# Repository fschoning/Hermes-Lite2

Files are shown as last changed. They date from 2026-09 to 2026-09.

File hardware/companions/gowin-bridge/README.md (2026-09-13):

# gowin-bridge — Hermes Lite 2 SlimSAS bridge, rev D

**One design with two ends, on one board.** One schematic, one PCB, one BOM,
one project directory. The **radio end** plugs onto the Hermes-Lite 2; the
**Gowin end** plugs onto a Tang Mega 138K dock's J14. They are made together
and snapped apart. Two radio ends and one cable make a radio-to-radio link; a
radio end, a Gowin end and one cable make a radio-to-FPGA link.

The radio end:
A flat companion board that plugs onto the HL2's **DB1** (2×10), **DB12** (2×3)
and **CN1** (2×5 JTAG) headers and carries **one SlimSAS SFF-8654 8i
receptacle** on its front edge. A single $15 cable carries 16 differential
pairs and 16 sideband conductors.

| | |
|---|---|
| Board | radio end **64.50 × 64.88 mm**, 4 layer, 1.6 mm, HASL. HL2 x 70.00→134.50, y 73.37→138.25. The whole board, both ends, is **64.50 × 92.00 mm**, no rails, the ends joined by three mouse-bite tabs |
| Underside | 11.04 mm above the HL2's top surface (10.92 mm measured on the owner's radio), on 2.54 mm sockets and one M3 screw; holes over the radio's FPGA, AD9866 and T2 |
| Connector | Amphenol ICC **U10A474240T**, LCSC **C5432262** |
| Cable | 10Gtek **CAB-8654/8654-8i-P**, 8i to 8i, 0.5 m, **$15** |
| Lane rate | DDR at 153.6 MHz = **307.2 Mbit/s**, three lanes each way |
| Payload | **921.6 Mbit/s** each way = the complete raw 12-bit 76.8 MSPS ADC stream, plus a full-duplex auxiliary channel at the same rate |
| Parts | both ends: 184, of which **152 fitted**; 176 nets; **24 placed part numbers**, 16 Basic, 7 Extended and 1 Preferred Extended; eleven test points |
| Cost | **$162.43** for five assembled boards, both ends, delivered: **$32.49 per complete link** |
| State | schematic generated and validated; **prepared for Quilter**: fixed parts locked, everything else waiting off the board (`QUILTER.md`); **not placed, not routed** |

---

## The documents, and which to read first

| | |
|---|---|
| **`STATUS.md`** | **Start here.** What is built, what changed from rev C and why, the four numbers that were blocking the order, three corrections to the brief, six deliberate departures from it, everything unverified, and the next steps in order |
| `PINMAP.md` | **The pin contract.** Every HL2 header pin, all 74 connector contacts, the crossover, the lane and sideband maps, the AUXIO group, the enables, and the paste-ready Quartus block. Authoritative; `tools/check_netlist.py` asserts it |
| `DESIGN_NOTES.md` | Why, with the numbers. Data rates, the 2.5 V threshold problem and the part that does not exist, termination and edge rates, **the power budget**, **the ESD decision**, the mechanical argument, parts sourcing, the JTAG contention answer, and everything unverified |
| `COST.md` | The order total in the categories the fab actually bills, what could be cut and what it saves, and what is not verified in the numbers |
| `ROUTING.md` | The routing rules for whoever lays this out, in the order they matter |

---

## Files

```
bridge/                 the ONE KiCad project
  bridge.kicad_sch      schematic, ERC 0 violations
  bridge.kicad_pcb      fixed parts locked, the rest staged off the board;
                        placement regions and keepouts; DRC 0, parity 0
  bridge.kicad_pro      project file, with the differentialpair and Power
                        net classes
quilter-upload/         the three KiCad 10 files to upload to Quilter
  bridge-bom.csv        BOM with LCSC numbers and a Populate column
  gowin-bridge.kicad_sym, gowin-bridge.pretty/   project-local libraries
templates/              1:1 print templates for offering up to the radio
panel-endcap/           the re-cut front end panel - SEE THE WARNING BELOW
tools/
  gen_gowin_bridge.py   generates everything above from one netlist description
  check_netlist.py      asserts the pin maps, the crossover and the safety props
  check_geometry.py     asserts the locked parts, the land patterns and,
                        on a returned board, the placement and routing rules
  cost_model.py         computes the order total from the generated BOM and PCB
  kisexp.py             the KiCad s-expression reader/writer
```

**Anything that changes a net must be changed in `tools/gen_gowin_bridge.py`
and regenerated, never hand-edited in the KiCad files, and `PINMAP.md` must be
updated in the same commit.**

## To rebuild and validate

```
cd hardware/companions/gowin-bridge
python tools/gen_gowin_bridge.py
python tools/check_geometry.py     # must print OK
python tools/check_netlist.py      # must print OK
python tools/cost_model.py         # the order total
# bridge/bridge.kicad_dru is picked up by DRC: fast nets 3 mm from every edge

set KC=C:\Users\franz\AppData\Local\Programs\KiCad\10.0\bin\kicad-cli.exe
%KC% sch erc --severity-error -o bridge/bridge-erc.rpt bridge/bridge.kicad_sch
%KC% pcb drc --severity-error --schematic-parity --refill-zones ^
     -o bridge/bridge-drc.rpt bridge/bridge.kicad_pcb
```

---

## The front end panel

`panel-endcap/panel-endcap.kicad_pcb` (55 mm case, rev C) has the SlimSAS
opening at **panel x 120.30–144.30 = HL2 y 107.30–131.30**, centred on the
connector, 24.00 × 10.40 mm at 12.39–22.79 mm above the HL2's top surface.
Nine stock vent holes had to go where the opening landed; nine were put back
above it on 13 Sep 2026, so the vent area is the stock 73.7 mm². Order it
separately as a bare PCB. `G:/proj/Hermes-Lite2/franz-claude-analysis/HL2_END_PANEL.md`
has the derivation, clearances and strength check.

**Not compatible:** the repo's DB9 adapter board (`hardware/companions/db9/`)
cannot be fitted with this board; its wires land on DB1 pins our socket
covers. Run a Hardrock-50 from the N2ADR HL2 IO board instead
(`DESIGN_NOTES.md` §14.7).

## The Gowin end

A passive board: the same SlimSAS connector, 12 ESD arrays, 9 resistors and a
hand-fitted 2×18 onto J14 positions 5–40. Bank 4 of the Gowin FPGA drives and
receives true LVDS at its 3.3 V supply. Placed at the 40 mm case position.
`PINMAP.md` §11, `DESIGN_NOTES.md` §11, `gowin_end_j14.cst`.

## To order

JLCPCB, **Economic** assembly, **5 boards**, 4 layer, 1.6 mm, lead-free HASL,
green, 1 oz, delivered as a single PCB with the tabs unbroken. It is one
64.50 × 92.00 mm board with one outline and no rails; the two ends are joined
by three mouse-bite tabs. Ask JLCPCB first whether that counts as one design
(`DESIGN_NOTES.md` §13.2). Do not buy impedance control — `COST.md` §4 explains why.
`COST.md` §1 is the line-by-line.

Then hand-solder, per board: the DB1 2×10 socket and the DB12 2×3 socket and
the CN1 2×5 socket on the **underside**, the JTAG pass-through 2×5 header on
the **top**, and **the connector's four 2.2 mm shell tails**.

**Before any of that, buy one cable and ohmmeter it.** The whole one-design
argument rests on the cable crossing row A onto row B, and 10Gtek publish no
wiring diagram for this part. `STATUS.md` has the test.

**And do not fit or remove the board with the radio powered** — the hot-plug
inrush is about 22 A for 3.3 µs. It is on the silkscreen.

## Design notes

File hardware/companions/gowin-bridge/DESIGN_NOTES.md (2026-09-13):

# gowin-bridge design notes, rev D

Why the design is the way it is, with the numbers. `PINMAP.md` is the pin
contract; this is the reasoning. **One design with two ends on one board**:
the radio end (sections 1-10) and the Gowin end (section 11). One schematic,
one PCB, one BOM. rev C's three HDMI cables and riser are in git history.

---

## 1. Data rates and unit intervals

| | Value |
|---|---|
| AD9866 sample rate | 76.8 MSPS, 12 bits |
| Raw stream | **921.6 Mbit/s** |
| Lanes per direction | 3 data + 1 clock |
| Lane rate | DDR at 153.6 MHz = **307.2 Mbit/s** |
| Unit interval | **3.2552 ns** |
| Both directions | simultaneously, on their own forwarded clocks |
| Auxiliary channel | one more clock and one more data lane each way, also 307.2 Mbit/s, also simultaneously |
| Driver rating | DS90LV047A fMAX 200 MHz min / 250 MHz typ, i.e. 400 Mbit/s — **77 % of rating** |
| Translator rating | SN74AVC4T245 380 Mbit/s at these rails — **81 % of rating** |
| LVDS transition time | about 1 ns, so **31 % of a unit interval** |

Both the 77 % and the 81 % are worth a scope check at bring-up. They are
unchanged from rev C, because rev C already ran every lane at this rate.

### 1.1 What is still unverified about the rate

Whether the Cyclone IV C8 fabric can capture 307.2 Mbit/s DDR on ordinary
bank-6 inputs. The device has one input register per IOE, so DDR input needs
soft logic clocked at 153.6 MHz. This gates every received lane. It is a
gateware and timing-closure question, not a board question, and no board change
can fix it if the answer is no.

---

## 2. The 2.5 V threshold, and the part that does not exist

### 2.1 The problem, with the numbers

| | Value | Source |
|---|---|---|
| Cyclone IV 2.5 V output, VOH min | **2.0 V** at IOH = −1 mA | Cyclone IV Device Datasheet CYIV-53001-1.8, Table 1-15 |
| DS90LV047A input VIH min | **2.0 V** | TI SNLS044D, Electrical Characteristics |
| **Guaranteed margin** | **0 mV** | |

Every 2.5 V-bank signal that originates at the HL2 and has to reach an LVDS
driver hits this: the three ADC data lanes and the auxiliary transmit pair.
It is the main signal path, not an edge case.

### 2.2 The 2.5 V LVDS driver was looked for properly. It does not exist.

The obvious fix is to power the LVDS driver from 2.5 V, whereupon its input
threshold would become about 0.7 × VCC = 1.75 V and the HL2's guaranteed 2.0 V
would have 250 mV of margin with no translator at all. That would delete three
chips and a divider. It was chased before anything else was decided.

**There is no quad CMOS-in / LVDS-out driver and no quad LVDS-in / CMOS-out
receiver specified from a 2.5 V supply, from any manufacturer, in any package,
at any price, that can be bought.** Two reasons:

1. Every quad LVDS line driver and receiver ever made runs 3.0–3.6 V. All 253
   parts in LCSC's LVDS category were swept; **not one has a supply range
   starting below 3.0 V.**
2. **Lowering the supply would not lower the threshold anyway.** These parts
   specify VIH = 2.0 V and VIL = 0.8 V as absolute TTL levels, not as a
   fraction of VCC. TI's own application note **SNLA307** exists to say so:
   "most LVDS drivers and receivers available on the market have 3.3-V supplies
   and only support 3.3-V LVTTL/LVCMOS signals", and its recommended fix is
   exactly a `SN74AVCxx45` translator in front of a 3.3 V driver.

Parts that genuinely are specified at 2.5 V, and why none of them helps:

| Part | What it is | Why not |
|---|---|---|
| TI SN65LVDS1 | single driver, 2.4–3.6 V, real 2.5 V spec | **VIH still 2.0 V.** Buys nothing. Four of them cost more than one quad plus a translator, in four times the area |
| TI SN65LVDS2 | single receiver, 2.4–3.6 V | single channel |
| TI SN65LVDS4 | single receiver with a separate 1.8/2.5/3.3 V output supply, fully specified at VCC = 2.5 V | single channel, and LCSC holds 34 pieces |
| TI CDCLVD1204 | fully 2.375–2.625 V | needs an external threshold reference on a complementary pin, i.e. the resistor divider this was meant to remove |
| ST RHFLVDS41 | **a real 2.3–3.6 V quad LVDS driver, announced February 2026** | space-qualified, ceramic Flat-16, QML-V, four-figure unit price, months of lead time, no distributor. It exists; you cannot have it |
| TI SN75LVDS83B | the only catalogue LVDS transmitter with a **guaranteed 1.65 V** input threshold, from a separate IOVCC pin (SLLS846C table 7.3) | it is a 28-bit 7:1 serializer, not a 4-channel driver, and −10 to +70 °C |

Also checked and all 3.0–3.6 V with 2.0 V thresholds: SN65LVDS047/048,
SN65LVDS31/32, SN65LVDS3486/3487, SN65LVDS9637/9638, SN65LVDS389/388A,
SN65MLVD, DS90LV031A/032A, DS90LV011A/012A, DS90LV004, the whole onsemi FIN
family (FIN1027/1028/1031/1032/1047/1048/1101/1102/1108, titled "3.3 V LVDS"),
ADI ADN4661–4668 and ADN4696/4697, Maxim MAX9111/9112/9121–9124/9173–9176,
Pericom PI90LV047/048, ROHM BU90LV047A/048, ST STLVDS47B, Runic RS90LV047,
Relmon MS90C032/385B/386B, 3PEAK TPT9H221, LKI8010/8011/8012. Renesas/IDT's
2.375–2.625 V parts are clock fanout buffers with differential inputs, not
CMOS-to-LVDS drivers. LTC1685/1686 are 5 V RS-485 parts, not LVDS.

### 2.3 So the translator stays, and what it costs

**U1 and U2 are SN74AVC4T245PW (LCSC C81461), VCCA = 2.5 V, VCCB = 3.3 V, both
DIR tied to VCCA, both OE* to ground.**

| | Value |
|---|---|
| A-side VIH min | **0.65 × VCCA** |
| At VCCA = 2.5 V nominal | 1.63 V → **370 mV of margin** over the HL2's 2.0 V |
| At VCCA = 2.55 V, the LDO's +2 % corner | 1.66 V → **340 mV**, the number to design to |
| At VCCA = 2.375 V | 1.54 V → 460 mV |
| B-side output | 3.3 V CMOS into the driver's 2.0 V threshold, 1.3 V of margin |
| Rated data rate | 380 Mbit/s; fastest signal through it 307.2 Mbit/s = **81 %** |
| Propagation delay | about 0.1 to 2.9 ns over the process and temperature table |
| Quiescent | ICCA and ICCB **8 µA max each** |

**The forward clock goes through the same package as its three data lanes.**
That is U1: four channels, exactly the forward group, nothing else. Propagation
delay is a part-to-part property, so putting them in one package turns a 2.6 ns
part-to-part uncertainty into a channel-to-channel one. The auxiliary clock and
data share U2's port 1 for the same reason.

**The forward clock is the awkward one, because FPGA pin 98 is a 3.3 V bank pin
and the translator's A-side absolute maximum is VCCA + 0.5 V = 3.0 V.** It
arrives through a divider:

| | Value |
|---|---|
| Divider | **100 Ω series + 470 Ω shunt**, both JLCPCB Basic parts |
| High level | 3.3 × 470/(470+100+50) = **2.50 V** |
| Worst corner (3.465 V rail, 2.45 V VCCA → 2.95 V absolute max) | 2.63 V — **320 mV of headroom** |
| Margin over VIH 1.63 V | **870 mV** |
| Current from pin 98 | 3.3 / 570 = **5.8 mA**, so set that pin to its 8 mA drive strength |
| Thevenin impedance | 100 ∥ 470 + 50 = **132 Ω** |
| Edge into the translator's ~4 pF | **0.53 ns** |
| Low level with the HL2 FPGA unconfigured | pin 98 carries LED D2 and R71, 1 kΩ to +3V3, so it sits at 1.4 V behind 1 kΩ: 1.4 × 470/1570 = **0.42 V** against the 0.875 V VIL limit |

rev C used 100 Ω + 660 Ω as two 330 Ω resistors because 470 Ω was not then a
Basic part in JLCPCB's library. It is now (**C25117**), so this is one resistor
instead of two, with better margin at every corner and 130 mV more headroom
under the absolute maximum.

**Pull-downs.** Every 2.5 V-bank net into U1 and U2 gets a 10 kΩ pull-down so
it is defined while nothing drives it. **The forward clock deliberately does
not**: its own LED pull-up plus the divider already define it at 0.42 V, and
adding 10 kΩ would park the node in the translator's forbidden band between
VIL 0.875 V and VIH 1.63 V.

### 2.4 And the other direction: 3.3 V into the HL2's 2.5 V input-only pins

HL2 PIN_88 (DB12-6), PIN_89 (DB12-5) and PIN_87 (DB12-2) are in a 2.5 V bank
with the PCI clamp diode on by default, and 88 and 89 are input-only. A 3.3 V
driver held high would inject DC into the radio's 2.5 V rail. **U3 is a third
SN74AVC4T245 with VCCA = 3.3 V and VCCB = 2.5 V**, carrying the two candidate
reverse clocks in port 1 and the auxiliary receive pair in port 2.

A resistor divider was rejected on the same numbers as in rev C: DS90LV048A
specifies VOH only to 2.7 V at −0.4 mA and VOL 0.25 V at 2 mA, so it cannot
drive a divider light enough to resolve a 3.2552 ns unit interval.

**The three transmit data lanes need no translation** — DB1 pins 11, 15 and 17
are 3.3 V-bank pins — so the receiver output drives them through a 0 Ω link on
0402 pads, with 22 Ω available if damping ever helps.

### 2.5 The option that would delete all three translators, for the record

The Cyclone IV can drive true LVDS on the output pins of its row I/O banks and
emulated LVDS (three external resistors) anywhere, with VCCIO = 2.5 V, which
these banks already run at. That deletes both the translators and the driver
chips. It needs the pins brought out to DB1 and DB12 to be assignable as
adjacent differential pairs, and they are not: 76, 77, 83, 85, 86 and 98 are
scattered across two banks and two headers. Recorded so nobody has to
rediscover it. rev C's `PINMAP.md` §5.3 examined the same idea.

---

## 3. Termination, edge rates and the tight paths

* **Every received pair gets a 100 Ω differential resistor**, eight in all,
  **within 5 mm of the receiver pins**. There is no termination at a driver
  output, which is correct for LVDS.
* **LVDS swing** 250–450 mV (VOD1 into 100 Ω), common mode 1.125–1.375 V.
* **The cable is not the limit.** SFF-8654 8i cable is **twinax** construction,
  32 AWG, 100 Ω, qualified to 24 Gb/s per channel for SAS-4. 307.2 Mbit/s is
  two orders of magnitude below that. The 400 Mbit/s driver rating is the
  limit, not the cable, and a metre is fine.
  **On the word "unshielded":** the phrase that appears on cable listings comes
  from the connector standard's own title, *0.6mm 4/8X **Unshielded** I/O
  Connector*, and from Amphenol's own connector page — "Designed for
  unshielded, internal or external I/O connectors". It describes a connector
  with no metal shroud, not a cable with no shield. 3M's equivalent product is
  literally named "SlimLine **Twin Axial** Cable Assembly (SFF-8654)", and
  10Gtek's own family datasheet is titled "SAS Slimeline **Twinax** Cable".
  What is **not** confirmable from any openable document is the layer-by-layer
  shield stack-up — foil per pair versus overall foil plus braid, and the
  drain-wire count. If a formal EMC case ever needs that, ask 10Gtek or cut one
  open.
* **Every single-ended HL2 net is under 25 mm** by layout rule. The floor plan
  in section 6 is built around that.
* **Impedance:** the connector is specified 85 Ω ±10 differential and the
  chosen cable SKU is 100 Ω. An 85/100 mismatch is a 8 % reflection
  coefficient, which at 307.2 Mbit/s is irrelevant. JLCPCB Economic gives no
  impedance guarantee, so aim the board for 100 Ω differential and accept it.

### 3.1 Tight path one: the three transmit lanes into the HL2's LED pins

DB1 pins 11, 15 and 17 are FPGA pins 99, 100 and 101, and each carries an LED
whose anode goes through 1 kΩ to +3V3 (D3/R72, D4/R73, D5/R74, verified in
`hermeslite.net`).

* **The receiver must sink 1.4 mA** when low: (3.3 − 1.9)/1000. DS90LV048A
  specifies VOL ≤ 0.25 V at IOL = 2 mA, so it is inside spec with the LED lit.
* **The LED does not load the edge.** Its junction capacitance (20–50 pF) is in
  *series* with the 1 kΩ, so at 150 MHz that branch is resistive. What loads
  the edge is the FPGA pin (about 7 pF for a right-side Cyclone IV pin) plus
  the header and trace, roughly 12–15 pF.
* A 3.3 V CMOS output with about 50 Ω of effective source impedance into 15 pF
  gives a 10–90 % rise of about **1.65 ns, which is 51 % of the unit
  interval.** That works, and it is the tightest margin on the board.
* The series parts are **0 Ω by default on 0402 pads**, so a damping value can
  be substituted without a respin — but do not raise them much: at 22 Ω the
  rise grows to about 1.9 ns.

### 3.2 Tight path two: nothing, and that is the change from rev C

rev C's second tight path was FPGA pin 80, the VREF pin with ~21 pF of stray
capacitance, carrying a bidirectional auxiliary lane at 1.49 ns of edge. In
rev D pin 80 carries a **DC enable level** and nothing else, so the 21 pF is
irrelevant and the path is gone. Pin 72, whose uFL stub at CL8 and unadjustable
sampling phase were the other worry, likewise carries only a DC level.

---

## 4. Power. This is the number that was blocking the order.

### 4.1 What the board draws

Every figure below is either a datasheet maximum or a computed
`I = (Cpd + CL) × V × f`. Where a datasheet publishes no guaranteed number, it
says so.

**On the 3.3 V rail:**

| Load | Current | Where it comes from |
|---|---|---|
| U4, U5 — two DS90LV047A quad drivers | **80 mA** (40 each) | SNLS044D: ICC no load 8 mA max, ICC loaded static (RL = 100 Ω on all four) **30 mA max**. TI publishes **no guaranteed switching ICC** — only Figure 24, whose "All Switching" curve rises to about 35–38 mA. 40 mA is the design figure and it is above the only guaranteed number there is |
| U6, U7 — two DS90LV048A quad receivers | **80 mA** (40 each) | SNLS045C: ICC no load 15 mA max; four outputs into ~10 pF at 153.6 MHz add 4 × 10p × 3.3 × 153.6M = 20 mA. Again no guaranteed switching ICC, only Figure 21 at about 40 mA |
| U1 — forward group translator, B side | **47 mA** | 4 channels × (CpdB 15 pF + 8 pF of load) × 3.3 V × 153.6 MHz. Cpd from SCES576I Table 5.6 |
| U2 — auxiliary translator, B side | **23 mA** | 2 switching channels, same arithmetic. The two enable channels are static |
| U3 — reverse translator, A side | **4 mA** | 4 channels × CpdA 2 pF × 3.3 V × 153.6 MHz |
| U8–U11 — the AUXIO and JTAG buffers | **12 mA** | dominated by TCK at 24 MHz, and only while programming; the AUXIO lines are DC to 400 kHz |
| The whole 2.5 V rail, through U12 | **50 mA** | see below. An LDO passes its output current straight through |
| Presence assert, 1 kΩ | **0.3 mA** | |
| Pull-ups, pull-downs, the divider | **3 mA** | |
| Quiescent: 7 × SN74AVC4T245 at 8 µA, U12 at 40 µA, 12 ESD arrays | **<0.1 mA** | |
| **Total** | **299 mA** | |
| **Design figure** | **350 mA** | |

**On the 2.5 V rail, which the board makes itself:**

| Load | Current |
|---|---|
| U3 B side: three switching channels × (CpdB 14 pF + 12 pF of HL2 pin and trace) × 2.5 V × 153.6 MHz | **30 mA** |
| U3 B side: the duplicate-clock channel driving an open pad (~3 pF) | **6.5 mA** |
| U1 A side: 4 × CpdA 2 pF × 2.5 V × 153.6 MHz | **3.1 mA** |
| U2 A side: 2 switching channels | **1.5 mA** |
| **Total** | **41 mA** |
| **Design figure** | **50 mA** |

### 4.2 What the radio can actually spare

Traced through `hardware/hl/Power.sch`, `hermeslite.net` and
`hermeslite.kicad_pcb` on schematic revision **2.0-build9**.

**+3V3 — one regulator for the whole radio.**

| | |
|---|---|
| Regulator | **U3, ST1S10PHR** synchronous buck, HSOP-8, **no heatsink** (the only two heatsinks on the radio are HS2 on the FPGA and HS7 on the AD9866) |
| Input | VSUP, 11–16 V, after the 3 A PTC fuse F1 and reverse-polarity FET Q1 |
| Chip rating | **3.0 A** |
| Output inductor | **L1, SRR4528A-3R3Y, rated 2.4 A** — the real hardware ceiling |
| Set point | R11 35.7 k / R12 11.5 k → 0.8 × (1 + 35.7/11.5) = **3.28 V** |
| **The designer's own annotation beside it on Power.sch** | **"<=1.5A"** |
| There is **no second 3.3 V regulator** | the Ethernet PHY and the FPGA share this one |

Existing load on it, bottom-up. The four largest are estimates and are labelled
as such:

| Consumer | Current | Basis |
|---|---|---|
| U7 AD9866 codec, all four 3.3 V domains (via FB17–FB20) | 150 mA | **estimate** from its ~0.4–0.6 W class at 76.8 MHz |
| U4 KSZ9031RNX PHY, AVDDH (via FB10) | 60 mA at 1 Gb | **estimate** |
| FPGA VCCIO banks 1, 2, 6, 7, 8 | 45 mA | **estimate**, dominated by the AD9866 DDR bus |
| U6 5P49V5923 VersaClock (via FB23–FB26) | 50 mA | **estimate** |
| X2 38.4 MHz oscillator (via FB12) | 15 mA | estimate |
| U17 TPS73025, i.e. the whole 2.5 V rail | 100 mA | see below |
| Magjack LEDs, R133/R134 = 270 Ω | 9.6 mA | **calculated** |
| Front-panel LEDs D2–D5, R71–R74 = 1 kΩ | 5 mA all on | **calculated** |
| Flash, MAX11613, MCP4662, MCP9700, PE4259, pull-ups | 8 mA | estimate |
| K2 TR relay coil | **0 mA** — PA.sch says the assembly house does not fit it | |
| **Total** | **≈ 450 mA** (range 350–600) | |

| Against | Spare |
|---|---|
| the ST1S10's 3.0 A | 2.55 A |
| L1's 2.4 A | 1.95 A |
| **the designer's own 1.5 A note** | **≈ 1.05 A** ← use this one |

**This board's 350 mA is 33 % of that spare.** Even at the pessimistic 600 mA
of existing load the spare is 900 mA and the board is 39 % of it. The rail
total becomes about 800 mA against a 2.4 A inductor.

**The copper is not the limit either.** DB1 pins 19/20 have **no series element
whatever** — no bead, no resistor, no fuse, no TVS — between L1 and the header.
The narrowest segment of that path is **1.25 mm on an external layer with no
plane** (+3V3 has no zone anywhere on the 4-layer radio), which IPC-2221 puts
at **2.8 A at a 10 °C rise**. One 0.5 mm via in the path is worth 2–2.5 A.

**2.5 V — and this is why the board makes its own.**

| | |
|---|---|
| Regulator | **U17, TPS73025DBVR**, a fixed 2.5 V LDO in **SOT-23-5**, fed from +3V3 |
| Rating | **200 mA total** |
| **The designer's own note** | **"150 mA sufficient for all 2.5V use"** |
| What it already feeds | FPGA VCCA1–VCCA4 (the four PLL supplies, via FB5–FB8) ≈ 12 mA; **net Veth** via FB30 = the KSZ9031's DVDDH RGMII I/O supply plus FPGA VCCIO banks 3 and 4 ≈ 55 mA at 125 MHz DDR; **net Vlvds** via FB28 = FPGA VCCIO **bank 5** plus DB1 pins 7/8 ≈ 8 mA; and FPGA pin 96, the MSEL1 configuration strap |
| Existing total | **≈ 75 mA** (range 45–135), every component of which is an estimate |
| Spare | **50 mA safely, 100 mA plausibly, 125 mA as an absolute ceiling** |
| FB28, the bead in the DB1 path | **TDK MPZ1608S601ATA00**, 600 Ω at 100 MHz, **1 A**, ≤200 mΩ. Not the limit — the 200 mA LDO binds first. What it does cost: every milliamp the board takes drops across 200 mΩ on the **shared** side, pulling down the FPGA's own VCCIO5 |
| Copper from FB28 to DB1 7/8 | 0.7 mm on B.Cu, ~19 mm, no vias → 1.85 A at a 10 °C rise. Not the limit |

**Verdict: fit the on-board LDO.** This board's 50 mA is the *whole* of the
radio's conservative 2.5 V headroom, that headroom figure is a bottom-up
estimate with wide error bars, and the rail it would brown out is **VCCIO5, the
bank that carries the ADC data this board exists to read**. So:

* **U12, ME6211C25M5G-N (LCSC C194395), 2.5 V 400 mA LDO, FITTED.** Fed from
  the board's own +3V3. 0.8 V of drop × 50 mA = **40 mW**, and 8× of current
  headroom. Output tolerance ±2 %, which is where the 340 mV threshold margin
  in section 2.3 comes from.
* **`SL_VLVDS` and `FB2`, NOT FITTED**, are the alternative: tie the 2.5 V side
  to the radio's own Vlvds instead. Electrically ideal, because the thresholds
  then track the FPGA bank supply exactly. Do not fit them together with U12.
  Measure Vlvds under load before trusting it.

It costs $3.07 in a feeder fee and six cents in silicon. That is cheap
insurance against browning out the rail you are reading.

**There is no 5 V, 12 V or unregulated supply on DB1 or DB12.** DB1 offers only
+3V3 (pins 19/20), 2.5 V (7/8) and ground (13/14); DB12 offers ground (3/4) and
four signals and no power at all. Raw power exists only on DB7, the filter-board
edge header, which this board does not reach.

**There is no published limit on what an expansion board may draw from DB1.**
Searched every schematic text note, the Sphinx documentation dump and every
`.md` in the repository. The only numbers the design offers are the two Power.sch
annotations quoted above. For what it is worth, KF7O's own unreleased DB1
companion (`hardware/companions/io/io.sch`) carries the note "Optional
Regulator for 5-11V", i.e. it provisioned its own supply rather than living off
the header.

### 4.3 Inrush, and the one thing not to do

Bulk capacitance is deliberately modest — **10 µF per rail and no more**.

| | |
|---|---|
| Total on the 3.3 V side | 10 µF after FB1 + 10 µF before it + ~1.7 µF of 100 nF = **21.7 µF** |
| Total on the 2.5 V side, behind the LDO | 10 µF + 1 µF + ~0.5 µF = **11.5 µF** |
| **At power-up**, with the radio's ST1S10 soft-starting over about 1 ms | I = C dV/dt = 21.7 µF × 3.3 V / 1 ms = **72 mA** of charging current on top of the load. Nothing |
| **On hot plug**, inserting the board with the radio running | 3.3 V / (FB1's 50 mΩ + about 100 mΩ of trace and contact) = **about 22 A**, decaying with τ = 0.15 Ω × 21.7 µF = **3.3 µs**, total charge 72 µC |

**Do not fit or remove the board with the radio powered.** It is on the
silkscreen. That 22 A microsecond spike would dip the radio's 3.3 V rail, and
it is also why the bulk ahead of the filter is 10 µF and not 100 µF.

**Since 13 Sep 2026** a 100 µF tantalum (C29) sits on +3V3 **behind** the new
4.7 µH inductor L1 (§14.4). The inductor limits its charging to 0.7 A per
microsecond and its own 1.7 Ω ESR damps the rest, so the hot-plug spike above,
into the 10.1 µF ahead of FB1, is unchanged.

**FB1, BLM18PG121SN1D (LCSC C14709), 0603, 120 Ω at 100 MHz, 2 A, 50 mΩ**,
sits in the 3.3 V feed and drops **15 mV at 300 mA**. It keeps this board's
switching currents out of a rail that has no filtering of its own between the
regulator and the header. It is JLCPCB **Basic**, which matters: it is the only
Basic bead that combines ≥1 A with ≤150 mΩ. No Basic bead reaches 600 Ω at that
current, and 120 Ω is ample for a rail filter — the whole Basic range is four
parts and the other three fail on current or DC resistance.

---

## 5. ESD. Every conductor that leaves the enclosure.

**Decision: protect all of them.** 32 pair conductors plus all 16 sideband
conductors = **48**, in twelve 4-channel arrays.

| | |
|---|---|
| Part | **TPD4E05U06DQAR**, LCSC **C138714** |
| Capacitance | **0.5 pF per channel** |
| Standoff / clamp | 5.5 V / 6.5 V, unidirectional — right for 3.3 V logic and for LVDS at a 1.2 V common mode |
| Package | USON-10, 2.5 × 1.0 mm |
| Stock / price | 45,345 at LCSC, **$0.0698 at qty 10**, JLCPCB Extended |
| Count | **12 arrays**, 48 channels, 2 spare |
| Cost | **$0.84 per board** plus one $3.07 feeder fee |
| **Electrical cost** | 0.5 pF × 50 Ω = **25 ps** of added rise time on a 3.2552 ns unit interval, i.e. **0.8 %**. Free |

Placement rule: **within 5 mm of the SlimSAS contacts, on the connector side of
the terminations, the series resistors and the buffers, with the shortest
possible ground return.**

Why not something cheaper or bigger:

* **No ESD array of any channel count is Basic tier** in JLCPCB's library. The
  entire Basic TVS range is four SMA/SMB power diodes with 5–12 V standoff and
  unpublished (i.e. 100 pF class) capacitance. They would not clamp a 3.3 V
  line and would destroy a 307 Mbit/s lane.
* **The 6- and 8-channel parts are worse on every axis.** TPD6E004 is 1.6 pF
  per channel and TPD8E003 is **9 pF** — three to eighteen times over budget —
  and the 8-channel part costs 25 times more per conductor and has 61 pieces in
  stock.
* **SRV05-4 (C558418)** at $0.0248 would be the cheapest 4-channel option, but
  its I/O-to-ground capacitance is **0.8 pF**, over the 0.5 pF limit, and the
  in-stock part is a clone with 20 V clamping rather than the brand-name part's.
* **SP3012-04UTG (C2987148)**, 0.3 pF, DFN2510-10, $0.0388, is the better part
  on both capacitance and price and is recorded as the alternative. It was not
  taken because LCSC holds 4,021 against C138714's 45,345 and C138714 is
  already proven in this BOM.

---

## 6. Mechanical: the outline, and why the connector is not in front of DB1

### 6.1 The new outline

| | |
|---|---|
| Outline | **local x 0…64.50, y 0.07…64.95 = HL2 x 70.00…134.50, y 73.37…138.25** |
| Size | **64.50 × 64.88 mm**, 4 layers, 1.6 mm, HASL. The 0.07 mm off the HL2 y 73.30 edge was taken when the board had rails and had to fit 100.00 mm (§11.6); local coordinates are unchanged |
| Local origin | HL2 main-board (70.00, 73.30), so local x = HL2 x − 70.00 |
| Underside | **11.04 mm** above the HL2's top surface with the specified socket, top surface at 12.64 mm. **Measured 10.92 mm** with the socket on the owner's radio (§13.4) |
| Window in the board | **local x 43.30…57.00, y 39.50…53.00**, widened 13 Sep 2026 so HL2 jumper header DB6 is uncovered with 2.5 mm clear on every side (§13.3). It is part of one cut-out with the holes over the AD9866 and T2 (§13.1) |
| M3 anchor | a **3.4 mm U-notch open to the top edge**, centred on local x 3.00 |
| Locating peg | **1.1 mm unplated hole at local (4.04, 2.12)** = HL2 MH6 (74.04, 75.42) |

**Confirmed from `hermeslite.kicad_pcb`:** the board must reach **x = 134.50**
because CN1's two pad columns are at HL2 x **128.23 and 130.77** with a 1.85 mm
pad, i.e. copper to 131.70, plus the socket body. It may reach **y = 138.25**
and no further, because `HL2_MECHANICAL_ENVELOPE.md` §2.5 puts the extrusion's
internal clear width at HL2 y 41.75…138.25. And `HL2_MECHANICAL_ENVELOPE.md`
§12.4 confirms the corridor is clean: apart from CN1 itself at 8.54 mm, the
tallest thing in 54 mm of board between x 73 and 136 at y 75…100 is the FPGA at
1.60 mm.

**The M3 anchor had to become a notch.** HL2 MH2 sits at (73.00, 137.00) =
local (3.00, 63.70), only **1.25 mm** from the top edge, and the top edge
cannot move. A 3.2 mm hole centred 1.25 mm from an edge breaks out of it by
0.35 mm. So the screw passes through a U-notch instead: the screw head and
washer still clamp the board onto the 11.04 mm standoff, and with the connector
lying flat there is almost no tipping moment for it to resist anyway.
`check_geometry.py` recomputes the 1.25 mm and fails if it ever becomes big
enough for a plain hole.

**MH6, the 1 mm locating peg, is available in rev D and was not in rev C.**
With the connector moved away from that corner there is nothing in the way.

### 6.2 Why the connector moved along the front edge, and this is a hard finding

The obvious place for the receptacle is the middle of the front edge, inside
the 29.60 mm of panel that is free at board level (HL2 y 72.86…102.44, bounded
by the magjack and the clock SMAs). **It cannot go there.**

A right-angle SFF-8654 receptacle lands its contact pads **12.35 to 15.35 mm**
inboard of the board edge and its four shell tails **1.65 to 8.15 mm** inboard.
And in that y span:

* **DB12's six through-holes are at local x 13.50 and 16.04** — straight through
  the middle of a 0.60 mm pitch pad field.
* **DB1's twenty holes are at local x 4.04 and 6.58**, which collide with the
  shell tails: the tail column at x 5.15 is only 1.11 mm from DB1's x = 4.04
  column, and the tails' 23.26 mm span is not commensurate with DB1's 2.54 mm
  pitch, so no y offset clears both tails at once.

**No setback fixes it.** Pushing the connector inboard far enough to clear both
hole columns needs ≥ 16.4 mm, which puts the mating face about 6 mm behind the
panel where no plug can reach it.

**So the connector moves along the edge to local y 46.00 = HL2 y 119.30**, past
the far end of DB1. That works because **the panel opens out with height**:
§2.4 and §11.3 give 29.60 mm of clear width at board level but the full
96.50 mm of the extrusion's internal width above about 14 mm, and a connector
standing on this board's 12.64 mm top surface occupies **12.64 to 22.54 mm**
above the main board — entirely inside that band, and **above** the existing
clock-SMA and KEY-jack holes rather than beside them.

| | |
|---|---|
| Receptacle | local y 34.25…57.75 = **HL2 y 107.55…131.05** |
| Mated plug overmould, 25.95 mm (SFF-8654 Table 5-1, A03) | **HL2 y 106.33…132.28** |
| Against the extrusion's clear width 41.75…138.25 | **64.58 mm spare below, 5.97 mm above** |
| Plug thickness, 9.90 mm (Table 5-1, A13) | 12.64…22.54 mm above the main board |
| **Panel window** | **26.5 × 10.5 mm**, centred on HL2 y 119.30, from **19.6 to 30.2 mm above the enclosure's outer bottom face** (the PCB top surface is 7.30 mm up) |

What is underneath at that y: the two clock SMAs (CL1/CL2, HL2 x
74.04…78.24, y 103.36…123.60) and the 3.5 mm KEY jack (CN4, x 70.20…82.10, y
124.00…136.00). **Measured on the owner's radio at 4.24 mm and 5.12 mm**
(§13.4), so the 10.92 mm underside clears them by 6.68 and 5.80 mm.

**The floor plan this produces is better than rev C's, not worse.** The
translators and LVDS chips sit in local x 9…53, y 12…34, right beside DB1 and
DB12, so every single-ended HL2 net stays well inside §11.6's 25 mm rule; the
only long runs are the terminated 100 Ω differential pairs from the chips up to
the connector at y 34…58, about 25–35 mm over an unbroken ground plane, which
do not care.

### 6.3 What the flat board buys over rev C

| | rev C | rev D |
|---|---|---|
| Connectors for 12+ pairs | 3 × mini HDMI | **1** |
| Boot envelope required | 3 × 17.4 = 52.1 mm | **25.95 mm** |
| Upright riser section | required, 8–28 mm tall, right-angle soldered joint | **none** |
| Socket shell centre height | 22.0 mm | ~17.6 mm, and the board is flat |
| Insertion force | 44.1 N at a 22 mm shell height = 970 N·mm of tipping moment | **55.5 N** at a ~2.6 mm shell height, near zero moment |
| Designs to fabricate | 2, plus a panel | **1** |
| Mating cycles | 10,000 (HDMI) | **250 minimum** (Amphenol U10 series) |

That last row is the one real regression and the owner should know it in
advance: SlimSAS is a server-internal connector. 250 cycles is about one
insertion a week for five years, which is almost certainly fine for a radio,
but it is not a consumer port.

### 6.4 The land pattern, and the one dimension nobody publishes

Amphenol publish no recommended land pattern for U10A474240T and their
datasheet server refuses automated fetching, so the footprint is built from the
governing specification's own informative footprint: **SFF-8654 Rev 1.2 Figure
A-1 and Table A-1, "8X RIGHT ANGLE RECEPTACLE FOOTPRINT DIMENSIONS"**. Every
designator J01 to J12 is transcribed in the `SLIMSAS` block in
`tools/gen_gowin_bridge.py`, and `tools/check_geometry.py` recomputes all 78
pads from those twelve numbers independently and compares. Cross-checked
against **Foxconn customer drawing 303-0000-3299 sheet 4/5**, the "RECOMMEND
PCB LAYOUT" view for the 38-position sibling of the same LDL family, which
prints the identical construction and confirms that the shell tails sit
*outside* the locating holes and on the opposite side of the datum line from
the contacts.

**The one dimension that is in no document I could read** is the distance from
the locating-hole datum line to the front face of the latch shroud — i.e. how
far back the footprint must sit for the mating face to be flush with the panel.
Derived instead: the footprint spans 9.10 mm on the shell-tail side and 5.70 mm
on the pad side, 14.80 mm total, against a 15.80 mm body depth, so the body
overhangs the footprint by about 1.00 mm and the front face is about 10.10 mm
ahead of the datum. **The setback is set to 10.40 mm**, which puts the nominal
front face 0.30 mm behind the board edge and leaves 1.75 mm of copper-to-edge
clearance on the shell-tail pads. A 0.5 mm error here is absorbed by the panel
window, which is clearance-only and which the owner cuts himself — but
**check it against Amphenol's drawing before cutting the panel.**

---

## 7. Parts sourcing

**Every number was checked against a live LCSC page and against JLCPCB's
assembly library.** Eighteen part numbers are placed; twelve are Basic and six
are Extended.

| Function | Part | LCSC | Tier | Qty | $ @10 |
|---|---|---|---|---|---|
| SlimSAS 8i receptacle | Amphenol ICC U10A474240T | **C5432262** | Extended | 1 | 3.17 |
| Quad LVDS driver | DS90LV047ATMX/NOPB, SOIC-16 | **C206491** | Extended | 2 | 1.84 |
| Quad LVDS receiver | DS90LV048ATMTCX/NOPB, TSSOP-16 | **C87137** | Extended | 2 | 1.43 |
| Translator / buffer, **the only logic part number** | SN74AVC4T245PWR, TSSOP-16 | **C81461** | Extended | 7 | 0.3096 |
| ESD array, 0.5 pF | TPD4E05U06DQAR, USON-10 | **C138714** | Extended | 12 | 0.0698 |
| 2.5 V LDO | ME6211C25M5G-N, SOT-23-5 | **C194395** | Extended | 1 | 0.0561 |
| Ferrite bead | BLM18PG121SN1D, 0603 | **C14709** | **Basic** | 1 + 1 DNP | 0.0159 |
| 100 nF 0402 | | **C1525** | Basic | 22 | 0.0046 |
| 10 kΩ 0402 | | **C25744** | Basic | 19 | 0.0031 |
| 100 Ω 0402 | | **C25076** | Basic | 9 | 0.0037 |
| 330 Ω 0402 | | **C25104** | Basic | 8 | 0.0044 |
| 0 Ω 0402 | | **C17168** | Basic | 7 + 3 DNP | 0.0028 |
| 10 µF 25 V 0805 | CL21A106KAYNNNE | **C15850** | Basic | 3 | 0.085 |
| 470 Ω 0402 | | **C25117** | Basic | 1 | 0.0027 |
| 1 kΩ 0402 | | **C11702** | Basic | 1 + 1 DNP | 0.0022 |
| 1 µF 0402 | | **C52923** | Basic | 1 | 0.0097 |
| N-MOSFET, the AUXIO drive presence interlock Q1 | AO3400A, SOT-23 | **C20917** | Basic | 1 | 0.0853 at 5+ |
| 0 Ω 0805 | 0805W8F0000T5E | **C17477** | Basic | 1 + 1 DNP | 0.0045 |
| **Added 13 Sep 2026 (§14)** | | | | | |
| AO3400A, now Q1–Q6 | | **C20917** | Basic | 6 | 0.0853 |
| Schottky, link-alive detector | RB751V-40, SOD-323 | **C7502691** | **Preferred Extended, no fee** | 2 | 0.0148 |
| 10 pF C0G 0402 | CL05C100JB5NNNC | **C32949** | Basic | 1 | 0.0069 |
| 10 nF X7R 0402 | CL05B103KB5NNNC | **C15195** | Basic | 1 | 0.0035 |
| 100 kΩ 0402 | | **C25741** | Basic | 1 | 0.0028 |
| 4.7 µH shielded inductor | Sunlord SWPA4030S4R7NT | **C193025** | **Extended** | 1 | 0.0856 |
| 100 µF 6.3 V tantalum, case B | AVX TAJB107K006RNJ | **C16133** | Basic | 1 | 0.2574 |
| 10 nF X7R 0805, shell bonds | CL21B103KBANNNC | **C1710** | Basic | 2 DNP | — |

Since 13 Sep 2026: **24 placed part numbers, 16 Basic, 7 Extended with a fee,
1 Preferred Extended.**

**One part number for all seven translators and buffers, and that is a money
decision, not an aesthetic one.** JLCPCB's assembly library contains **no
Basic-tier buffer, driver, receiver or transceiver of any family from any
manufacturer** — the whole 244 octal family, the 125 and 126 quad families and
the entire Buffers/Drivers/Receivers category were swept, and the complete
Basic logic range turns out to be two chips: a hex Schmitt inverter and a shift
register. So every extra logic part number costs its own $3.07. Seven
SN74AVC4T245 cost **one** fee and $2.17 of silicon; a 74LVC244 plus a 74LVC125
would have cost **two** fees and $0.30 of silicon — $6.14 against $2.17.

**And no Basic quad LVDS part exists either.** 72 distinct LVDS driver and
receiver parts in JLCPCB's library, every one Extended, none even Preferred
Extended, and the Chinese brands hoped for (3PEAK, SGMICRO, Runic, Chipanalog,
Novosense, HGSEMI, Techcode, Belling, Shouding) carry no quad LVDS parts at
all. So C206491 and C87137 stay. One saving available and not taken:
**C87097**, the same DS90LV047A silicon in TSSOP-16 instead of SOIC-16, is
$0.43 cheaper each — $0.86 a board. SOIC-16 was kept for its thermal margin
(the drivers dissipate the most on the board) and its higher stock.

**The four parts the owner solders himself**, hand-fitted and not on the
assembly BOM, because every through-hole part is a distinct Extended part number
to JLCPCB:

| | Part | LCSC |
|---|---|---|
| DB1 2×10 female socket, bottom side | JXTCONN PM2.54-2X10P-H85 | C42431860 |
| DB12 2×3 female socket, bottom side | **LCSC has no vertical 2×3 socket at all** — their vertical female headers start at 2×4, and the 2×3 they list (C99515) is side entry, which cannot work on a socket that plugs straight down. Buy a 2×4 and cut it down | — |
| CN1 2×5 female socket, bottom side | PM254V-12-10P-H85 | C492399 |
| JTAG pass-through 2×5 male header, top side | PZ254V-12-10P, or DC3-2.54-10PAS (C2977596) for a keyed boxed header | C492422 |
| Ground clip 1×2 header | hanxia PH254 | C52016390 |
| **and the connector's four 2.2 mm shell tails**, which are through-hole on an otherwise SMD part | | |

---

## 8. The JTAG tap: series resistors or a buffer?

**Both, and the buffer is the part that matters.** The question was whether a
locally plugged USB Blaster and the remote path can fight.

**Series resistors alone are not enough.** They bound the current, but they
leave the logic level undefined, and an undefined TCK is exactly the thing that
can walk a TAP controller into an arbitrary state or corrupt a configuration in
progress. A gated buffer makes "the cable cannot touch CN1" a property of the
hardware rather than of the owner's memory:

| Line | Path | Gating |
|---|---|---|
| TCK, TMS, TDI | cable → **gated buffer** → 330 Ω → CN1 | OE* = `JTAG_EN_N`, pulled up at both ends, so **disabled with no gateware and with nothing plugged in** |
| TDO | CN1 → 330 Ω → **buffer input** (high impedance) → cable | on while a far end is present; reading TDO cannot fight the FPGA that drives it, and the cable never loads the FPGA pin. **As first built this buffer was backwards and drove the TDO pin; fixed, §14.1** |

So a USB Blaster in the local pass-through meets **a tri-stated output**, not a
driver, unless the gateware has deliberately enabled the remote path — and you
would only do that with no Blaster plugged in.

**The series resistors are still there and still earn their place:** 330 Ω
bounds a fight to about 8 mA if the enable is left on while a Blaster is
plugged in, and 330 Ω into the ~15 pF of CN1 plus trace is **5 ns** against the
**41.7 ns** period of a 24 MHz TCK, or 167 ns at the Blaster's 6 MHz default.
`HL2_MECHANICAL_ENVELOPE.md` §12.3's arithmetic still applies: the whole added
electrical length is worth 0.085 ns, which is 0.2 % of a TCK period, and the
Blaster's own 150–300 mm ribbon is a far larger discontinuity than anything
this board adds.

**Radio-to-radio is covered structurally, not by the enable.** Two sideband
positions are deliberately undriven so that no radio can reach another radio's
TCK or TMS at all. `PINMAP.md` §6.2 has the table and the proof, and
`check_netlist.py` asserts it.

**The tolerance warning, which is the real risk here.** J4 is the third rigid
2.54 mm socket on one board, 54.19 mm from DB1, and
`HL2_MECHANICAL_ENVELOPE.md` §12.2 puts the worst-case misalignment at CN1
relative to DB1 at about **±0.8 mm** against the **±0.35 mm** a 2.54 mm socket
takes comfortably and ±0.6 mm before pins bend. That analysis is unchanged and
it is a coin toss on a hand-soldered radio. **The fallback needs no board
change: leave J4 off and run a flying 10-way IDC ribbon from CN1 to J5**, which
carries the same ten nets. A flying ribbon absorbs any misalignment, and it is
what §12.2 recommends.

---

## 9. Deliberate departures from the brief

| Brief said | What was done | Why |
|---|---|---|
| the duplicate forward clock on a spare channel of the **same** driver chip | on the second driver, U5 channel 1 | a quad driver has four channels and the forward group is five signals. `PINMAP.md` §5.2 |
| JTAG on pairs 14–16 plus one more | JTAG on four **sideband** conductors | under the function-mirroring rule the 16 pairs are exactly eight mirrored full-duplex lanes, and seven are spoken for. JTAG's four lines do not fit, and at 24 MHz maximum a single-ended sideband is trivially adequate |
| FPGA pin 72 unused, so J25 need not be soldered | pin 72 carries a DC enable level | soldering J25 stays **optional**: leave it open and the AUXIO drive feature simply does not exist. `PINMAP.md` §8 |
| pins 90, 91, 103, 104 are "the four indicator LED pins" | the mechanism is built on those four pins, but they are CW/PTT and the clock-generator I2C bus | the LEDs are on pins 98–101, which the link already owns. `PINMAP.md` §7 |
| bidirectional translator channels with direction control | two one-way paths with an enable on the DRIVE path only | the READ path then physically cannot drive an HL2 pin, and there is no direction net whose halves could disagree |
| the Gowin end on J14 with 16 pairs | 14 pairs; the spare lane and the AUXIO lines are not wired at the Gowin end | the 40 mm case position puts J14 positions 1-4 under the connector, leaving 34 pins. §11.5 |
| a 7 mm or lower J14 stack | 7.5 mm as built, 7.0 mm with the header insulator removed | no stocked square-pin pair is lower. §11.4 |

---

## 10. Everything unverified, in one list

The ones that could stop the build are first.

| Item | Why it matters | How to settle it |
|---|---|---|
| **The cable's pin wiring** | The whole one-design argument rests on the A(n)↔B(n) crossover, and 10Gtek publish no wiring diagram for this part — not the product page, not the catalogue, not the datasheet. It is inferred from SFF-9402 plus two third-party drawings | **Ohmmeter the first cable.** Five minutes. Confirm a row A contact reaches the other row, same number, at the far end |
| **The connector's front-face setback** | The one land-pattern dimension in no readable document. 10.40 mm is derived, ±0.5 mm | Open Amphenol's drawing for U10A474240T, or measure a part. Then cut the panel window |
| **HL2 R17** | 100 Ω between the DB12 pin 5 and pin 6 nets; if fitted it shorts the auxiliary clock input to the reverse clock input. Not populated on the owner's radio | Look at the radio before plugging this in |
| **The +3V3 spare current** | The 450 mA existing load is a bottom-up estimate whose four largest terms are guesses. The conclusion (350 mA is a third of the spare) is robust even at the pessimistic end, but the number is not measured | Measure the radio's 3.3 V rail current with and without the board |
| **The 2.5 V spare current** | Every component of the 75 mA existing estimate is a guess, which is precisely why the board makes its own 2.5 V rather than relying on it | Measure Vlvds under load before ever fitting SL_VLVDS |
| **Whether the Cyclone IV C8 fabric can capture 307.2 Mbit/s DDR** | Gates every received lane. One input register per IOE, so DDR input needs soft logic at 153.6 MHz | Timing closure in Quartus, then a bench measurement |
| **The three-socket tolerance stack** | ±0.8 mm worst case at CN1 against ±0.35 mm comfortable | Print `templates/bridge-1to1-TOP-fit-check.pdf` at 100 %, measure its rule, offer it up. The fallback is the flying ribbon |
| **The cable's shield stack-up** | Confirmed twinax; the layer-by-layer construction is not confirmable from any openable document | Ask 10Gtek, or cut one open. Only matters for a formal EMC case |
| **The A1 end of the connector** | Which physical end carries contact A1 is not stated in anything readable | It cannot scrap the board — `PINMAP.md` §1.1 — but knowing it saves a gateware polarity inversion |
| **The exact assembly fee** | JLCPCB will not compute the solder-joint fee without a login and an uploaded position file, and two of their own pages disagree on the setup fee ($8.18 vs $8.00) and the per-joint rate ($0.0016 vs $0.0017) | Upload and look. It is a few dollars |
| **The Gowin-end M3 spacer** | Its hole is under the connector housing and 0.66 mm from the connector's locating-peg hole, so the spacer must be fixed from below and must fit a 3.2 mm hole | Choose the part before ordering. §11.3 |
| **Dock coordinates on rev 31005** | Every Gowin-end position comes from Sipeed's interactive BOM for dock rev 31004 | Measure J14 pin 1 and hole H7_LU1 on the dock in hand, or offer up the 1:1 template |
| **C55160396 stock** | The only 5.0 mm 2×18 socket found for the scheme 1 stack; 10 in stock | Buy early. §11.4 |
| **Whether CAB-8654/8654-8i-P carries all 16 sidebands** | Since §14.3 the radio end's LVDS drivers run only while presence reads HIGH over a sideband; a no-sideband cable leaves the link dead | the ohmmeter test above |
| **Whether an unpowered Gowin Bank 4 clamps** | decides how much the remaining 0.25 mA presence current matters | nothing to do; §14.3 already removed the rest |
| **L1 stock** | C193025 had about 2,000 in stock on 13 Sep 2026 | buy early, or use SWPA4020S100MT (C82398) |
| **Every noise ranking** | judgement until measured | §14.6 |
| **Gowin on-die termination at VCCIO 3.3 V** | Documented for the bottom banks with no voltage restriction, accepted by Gowin EDA, not yet measured | Seven not-fitted 100 Ω footprints are on the Gowin end as the fallback |

---

## 11. The Gowin end

The far end of the same design, on the Sipeed Tang Mega 138K dock. It is on the
same schematic, the same PCB and the same panel as the radio end, and is
snapped off it at three mouse-bite tabs. `PINMAP.md` §11 is its pin contract; this is the reasoning.

### 11.1 The question that set the cost: can Bank 4 do LVDS at 3.3 V?

**Yes, in both directions, with no parts.**

| Step | Finding | Source |
|---|---|---|
| What bank is J14 | Bank 4, a bottom bank | dock schematic net labels `BANK4_<ball>_<IO>`; `TANG_MEGA_138K_FACTS.md` §2.5 |
| Its VCCIO | **3.3 V**, generated on the SOM, fed through a filter and the board-to-board connector to VCCIO2/3/4/5 together. No jumper, no regulator option on the dock except an unfitted resistor from a dock 1.8 V rail | dock schematic **sheet 2/21, PWR_TREE** |
| LVDS output at 3.3 V | **Allowed.** LVDS25, "Differential (TLVDS)", Bank VCCIO **2.5/3.3**, drive 3.5/2.5/4.5/6 mA | Gowin **DS1239** 1.0.3E §2.3.1 **Table 2-1** |
| …and not only a table header | LVDS25 appears twice in the output VCCIO table: 2.375–2.625 V and **3.135–3.465 V** | DS1239 §3.2.3 **Table 3-10** |
| On which pins | All 143 differential pairs of the PG484A package are True LVDS Output | Gowin **UG1102** 1.0.8E §2.4.1 **Table 2-3** |
| LVDS input at 3.3 V | Allowed, VCCIO 1.0–3.3 V | DS1239 **Table 2-2**; UG304 1.3.8E §3.1 |
| Input termination | 100 Ω on-die, bottom banks of the 138K | UG304 §3.3.2; DS1239 §3.2.1 Table 3-8 note 1 |
| **The tool agrees** | Gowin EDA 1.9.11.03 Education, device GW5AST-LV138PG484AC1/I0, placed, routed and wrote a bitstream for the final pin map: LVDS25 inputs with Diff Resistor ON, LVDS25 outputs at 3.5 mA, BANK_VCCIO 3.3, no errors | run on this machine, 13 Sep 2026 |
| Corroboration | Sipeed's own HDMI transmitter on the same dock drives true LVDS pairs from 3.3 V Bank 3 at `DRIVE=3.5` | `tang_mega_138K_pins.cst` |

**So J13 and the "change Bank 4's VCCIO" options were not needed** and were
not pursued. Bank 2 (J13) would in any case have been worse: no on-die
termination, and it shares its bank with the Ethernet RGMII bus.

**Electrical compatibility with the radio end.** The Gowin LVDS25 output is
VOD 250–600 mV at VOS 1.000–1.425 V into 100 Ω (DS1239 Table 3-12); the radio
end's DS90LV048A accepts any differential input over 100 mV. The radio end's
DS90LV047A drives 250–450 mV at 1.125–1.375 V; the Gowin input threshold is
±100 mV. Both ends are DC-coupled and share ground through the cable's 26
ground conductors.

**What one tool run found that no document said.** Bank 4 is also the CPU and
SSPI configuration bank. Gowin EDA refuses five of the chosen balls unless the
project sets `-use_sspi_as_gpio 1` and `-use_cpu_as_gpio 1`. TCK is on N15,
the one chosen ball with no configuration function at all.

### 11.2 What is on the Gowin end

| Part | Qty | LCSC | Tier | Why |
|---|---|---|---|---|
| SlimSAS 8i receptacle | 1 | C5432262 | Extended, **already paid for by the radio end** | same part both ends |
| TPD4E05U06 ESD array | 12 | C138714 | Extended, **already paid for** | every one of the 48 conductors |
| 330 Ω 0402 | 4 | C25104 | Basic | TCK, TMS, TDI, TDO series |
| 1 kΩ 0402 | 3 | C11702 | Basic | presence out and in series, TCK pull-down |
| 10 kΩ 0402 | 2 | C25744 | Basic | presence and TDO pull-downs |
| 0 Ω 0805 | 1 | C17477 | Basic | shell to ground |
| 100 Ω 0402, **not fitted** | 7 | C25076 | — | optional external termination per received pair |
| 2×18 socket or header | 1 | see §11.4 | hand-fitted | onto J14 positions 5–40 |

**No new part number.** Every factory-placed part number on the Gowin end is
already on the radio end, so the Gowin end adds **no** $3.07 Extended-part
fee. Components come to **$4.04 per Gowin end**, $3.17 of it the connector.

### 11.3 Position: the 40 mm case position, which also serves the bench

From `franz-claude-analysis/TANG_IN_40MM_CASE.md`, in Sipeed's dock
board-file coordinates:

| | Dock coordinates | Why |
|---|---|---|
| SlimSAS mating face | **x 89.73**, facing the dock's short (Ethernet) edge | flush with the dock RJ45 face; both leave through the front panel |
| SlimSAS centreline | **y 53.73** | 10.11 mm from J14 pin 1 toward the PMOD edge |
| Board | x 89.43–153.93, y 41.17–66.29 = **64.50 × 25.12 mm** | 64.50 long, the radio end's width (it shared a straight V-score with the radio end until 13 Sep 2026, §13.2); 25.12 wide is the minimum that keeps both rows of shell-tail pads 0.30 mm inside the edges; y ≤ 66.5 keeps clear of the USB3 bridge and the core module |
| HDMI notch | x ≥ 148.50, y ≤ 57.50 removed | a cable can stay in the dock's HDMI socket J29 |
| M3 spacer hole | (97.67, 62.66), over dock corner hole H7_LU1 | the connector takes 55.5 N on insertion |
| J14 | positions 5–40 only | positions 1 and 2 are under the contact field, 3 and 4 under the housing |

**Two things the case position forces that the owner should know.**

1. **The spacer hole is under the connector housing.** Nothing can be
   screwed into it from above. The spacer has to be fixed to the adapter from
   below (a surface-mount threaded spacer, or a standoff bonded in place) and
   the screw comes up from under the carrier plate or case floor. The hole is
   0.66 mm from the connector's own locating-peg hole, so a spacer that needs a
   mounting hole larger than 3.2 mm will not fit; the common PEM-style SMT
   spacers want 4.2 mm. **Choose the spacer before ordering.** The hole is part
   of the Gowin end's copy of the connector land pattern, which is why DRC
   accepts a hole inside the connector's outline.
2. **The J14 PMOD pins, the camera and the two PMOD sockets are unusable**
   while the adapter is fitted: J14 positions 5–8 are PMOD0, 21–28 are PMOD1
   and the camera. In scheme 1 the adapter underside clears PMOD socket J9 by
   about 0.6 mm (its 6.4 mm height is an estimate).

**Height.** The tallest thing on the adapter is the SlimSAS at 9.90 mm. In
scheme 1 the seat is 8.6 mm (7.0 mm stack) or 9.1 mm (7.5 mm stack) above the
dock, so the connector top is at case height 33.3 or 33.8 mm against the
study's worst-case 36.9 mm ceiling: 3.6 or 3.1 mm spare. **The 7.5 mm stack
lowers nothing but moves the plug 0.5 mm up against a front-panel window with
0.3 mm of clearance: if the insulator is left on, the window must move up
0.5 mm.** In scheme 1 the upside-down header's 6.0 mm ends stand 4.4 mm above
the adapter before clipping, beside the connector, not over it.

### 11.4 The stack, and the search for a 7 mm one

A standard 2.54 mm male header plus female socket is 11.0 mm. LCSC was
searched for anything lower in 2×18 or 2×20:

| Candidate | Height | Stock | Verdict |
|---|---|---|---|
| **kinghelm KH-2.54FH-2X18P-H5.0, C55160396** | 5.0 mm female, square hole | **10** | **chosen for scheme 1**, with C41376109 upside down |
| chxunda XDM254C-2-18-Z-3.0-G0, C19184331 | 3.0 mm machined round-hole female | 66 | accepts only 0.40–0.60 mm round pins; no stocked 2×18 round-pin male found to mate it |
| XKB X5521FV-2x18-C70D30, C2682207 | 7.0 mm round-hole female | 170 | same round-pin problem, and 7.0 mm on its own |
| every 8.5 mm 2×18 female | 8.5 mm | thousands | scheme 2 |

**Scheme 1 is 7.5 mm as built, or 7.0 mm with the header insulator slid off**
and the spacer setting the height. **C55160396 has only 10 in stock: buy them
now if scheme 1 is chosen.**

### 11.5 The sidebands, and JTAG driven from this end

J14 has 38 usable pins; positions 1–4 remove four. Fourteen pairs take 28. The
remaining six carry presence in, presence out/link reset, TCK, TMS, TDI and
TDO. **The spare lane and the four AUXIO lines are not wired at this end** —
PINMAP.md §11.4 explains why nothing that works today is lost.

| Property the radio end has | Kept at the Gowin end by |
|---|---|
| Radio-to-radio cannot touch programming pins | untouched: the radio end still leaves A9 and A29 undriven |
| JTAG disabled at power-up by a pull resistor | the radio end's gated buffer and its pull-ups still decide; the Gowin can drive TCK/TMS/TDI but they reach the radio's CN1 only once the radio enables the path |
| No TCK edge from an unconfigured controller | **R105, 1 kΩ to ground on the FPGA side of TCK**: against the Gowin's strongest 400 µA configuration pull-up it holds 0.4 V |
| A fight is bounded | 330 Ω in every JTAG line at this end too |
| Unpowered end does not back-feed | 10 k in the presence input (1 k until 13 Sep 2026) and 330 Ω in TDO limit injection into an unpowered FPGA; the radio end's drivers, TDO and AUXIO buffers now run only while this end drives presence (§14.3) |

**Presence here is driven by the gateware** because J14 has no 3.3 V pin:
HIGH through 1 k is present, LOW is link reset. Since 13 Sep 2026 the radio
end's LVDS drivers, its TDO and AUXIO buffers and its link-alive gate all
follow this line (§14.3), so an unconfigured Gowin reading as absent keeps
the radio end quiet, which is the point. The Gowin gateware must likewise keep
its own outputs off until it reads presence HIGH.

### 11.6 One design on one board

| | |
|---|---|
| Board | **64.50 × 92.00 mm**, 4 layer, 1.6 mm, **one continuous Edge.Cuts outline** round both ends, **no rails** (§12.3); `check_geometry.py` asserts there is exactly one outer loop |
| Top to bottom | radio end 64.88 mm, a 2.00 mm slot bridged by three mouse-bite tabs, Gowin end 25.12 mm (§13.2). Until 13 Sep 2026 the Gowin end was on top, joined edge to edge at one V-score |
| The 0.07 mm | the radio end's edge facing the Gowin end is 0.07 mm in from its local y 0 (HL2 y 73.37), kept from when the rails had to fit in 100 mm |
| Connectors | both on the board's left edge, which is a routed outer edge, far from the tabs |
| Notches | the HDMI notch, the M3 U-notch and the notch over the radio's FPGA are notches in the outer outline; the first two open into the slot, away from the tabs |
| Electrical separation | every Gowin-end net is prefixed `G_`; `check_netlist.py` asserts that no net touches both ends; ground pours are per end |
| Designators | radio end as before; Gowin end numbered from 101 (J101, J102, D101–D112, R101–R117, TP101) |

**A pre-existing bug fixed on the way.** The committed rev D BOM carried two
R1s and two R2s: the generator named the forward-clock divider R1/R2 by hand
and also handed out R1 and R2 automatically to two 330 Ω AUXIO resistors.
JLCPCB's placement file cannot hold duplicate designators. The automatic
numbering now skips R1 and R2, so every automatically numbered radio-end
resistor moved up by two; no net changed.

---

## 12. Prepared for Quilter (13 Sep 2026)

### 12.1 What Quilter reads, and the sources

All read 13 Sep 2026.

| Question | Answer | Source |
|---|---|---|
| KiCad version | Not published. A user's upload only parsed after re-saving in KiCad 10 format; Quilter staff said they try to keep up with the latest KiCad. The upload files are KiCad 10, made by `kicad-cli pcb upgrade` and `sch upgrade`; the generator still writes KiCad 8 format into `bridge/` | community.quilter.ai/t/trying-to-upload-my-kicad-but-it-keep-giving-me-an-error/375 |
| Files | Schematic (required, used to detect constraints), board (required), project (optional, carries net classes and rules). No zip, no folders | docs.quilter.ai/using-quilter/upload-your-design-files |
| Placed parts | Everything inside the outline at upload is fixed, position and rotation. Everything outside is placed | docs.quilter.ai/design-parameters/pre-placed-components |
| Regions | A KiCad rule area on F.Cu or B.Cu with every keepout item deselected is a placement region; parts are assigned by designator in the app; a hard constraint | docs.quilter.ai/design-parameters/placement-regions |
| Keepouts | Read from the file | docs.quilter.ai/design-parameters/keepouts |
| One side | Only by assigning every part to a top-layer region | docs.quilter.ai/design-parameters/single-sided-placement |
| Pairs | Net class `differentialpair` (or an unpublished synonym) and names ending P/N; 100 or 85 ohm only; microstrip over a ground plane; **no layer restriction** | docs.quilter.ai/physics-constraints/differential-pairs |
| Length matching | "Timing-sensitive signals" is in internal testing, not available | docs.quilter.ai/physics-constraints/timing-sensitive-signals |
| Proximity | In-app "Proximity Constraints", for parts with no automatic rule, protection diodes named as the common case | docs.quilter.ai/using-quilter/review-and-edit-constraints |
| Layers | A ground layer must be named "ground" or "gnd", a power layer "power" or "pwr" | docs.quilter.ai/using-quilter/prepare-your-input-board-file |
| Stackup, rules | Read from the file if chosen, or a JLCPCB preset | docs.quilter.ai/design-parameters/stackups, docs.quilter.ai/using-quilter/fabricator-constraints |
| Pours | Deleted and regenerated unless named and listed as Preserved Pours | docs.quilter.ai/design-parameters/preserved-pours |
| Bypass caps | Detected; assigned by schematic wire, else by voltage-type pin name | docs.quilter.ai/physics-constraints/bypass-capacitors |
| V-scores, rails, panels | **Not documented.** Only "one closed board outline". The tabs are inside that one outline; expressed as keepouts round each tab and regions that stop 5 mm short of the break lines (§13.2) | docs.quilter.ai/using-quilter/prepare-your-input-board-file |
| Free tier limits | No board size, layer, part or pin limit published; eligibility is by company size | quilter.ai/pricing |
| Common upload failures | zip or folders; not exactly one closed outline; netlist not matching the schematic | docs.quilter.ai/about-quilter/faq |

### 12.2 What came off the board

Every note that was written on the board is here or already elsewhere: the
connector's row convention (row A driven, row B received, the cable crosses
A(n) to B(n): `PINMAP.md` section 1), the DB12 pin 5/6 order (`PINMAP.md`),
"HL2 R17 must not be fitted" (section 10), "sockets J2, J3, J4 on the
underside", the outline and datum dimensions (sections 6.1 and 11.3), the
panel window figures (`HL2_END_PANEL.md`) and the rail warning (no rails
now). On the board: reference designators, the footprints' own pin-1 marks,
one name-and-revision line and the "do not plug or unplug powered" warning
per end. The 1:1 print rule and the score label are on user layers outside
the outline.

Found while doing it: the bottom-side sockets carried their silkscreen,
courtyard and fab graphics on the **top** layers, and their reference text
was not mirrored. Both fixed in the generator.

### 12.3 No rails

JLCPCB lists edge rails as "Not necessary" for Economic PCBA and "Necessary"
for Standard (jlcpcb.com/capabilities/pcb-assembly-capabilities), and asks
for traces and components more than 0.3 mm from the edge
(jlcpcb.com/help/article/pcb-assembly-faqs-part-2). Every placement region
stops 0.8 mm inside the edge and the locked parts' copper was already at
least 0.3 mm in.

The V-score question this section used to leave open is settled in §13.2:
JLCPCB does not V-score Economic assembly at all, so the ends are now joined
by mouse-bite tabs, which Economic accepts, and the rails stay off.

Found while doing it: the generator drew the middle score line 0.07 mm off
the real boundary between the two ends (at the radio end's untrimmed y 0).
It is now on the boundary.

### 12.4 Locked parts, against their sources

| Part | Position | Source | Agrees |
|---|---|---|---|
| J2 on DB1, J3 on DB12, J4 on CN1 | HL2 hole grids | `hermeslite.kicad_pcb`, recomputed by `check_geometry.py` | yes |
| J1 SlimSAS | datum HL2 (80.40, 119.30) | `HL2_END_PANEL.md` | yes |
| J5 JTAG pass-through | local (51.40, 30.80), rotation 90, since 13 Sep 2026 (was (56.00, 24.50), vertical) | §14.5; not set by the radio, locked so the placer cannot bury it | yes |
| M3 U-notch | x 1.30-4.70 round HL2 MH2 (73.00, 137.00) | `HL2_MECHANICAL_ENVELOPE.md` | yes |
| MH6 locating hole | HL2 (74.04, 75.42) | same | yes |
| Jumper window | local x 43.30-57.00, y 39.50-53.00 | section 13.3 | yes: DB6 read from the HL2 board is inside with 2.5 mm all round. It was 0.50 mm short until 13 Sep 2026 |
| J101 SlimSAS | face dock x 89.73 = 13.97 mm from J14 pin 1, centreline dock y 53.73 | `TANG_IN_40MM_CASE.md` | yes |
| J102 | J14 positions 5-40 | Sipeed iBOM, dock rev 31004 | yes |
| Gowin M3 hole | dock (97.67, 62.66) | `TANG_IN_40MM_CASE.md` | yes (inside J101's footprint) |
| FID1-FID3 | moved from the removed rails onto the board | - | - |

### 12.5 The rules, and how each is expressed

| Rule | In the file | In Quilter | Checked after return |
|---|---|---|---|
| ESD arrays within 5 mm of the contacts | `REGION_*_ESD`, a strip from the connector courtyard to 4.9 mm past the contact copper | proximity constraint, typed in | `check_geometry.py` |
| Terminations within 5 mm of the receiver | U6's four share `REGION_RADIO_HDR` with U6 | proximity constraint, typed in | `check_geometry.py` |
| HL2 header nets under 25 mm | `REGION_RADIO_HDR`: every non-capacitor part on a DB1/DB12 net, plus R2, U3, U6, U8, U9 | not expressible | `check_geometry.py`, routed length |
| Decoupling at the pin | - | bypass capacitor comprehension | `check_geometry.py`, 3 mm |
| Each part on its own end | five regions, each inside one end | regions | `check_geometry.py` |
| 5 mm from a break line | `KEEPOUT_TAB1..3_PARTS`: no footprint within 5 mm of either row of mouse bites; regions stop short of it | keepout, regions | `check_geometry.py`, DRC |
| No copper near the tabs | `KEEPOUT_TAB1..3_COPPER`: tracks, vias and pours, 1 mm round the tab, all layers | keepout | DRC |
| Capacitors parallel to the break lines | - | **not expressible** | `check_geometry.py`: every SMD capacitor at 0 or 180 degrees |
| Nothing in or near the cut-outs | `KEEPOUT_CUT_FPGA`, `_ADC`, `_MID`, `_T2`: tracks, vias, pads, pours and footprints, 1 mm past each hole edge, all layers | keepout | `check_geometry.py`, DRC |
| J14 positions 1-4 | `KEEPOUT_J14_POS1_4_VIAS`, `KEEPOUT_J14_POS1_4_BOTTOM` | keepout | DRC |
| Height under the board | `KEEPOUT_UNDER_SMA`, `KEEPOUT_UNDER_KEYJACK`, `KEEPOUT_UNDER_DOCK_J9`: no bottom footprint; and every region is top-only | keepout, regions | DRC |
| Pairs clear of the cut-outs | the cut-out keepouts hold every track 1 mm off | pair tracks 2 mm off: not expressible | `check_geometry.py` |
| USB Blaster access to J5 | `KEEPOUT_J5_IDC_L/R/T/B`: no footprint in a 12 x 20 mm ring | keepout | DRC |
| Pairs top layer only | - | **not expressible** | `check_geometry.py` |
| Length groups within 2.5 mm | - | **not available** | `check_geometry.py` |
| Stack, classes, clearance | JLC04161H-7628 stack, In1 `GND`, In2 `PWR`, class `differentialpair` 0.25/0.20 mm, 0.15 mm clearance everywhere | read from the file | DRC |

---

## 13. Holes over the radio, tabs, the jumper window (13 Sep 2026)

Three approved changes to the board outline. No net, no pin, no schematic
symbol and no locked part moved. The radio end's SlimSAS connector J1 is where
it was.

### 13.1 Holes over the radio's FPGA, AD9866 and T2

**Why.** The radio end covered three parts of the HL2. The FPGA U2 carries a
heatsink 8.25 mm tall on the owner's radio, about 3 mm under this board, with
no air. The AD9866 U7 is the radio's other heatsinked part. The transformer T2
is 11.17 mm tall on the owner's radio, and this board's underside is at
10.92 mm on his socket: they collide.

**How each hole is sized.** From the part's package, not from anyone's
heatsink, so a heatsink no larger than the package passes up through the hole
at any height and warm air rises freely. The package outline, including leads,
is the footprint's extent in `hardware/hl/hermeslite.kicad_pcb`: pads, and the
silkscreen outline where that is larger. `check_geometry.py` reads it from that
file itself.

| HL2 part | Package, from the datasheet | Footprint outline | Hole | Hole, radio local |
|---|---|---|---|---|
| U2, EP4CE22E22C8N | 144-pin EQFP, **22 × 22 mm** over the leads, 0.5 mm pitch (Cyclone IV Device Handbook vol. 1, Table 1-3, E144) | pads 23.20 × 23.20 | **26.20 × 26.20 mm** | x 24.00–50.20, y −1.10–25.10: the FPGA's leads come to 0.33 mm from the board edge, so this hole is **a notch open to the radio end's top edge** |
| U7, AD9866BCPZ | 64-lead LFCSP, **9 × 9 mm** body, no leads beyond it (ADI CP-64 outline; DigiKey "64-LFCSP-VQ (9x9)") | pads 10.00 × 10.00 | **13.00 × 13.00 mm** | x 35.00–48.00, y 30.00–43.00 |
| T2, "8:1 Z" | the HL2 part list names MACOM MABA-010143-FLUX18 or Coilcraft WBC8-1L, SM-22 case 3.81 × 2.79 mm. The owner's T2 is 11.17 mm tall, so it is not that case: the footprint is the only safe outline | TRANSFSMT, pads and outline 7.62 × 8.25 | **10.62 × 11.25 mm** | x 34.09–44.71, y 45.00–56.25 |

The HL2 part list calls U2's package "144-LQFP EP"; Intel's name is EQFP. Same
22 mm body-plus-leads either way.

**The margin: 1.5 mm on every side of the package.**

| | |
|---|---|
| 0.8 mm | worst-case misalignment of this board on the HL2 at that distance from DB1 (`HL2_MECHANICAL_ENVELOPE.md` §12.2) |
| 0.2 mm | JLCPCB routed-edge tolerance, "±0.2 mm (regular precision)" |
| 0.5 mm | so a package-sized heatsink does not touch the wall and air still moves |

**Corners: radius 1.0 mm** everywhere on the new edges. JLCPCB: "Rectangular
holes and slots without rounded corners are not supported", and its minimum
non-plated slot is 1.0 mm, i.e. a 0.5 mm cutter radius. With a margin (1.5)
larger than the radius, the package's own corners still clear the arcs.

**One cut-out, not three.** The AD9866 hole, the T2 hole and the jumper window
lie within 2 mm of each other. The webs between them would carry nothing, so
they are one orthogonal cut-out containing all three rectangles: local x
34.09–57.00, y 30.00–56.25.

**Keep-back: 1 mm.** No track, via, pad, pour or part within 1.0 mm of a hole
edge on any layer: JLCPCB's 0.2 mm routed-edge copper minimum ("≧0.2 mm"),
plus the 0.3 mm its assembly FAQ asks for, plus 0.5 mm. In the file as
`KEEPOUT_CUT_FPGA`, `KEEPOUT_CUT_ADC`, `KEEPOUT_CUT_MID` and `KEEPOUT_CUT_T2`.
**Pair tracks keep 2 mm off** (`check_geometry.py`), so each pair has at least
1 mm of the In1 ground plane beyond it toward the hole, about five times the
0.21 mm dielectric. The In1 ground plane is one solid pour round the whole
radio end; it goes round the holes, and no pair can cross a hole because no
track can.

**Cost.** JLCPCB publishes no charge per cut-out. Its only milling charge is
the Routing Fee: "If the width of the slot exceeds 1.0mm and the slot path
reaches 120m per square meter, the Routing Fee will be charged"
(jlcpcb.com/help/article/in-what-cases-will-there-be-charged-extra, updated
9 Sep 2026). The whole milling path of this board, outline, slot and cut-outs
together, is **0.564 m on 0.00593 m², 95 m per m²**. `check_geometry.py`
recomputes it and fails at 120. Before these changes it was 0.361 m, 62 per m².

**Placement regions after the holes.**

| Region | Before | Now | Parts' courtyards |
|---|---|---|---|
| `REGION_RADIO_HDR`, the chips on HL2 header nets | x 8.45–36.0, y 5.17–33.0, **767 mm²** | an L round the FPGA notch: x 8.45–22.9 from the top edge margin (y 0.87) to y 26.2, then x 8.45–33.0 to y 33.0, **533 mm²** | 298 mm² (31 parts), so 1.8 × |
| `REGION_RADIO` | the whole radio end | round the FPGA notch, and 5 mm short of the tabs | 3074 mm² for 483 mm² |
| `REGION_RADIO_ESD`, `REGION_GOWIN_ESD` | unchanged | unchanged | the cut-outs are 12 mm away |

The header region lost the FPGA notch but gained the 4.3 mm strip along the top
edge, which is no longer a break line. **The 25 mm rule still holds room:**
for every HL2 header pin, at least **306 mm²** of the region lies within
21.5 mm of it (25 mm less an allowance for the far part's pad). The worst is
DB1 pin 1, whose net goes to the board's own translator U2 and R18: a 48 mm² TSSOP and a
resistor. If Quilter reports the header region full, extend it down to y 38
between x 21.1 and 33.0.

### 13.2 The ends: mouse-bite tabs, not a V-score

**The defect.** The ends met edge to edge at one V-score. J101's shell-tail
pads were 0.31 mm from it and J102's pads 1.60 mm. Snapping would crack joints
or lift pads.

**JLCPCB's rules, read 13 Sep 2026.**

| | V-score with a breakaway strip | Tabs with mouse bites |
|---|---|---|
| Economic assembly | "**V-cut is not supported in Economic Assembly**" (jlcpcb.com/help/article/pcb-panelization). The assembly table lists "Panel with V-cut" for Standard only | "Single PCB, Panel with mouse bites" listed for Economic (jlcpcb.com/capabilities/pcb-assembly-capabilities) |
| Geometry | "The V-cut line must cross the whole panel", straight; two scores at least 2 mm apart (3 mm recommended); panel at least 70 × 70 mm | "Panel board spacing: 1.6 or 2 mm"; "For breakaway with mouse-bites, minimum width is 5mm"; "Recommended diameter of mouse bite is 0.5mm-0.8mm" (jlcpcb.com/capabilities/pcb-capabilities) |
| 5 mm from every part | the score runs the full width, so every part along it needs 5 mm: the Gowin end would grow 4.7 mm and the radio end's fiducials still could not clear | the break lines are 7 mm long and sit where nothing is near |
| Edge left behind | clean | small nubs, kept inside the outline (below) |

**Chosen: three tabs with mouse bites.** The V-score is not available on the
assembly service this board is ordered with. That alone decides it.

**The layout.**

| | |
|---|---|
| Order, top to bottom | radio end (64.88 mm), slot (2.00 mm), Gowin end (25.12 mm) |
| Board | **64.50 × 92.00 mm** (was 64.50 × 90.00) |
| Tabs | 5.00 mm wide at x **29.60, 40.60, 51.60**; slot corners R 1.0, so each tab is 7.00 mm wide where it meets an end |
| Mouse bites | 8 holes of 0.50 mm per row, centres 3.00 mm either side of the tab centre, one row along each end's edge, **centres 0.25 mm inside the edge** so the snapped edge leaves no nub standing proud |
| Joined edges | the radio end's bottom edge (HL2 y 138.25) to the Gowin end's top edge (dock y 41.17) |

**Why those two edges.** The Gowin end's other long edge is where J101's
contacts and J102 crowd the edge, and no tab position there is 5 mm from
both. Its top edge has only J101 at one end: from x 26 to 59 nothing is near.
The radio end's top edge is where DB1's socket and the FPGA notch are, and the
magjack beside it is 11.18 mm tall, so that end cannot grow there. Its bottom
edge has J1's shell tails 6.6 mm in and the fiducials, and tabs in the middle
clear both.

**Did the Gowin end need to grow?** No. Growing past J101 and J102 toward the
dock's core module was checked and ruled out: the case study keeps the adapter
at dock y 66.5 or less there, over the USB3 bridge and the core module, whose
parts stand 8.27 mm tall against a 7.0–7.5 mm scheme 1 underside. Growing the
other way, toward the dock's PMOD edge, would land on nothing: that edge is
already 3.8 mm past the dock, and the 6.4 mm PMOD socket and 15.6 mm USB
sockets lie under or beyond the existing outline. With tabs, neither was
needed.

**Distances achieved.**

| | Distance to the nearest break line |
|---|---|
| Nearest locked part: fiducial FID2 | **6.22 mm** |
| J101, J102, J1 | over 9 mm |
| Anything Quilter places | **5.0 mm or more**: `KEEPOUT_TAB1..3_PARTS` and every region stop 5 mm short (the Gowin ESD strip 5.10 mm, the radio region 5.05 mm) |

**Target met everywhere: no part within 5.0 mm of a break line.** Every SMD
capacitor must lie parallel to the break lines, i.e. at 0 or 180 degrees.
Quilter cannot be told a rotation; `check_geometry.py` fails the returned board
on any capacitor at 90 or 270.

**Copper:** `KEEPOUT_TAB1..3_COPPER` holds tracks, vias and pours 1 mm clear of
each tab on every layer. No net crosses a tab; each end's pours stop at its own
edge.

**The rails.** JLCPCB's assembly capability table, Economic column: edge rails
"**Not necessary**"; delivery format "Single PCB, Panel with mouse bites";
board size from 10 × 10 mm. The Standard column needs rails, a 70 × 70 mm
minimum, and is the only one that V-scores. So **Economic, no rails, tabs**.
What the published pages do not settle is how JLCPCB classes one outline that
holds two different circuits joined by tabs: its "different designs" rule
says pieces whose copper differs and which "can be separated" count as
different designs, and a panelled board "will turn into its original cost of
Engineering fee+board fee" (jlcpcb.com/help/article/different-design-in-your-pcb-files;
.../in-what-cases-will-there-be-charged-extra). That was equally true of the
V-score version and is not yet in `COST.md`.

**Ask JLCPCB, before ordering:**

> My Gerber is one 64.50 × 92.00 mm, 4-layer, 1.6 mm board. It holds two
> different circuits joined by three 5 mm breakaway tabs with 0.5 mm mouse
> bites across a 2 mm routed slot. There are no V-cuts and no edge rails. All
> SMT parts are on the top side, at least 0.8 mm from any edge and 5 mm from
> any tab, and there are three fiducials. (1) Can you assemble this as
> Economic PCBA, as a single PCB, without adding edge rails? (2) Will you charge
> it as one design or two, and does it lose the promotional board price?
> (3) Please ship it with the tabs unbroken; will you?

### 13.3 The jumper window

rev D as first prepared stopped the window 0.50 mm short of DB6. It now runs
**local x 43.30–57.00, y 39.50–53.00** (was x 44.50–57.00, y 39.50–50.00),
which leaves DB6's outline (HL2 x 115.80–120.70, y 117.80–123.80) with 2.5 mm
clear on the left and bottom, 5.0 mm on top and 6.3 mm on the right, for a
finger or tweezers. It is part of the cut-out in §13.1, so it clears the same
1 mm keep-back; J5's courtyard ends 3.1 mm above it, and DRC passes.

**Found on the way: DB3's position was wrong in the notes and the checker.**
(Superseded on 13 Sep 2026: DB3 is now wholly inside the cut-out and J5 has
moved; §14.5.)
DB3 is at HL2 x 123.33–125.87, **y 109.31–119.47**, not y 114.39–122.01; the
old figure rotated its footprint the wrong way. So DB3 was never "inside the
window". About a third of it (its end toward J5) is under the board, and it
cannot be fully uncovered without moving J5, which is locked. The other two
thirds are in the window, as before. `check_geometry.py` now reports DB3
from the HL2 file and does not fail on it.

### 13.4 Measured on the owner's radio

**Measured by the owner on his own HL2, build 9, on 13 September 2026.**
These replace the assumptions used until then.

| Part | Measured | Was assumed | What it means here |
|---|---|---|---|
| Ethernet jack CN3, height above the HL2 board | **11.18 mm** | 13.5 | beside the radio end's top edge, not under it. It is taller than the 10.92 mm underside, so the radio end cannot grow toward it |
| CN3 width | **17.7 mm** | 20.0 | centred on the footprint, its body ends about 1.7 mm short of the radio end's edge; worth a look at the first fit |
| CN3 release clip | **on top** | — | |
| DC power jack CN2 | slightly lower than CN3 | — | outside the board's outline |
| Morse-key jack CN4, height | **5.12 mm** | 6–10 | under the board; 5.80 mm clear |
| Key plug grip thickness | **6.15 mm** | — | outside the case |
| Clock SMAs CL1 and CL2, height | **4.24 mm** | 3–8 | under the board; 6.68 mm clear. **Both are fitted and in use, with straight SMA plugs** |
| Transformer T2, height | **11.17 mm** | — | taller than the underside: now under a hole (§13.1) |
| Header stack, pin socket pushed onto DB1 | **10.92 mm** | 11.04 | the underside on his radio. His socket may not be the specified part |
| FPGA U2 heatsink, height above the HL2 board | **8.25 mm** | — | 2.67 mm under the board; now under a hole (§13.1) |

**The internal case measurements are superseded:** use the existing 55 mm
front panel design (`panel-endcap/`).

---

## 14. Risk-review fixes (13 Sep 2026)

A risk review of rev D found two buffers wired backwards, continuous
contention with the radio's stock gateware, back-powering of an unpowered
Tang, and noise paths into the receiver. The owner approved the fixes below.
All of it is in the generator; `check_netlist.py` and `check_geometry.py`
assert it.

### 14.1 Two buffers were wired backwards

On an SN74AVC4T245, **DIR LOW is B data to A bus** and DIR HIGH is A data to
B bus (TI SCES576I, Table 7-1; confirmed from the datasheet on 13 Sep 2026).

| Part | As found | What it did | As fixed |
|---|---|---|---|
| **U8**, AUXIO read | A = radio pins 90/91/103/104 (via 330 Ω), B = cable; both DIR on GND, both OE* on GND | **drove the radio's CW key, PTT and clock-chip I2C pins from four floating cable wires, always on**. A LOW is "keyed": the radio could transmit by itself | both DIR on +3V3 (radio → cable), both OE* on `PRSNT_OE_N` |
| **U10 port 1**, TDO read | 1A1 = `J_TDO_T` (CN1 pin 3), 1B1 = cable; 1DIR on GND, 1OE* on GND | **drove the FPGA's TDO pin from the cable, always on**; broke local USB Blaster programming | 1DIR on +3V3 (radio → cable), 1OE* on `PRSNT_OE_N`, R48 10 kΩ pull-up on `J_TDO_T` |

Every other translator and buffer was checked the same way, against the truth
tables and the intended direction; `PINMAP.md` §12 has the full table.

| Part | Direction as found | Enable as found | As fixed |
|---|---|---|---|
| U1 (forward group) | radio → drivers, correct | always on | unchanged |
| U2 (aux out, enables) | radio → board, correct | always on | unchanged; the enable outputs now pass Q3 and Q4 |
| U3 (to radio pins 87/88/89) | receivers → radio, correct | **always on**, fought pin 87 under stock gateware | OE* on `RX_EN_N` (link-alive gate) |
| U9 (AUXIO drive) | cable → radio, correct | gateware AND presence | also gated by `LINK_ALIVE` (Q4) |
| U10 port 2 (TCK, TMS) | cable → radio, correct | gateware only; **stock gateware enabled it** | `JTAG_EN_N` now gated by `LINK_ALIVE` (Q3) |
| U11 port 1 (TDI) | cable → radio, correct | same as U10 port 2 | same fix |
| U11 port 2 | spare, disabled | off | now always on: the detector's clock buffer |
| U4, U5 DS90LV047A drivers | cable | always on | gated by presence (R_DRVEN_PRSNT fitted) |
| U6, U7 DS90LV048A receivers | to radio pins 99/100/101 and U3 | **always on**, fought pins 99–101 under stock gateware | EN* on `RX_EN_N` |
| SN74AVC8T245 | none on the board | | |

**The checker now derives every direction** from the DIR and OE nets and the
truth table and compares each channel with `PINMAP.md` §12. Proved by putting
U8's DIR pins back on GND: `check_netlist.py` failed with 10 problems,
including "U8 port 1 runs B>A (DIR = GND), PINMAP.md says A>B" and "still
enabled toward the radio: U8 port 1, U8 port 2" under stock gateware.

### 14.2 Contention with stock gateware: the link-alive detector

**The problem.** Stock gateware for HL2 build 5 and later drives FPGA pin 87
LOW and pins 99, 100 and 101 as LED outputs; our U3 and U6 drove the same pins
continuously, at 20–49 mA per pin, at or over the Cyclone IV's 25 mA limit.
And it drives pins 72 and 80 LOW, which our enables read as "on". No spare DC
pin stays HIGH under stock gateware, and series resistors large enough to
limit the fight would close the 3.26 ns eye.

**The fix.** Link gateware drives a continuous 153.6 MHz clock on pin 98; no
released variant does (pin 98 is an LED blinking at a few hertz). A voltage
doubler turns "clock running" into a DC level.

| Part | Ref | Value | LCSC | Tier | Role |
|---|---|---|---|---|---|
| clock buffer | U11 port 2 | SN74AVC4T245 (already fitted) | C81461 | Extended, already paid | copy of `DI_FWDCLK` → `LA_CLK`; loads neither pin 98 nor its divider |
| pump capacitor | C27 | 10 pF C0G 0402 | C32949 | Basic | `LA_CLK` → `LA_PUMP` |
| clamp diode | D13 | RB751V-40, SOD-323 | C7502691 | **Preferred Extended: no fee** | `LA_PUMP` to GND |
| rectifier | D14 | RB751V-40 | C7502691 | same | `LA_PUMP` → `LINK_ALIVE` |
| hold capacitor | C28 | 10 nF X7R 0402 | C15195 | Basic | `LINK_ALIVE` to GND |
| discharge | R45 | 100 kΩ 0402 | C25741 | Basic | 1 ms with C28 |
| receiver gate | Q2 | AO3400A | C20917 | Basic | `LINK_ALIVE` HIGH pulls `RX_EN_N` LOW |
| JTAG gate | Q3 | AO3400A | C20917 | Basic | between U2's output and `JTAG_EN_N` |
| AUXIO gate | Q4 | AO3400A | C20917 | Basic | in series with Q1 |
| far-end clamp | Q6 | AO3400A | C20917 | Basic | holds `LINK_ALIVE` LOW with no far end |
| pull-up | R46 | 10 kΩ | C25744 | Basic | `RX_EN_N` |
| input holds | R49–R52 | 10 kΩ to GND | C25744 | Basic | U3's four inputs while U6/U7 are tri-stated (TI: inputs must not float) |
| test point | TP10 | | | | `LINK_ALIVE` |

**The numbers** (from the review; the AO3400A threshold re-read from the AOS
datasheet: VGS(th) 0.65 / 1.05 / 1.45 V min / typ / max at 250 µA):

| Case | `LINK_ALIVE` |
|---|---|
| Clock running, far end present | `LA_PUMP` swings about 2.75 V (10 pF against the diode's ~2 pF); output about **2.2 V**, 0.75 V over the 1.45 V maximum threshold |
| Stock gateware | each LED edge adds 10 pF × 3.3 V / 10 nF = 3.3 mV, decaying in 1 ms: **under 0.1 V**, far under the 0.65 V minimum threshold |
| FPGA reconfiguring | clock stops, output falls in a few milliseconds, before stock gateware starts |
| No far end, or cable unplugged | clamped to 0 V by Q6 |

**The receivers really tri-state.** DS90LV048A (TI SNLS045C Table 1): outputs
enabled only for EN HIGH with EN* LOW or open; every other combination is
TRI-STATE, 10 µA maximum leakage. SN74AVC4T245: OE* HIGH puts both ports in
isolation; OE* is referenced to VCCA, which is 3.3 V on U3.

**Placement.** U11 must sit beside U1 (the forward-clock translator): U11 is
in `REGION_RADIO_HDR` with U1, Quilter gets a 5 mm proximity constraint, and
`check_geometry.py` checks it on return. The pump parts C27, D13 and D14 go
within 3 mm of U11.

**The one behaviour to know.** With the link gateware running but no far end,
or during a far-end link reset, the receivers, the JTAG buffers and the AUXIO
drive are off too. That is intended: the owner's safe state requires it.

**Recovery JTAG.** R_JTAG_FORCE (R21, not fitted) moved from `HL2_JTAG_EN` to
`JTAG_EN_N`, behind Q3, because a radio without working gateware makes no
clock. Fitted, it enables the JTAG buffers regardless.

**Cost of §14.1–14.3 together:** about $0.55 per board (five AO3400A, two
diodes, two capacitors, eight resistors, 39 joints) and **no new feeder fee**:
the RB751V-40 is a JLCPCB Preferred Extended part, exempt from the fee on
Economic assembly, which the review had assumed would cost $3.07. (Tier read
from the JLCPCB library mirror at jlcsearch.tscircuit.com; JLCPCB's own FAQ
confirms Preferred parts carry no feeder fee.)

### 14.3 Power sequencing: presence gates the cable drivers

**The problem.** Radio on, Tang off: the radio end's always-on LVDS drivers and
the presence line push roughly 30–60 mA into an unpowered Gowin, whose
behaviour unpowered is not documented.

| Change | Effect |
|---|---|
| **R_DRVEN_PRSNT fitted, R_DRVEN_ON not fitted** | U4, U5 run only while the far end drives presence HIGH. A Tang drives presence from gateware, so its drivers stay off while it is off or unconfigured |
| **Q5** AO3400A (gate `SB_PRSNT_IN`, drain `PRSNT_OE_N`) + R47 10 kΩ pull-up | U8 (AUXIO read) and U10 port 1 (TDO) drive the cable only with a far end present. Removes the 7 mA TDO path into a dead Tang and 1.3 mA radio to radio |
| **R103 1 kΩ → 10 kΩ** at the Gowin end | presence injection into a dead Tang from 1.35 mA to about 0.25 mA; reading unaffected |
| **Gowin gateware rule** (`PINMAP.md` §11.4) | keep LVDS and JTAG outputs off until presence reads HIGH |

What remains with the Tang off: about 0.25 mA on the presence line. **This
needs the sideband cable**; the no-sideband variant leaves the link dead.
Cost: one AO3400A and one 10 kΩ, about $0.09 per board, no fee.

`check_netlist.py` asserts it in all three pairings: radio end fed by a radio
far end (A8 through 1 kΩ to that radio's +3V3), radio end fed by a Gowin far
end (A8 through 1 kΩ from a gateware ball, no pull-up), and the Gowin end fed
by a radio (read through 10 kΩ).

### 14.4 Noise into the receiver: what is built in

Nothing here can be measured before boards exist. These are the measures the
owner approved to build in; §14.6 is how to measure them.

**1. LC filter on our 3.3 V input.** DB1 pins 19/20 → FB1 → **L1** → +3V3.

| Part | Ref | LCSC | Tier | Price |
|---|---|---|---|---|
| Sunlord SWPA4030S4R7NT, 4.7 µH, 2 A, 78 mΩ, shielded 4 × 4 mm | L1 | C193025 | **Extended, $3.07 fee** | $0.0856; **only about 2,000 in stock** |
| AVX TAJB107K006RNJ, 100 µF 6.3 V tantalum, case B, ESR 1.7 Ω | C29 | C16133 | Basic | $0.2574 |
| 0 Ω 0805 bypass across L1, **not fitted** | R_LBYP | C17477 | Basic | — |

Corner about 7.3 kHz. The tantalum's 1.7 Ω ESR damps the LC peak
(characteristic impedance about 0.22 Ω). Drop at 300 mA: 23 mV, so the board's
+3V3 is about 3.24 V. Place L1 and C29 within 8 mm of DB1 pins 19/20 and return
C29 to ground beside DB1 pins 13/14 (Quilter proximity constraint; checked on
return). Hot plug (§4.3) is unchanged ahead of FB1; behind L1 the capacitors
charge at no more than 0.7 A per microsecond. Still do not plug or unplug
powered. The review's alternative if C193025 runs out: SWPA4020S100MT (10 µH,
900 mA, 215 mΩ, C82398), 65 mV drop.

**2. Shell RF bond footprints, not fitted.** C30 (10 nF 0805, C1710) beside
R_SHELL and C101 beside R117. At bring-up the shell can be DC-open but
RF-bonded: lift the 0 Ω, fit the capacitor. Expect little effect: the cable's
26 ground contacts carry the loop current regardless.

**3. Layout rules at the radio end.** "Fast" means every radio-end pair plus
the single-ended nets that switch at 153.6 MHz: the header nets on pins 98,
76, 77, 83, 85, 86, 87, 88, 89, 99, 100, 101, the translator nets `DI_*`,
`RX_*`, `X_*25`, and the detector's `LA_CLK`, `LA_PUMP` (the generator's
`FAST_SE`).

| Rule | For Quilter (in the board file) | For KiCad DRC | Checked on the returned board (`check_geometry.py`) |
|---|---|---|---|
| Solid ground pour on the bottom layer facing the radio | pour `GND_BOTTOM_RADIO` (add to Preserved Pours); `KEEPOUT_RADIO_BOTTOM_TRACKS`: no track on B.Cu anywhere over the radio end | the keepout | GND pour present; no track on B.Cu at the radio end |
| No fast track over the FPGA, AD9866 or T2 | `KEEPOUT_FAST_*`: no track within 3 mm of the cut-outs over them (the cut-outs are 1.5 mm bigger than the packages) | the keepouts | no fast track within the package outline plus 3 mm |
| Ground vias every 5 mm or less round each cut-out | **pre-placed**: 48 GND vias, 1.6 mm from the edge, largest gap 4.44 mm round the main cut-out and 4.20 mm round the FPGA notch; `KEEPOUT_FENCE_*` keeps footprints 2.2 mm off every cut edge so nothing lands on them | — | GND vias within 3 mm of each cut edge, no gap over 5.0 mm |
| Fast tracks at least 3 mm from any edge | round the cut-outs: the `KEEPOUT_FAST_*` areas. Along the outer edges a keepout would also block the connector's shell tails and every slow track, so it is not a keepout | **`bridge/bridge.kicad_dru`**: custom rule, edge clearance 3 mm for the fast nets (tested: it flags a fast track 0.9 mm from the edge and ignores a slow one) | every fast track segment 3 mm or more from every radio-end edge and cut-out |
| No fast track within 3 mm of DB3 pins 3 and 4 | `KEEPOUT_DB3_ADC_INPUT` (tracks, all copper layers) | the keepout | no track at all within 3 mm of those pads |

A keepout cannot name nets, so the `KEEPOUT_FAST_*` areas hold back **all**
tracks. Two places are left open on purpose: the 2.9 mm neck between the FPGA
notch and the main cut-out (it can never be 3 mm from both, so slow tracks
only; the checker catches a fast one), and J5's pin field. The Gowin end is
not covered by these rules: its pairs must reach J102, whose pins sit 2.4 mm
from its edge.

**4. Scramble every lane, including idle** — a gateware rule, recorded in
`PINMAP.md` §9.

**Not built in, by decision:** common-mode chokes on the pairs; galvanic
isolation.

### 14.5 DB3 on the radio, the cut-out and J5

**What DB3 is.** An optional, normally not fitted 4-pin header on the HL2,
footprint HERMESLITE:4x1 at HL2 (124.60, 118.20), rotation 90. From
`hermeslite.net`: pin 1 +3V3, pin 2 GND, pins 3 and 4 the **AD9866's receive
input pair** (U7 pins 51 and 52 via C49, L4, L7, R50, R64). It is an RF
daughterboard tap straight into the ADC input. The owner's radio does not
have it fitted; other owners may, and what plugs in there is an RF board that
needs space above it. Pins at HL2 x 124.60, y 118.20 / 115.66 / 113.12 / 110.58
(pins 1 to 4).

**The cut-out.** Before: about a third of DB3 lay under the board beside J5.
Now the merged cut-out (AD9866, T2, jumper window) also clears DB3:

| | |
|---|---|
| DB3 outline, from the HL2 board file | 2.54 × 10.16 mm, HL2 x 123.33–125.87, y 109.31–119.47 |
| Allowance for a plugged-in 1 × 4 socket body | 0.5 mm each side |
| Margin, as every other hole | 1.5 mm each side |
| **Clear area** | **6.54 × 14.16 mm**, HL2 x 121.33–127.87, y 107.31–121.47; radio local x 51.33–57.87, y 34.01–48.17 |
| Merged cut-out now | local x 34.09–57.87, y 30.00–56.25. The 3.3 mm tongue between the AD9866 hole and the DB3 hole is cut away too, and the window's right edge is at x 57.87 all the way down |
| Milling path | 0.565 m on 0.0059 m², still 95 m per m² (fee from 120) |
| Open cut-out, not holes | an RF board on DB3 needs room above, and our fast signals must stay away from an ADC input |

**J5 moved.** J5, the USB Blaster pass-through, is not placed by the radio; it
is locked only so Quilter cannot bury it. It was vertical at local
(56.00, 24.50), where the DB3 cut-out now is.

| | |
|---|---|
| New position | pin 1 at local **(51.40, 30.80)** = HL2 (121.40, 104.10), **rotation 90**: horizontal, odd pins along y 30.80, even pins along y 28.26, pins 1–2 at x 51.40 to pins 9–10 at x 61.56 |
| Where that is | the strip between the FPGA notch and the main cut-out, directly under CN1's socket J4 |
| Clearances | courtyard x 49.63–63.33, y 26.48–32.57: 0.63 mm from the AD9866 hole keep-back, 0.38 mm from the FPGA notch keep-back, 0.44 mm from the DB3 hole keep-back |
| JTAG tracks | J4's pins end at y 19.08; J5's nearest row is at y 28.26: ten short, straight runs |
| USB Blaster access | the IDC keep-out ring is kept, 20 × 12 mm round the pin field; the plug body overhangs the FPGA notch and the board's right edge in open air |
| One conflict to know | a USB Blaster plug on J5 and a tall RF board on DB3 cannot both be used at once: the IDC body reaches to about 1 mm from the DB3 cut-out |

`check_geometry.py` asserts DB3 plus socket plus margin is off the board, the
3 mm no-track keep-out round pins 3 and 4 covers every bit of board within it
on every copper layer, no track is there on the returned board, and J5 is
locked at its new position and rotation.

**Placement areas re-checked** (usable area after cut-outs and footprint
keep-outs, against the parts' courtyards, sampled at 0.25 mm):

| Region | Before | Now |
|---|---|---|
| `REGION_RADIO_HDR` | 538 mm² for 298 mm² (1.81×) | **590 mm² for 338 mm² (1.74×)**: U11 added; edges pulled back 2.2 mm from the notch and the main cut-out for the via fence; extended down to y 43 between the ESD strip and the fence |
| `REGION_RADIO` | 2368 mm² for 483 mm² (4.9×) | **2166 mm² for 593 mm² (3.65×)** |
| `REGION_RADIO_ESD`, `REGION_GOWIN_ESD`, `REGION_GOWIN` | unchanged | unchanged (the Gowin region gains C101) |

**The 25 mm single-ended rule still has room:** for every HL2 header pin, at
least **289 mm²** of the header region lies within 21.5 mm of it (was 308 mm²
with the same method). The worst is still DB1 pin 1, whose net goes to U2 and
R18: a 48 mm² TSSOP and a resistor.

### 14.6 Bring-up noise test plan

**Setup.** 50 Ω load on the radio's receive input, fixed LNA gain, the same
software settings every run. Record the noise floor in dBm per 500 Hz at 1.9,
3.6, 7.1, 10.1, 14.1, 18.1, 21.1, 24.9 and 28.5 MHz. Then scan 0–38 MHz with a
narrow bandwidth for spurs. Repeat once with an antenna for real-band noise.

**Before any of it:** bench-check `LINK_ALIVE` (TP10) with a 153.6 MHz signal
on DB1 pin 9 and presence held HIGH (TP3 to +3V3 through 1 kΩ): about 2.2 V.
With the signal off: under 0.1 V.

| Step | Configuration | What it isolates |
|---|---|---|
| 0 | Stock gateware, **board removed** | baseline |
| 1 | Link gateware, board removed | the gateware alone |
| 2 | Board fitted, cable unplugged (drivers off by presence) | our board's static and translator activity |
| 3 | As 2, drivers forced on (fit R_DRVEN_ON) | driver activity, no cable |
| 4 | Cable to the Tang, Tang powered and configured, **link idle** (scrambled) | the ground loop plus idle traffic |
| 5 | **Link running**, full ADC stream | worst case |
| 6 | Variations on step 5, one at a time (below) | which measure matters |

**Step 6 trials:**

| Trial | How |
|---|---|
| Clip-on cable ferrite | material 31 (works from about 1 MHz), at the radio end, at the Tang end, then both. The cable's cross-section is not measured; about $3–6, part not chosen |
| Tang on the radio's supply, separate leads | from the brick's terminals, not daisy-chained; then with a ferrite on the Tang's DC lead |
| Tang on its own supply | as the reference for the row above |
| Tang Ethernet unplugged | removes that loop |
| Shell DC-open, RF-bonded | lift R_SHELL / R117, fit C30 / C101 |
| LED resistors lifted | HL2 R71–R74, which carry our lanes to the front-panel LEDs |
| LC filter bypassed | fit R_LBYP |

**Pass:** noise floor within 1 dB of step 0, and no spur visible above the
floor in 500 Hz.

### 14.7 Hardrock-50 and the DB9 adapter board: compatibility requirement

**The DB9 adapter board (`hardware/companions/db9/`) cannot be fitted with
this bridge board.** Its hand-wired leads land on DB1 pins 3, 7, 13 and 19,
which our socket J2 covers, and DB1 pin 3 (FPGA pin 77, the HL2 UART TX) is our
ADC data lane 1.

**Owner decision (13 Sep 2026):** the Hardrock-50 amplifier's serial and PTT
connection moves to the **N2ADR HL2 IO board** (github.com/jimahlstrom/HL2IOBoard),
which has its own DB9 connector and a Hardrock-50 firmware example
(`n1adj_hr50`); PTT comes from the IO board's pass-through of EXTTR. The DB9
adapter is retired. No change to this board. The IO board itself coexists: it
sits at the opposite end of the radio, about 29 mm from ours, shares no FPGA
pin and no I2C bus with this link, and adds an estimated 30–50 mA to the
radio's 3.3 V.

### 14.8 What it cost

| | Before | Now |
|---|---|---|
| Order total, five boards | $154.84 | **$162.43** |
| One complete link | $30.97 | **$32.49** |
| The Gowin half (Gowin-end parts and joints, five boards) | $21.91 | **$21.92** (R103 value only) |
| Extended feeder fees | 6 × $3.07 | **7 × $3.07** (L1; the RB751V-40 is Preferred, no fee) |
| Radio-end parts per board | $13.39 | **$14.23** |

`COST.md` has the lines.

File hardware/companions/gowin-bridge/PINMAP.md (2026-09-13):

# gowin-bridge pin map, rev D

**One design with two ends, on one board.** One schematic, one PCB, one BOM.
The **radio end** (connector J1) plugs onto the Hermes-Lite 2; the **Gowin
end** (connector J101) plugs onto the Tang Mega 138K dock's J14. They are
fabricated together and snapped apart. Two radio ends and one cable make a
radio-to-radio link; a radio end, a Gowin end and one cable make a
radio-to-FPGA link. Sections 1–10 are the radio end and the contract both ends
share; **section 11 is the Gowin end; section 12 is every translator and
buffer, its direction and its enable, and the safe state** (13 Sep 2026).

Authoritative. `tools/check_netlist.py` retypes every table below from this
file and asserts it against the generated netlist, so the two cannot drift.

| | |
|---|---|
| Connector | **Amphenol ICC U10A474240T**, LCSC **C5432262**, SlimSAS SFF-8654 8i, 74 position, right angle, 23.50 mm wide, 9.90 mm above the board, 15.80 mm deep |
| Cable | **10Gtek CAB-8654/8654-8i-P**, 8i to 8i, 0.5 m, $15. Twinax construction, 32 AWG, 100 Ω |
| Pairs | 16 differential: 14 used and 2 spare at the radio end; 14 used and the spare pair not wired at the Gowin end |
| Sidebands | 16 single-ended, all 16 wired or clamped |
| Lane rate | DDR at 153.6 MHz = **307.2 Mbit/s** per lane, both directions simultaneously |
| Payload | 3 lanes each way = **921.6 Mbit/s** = the complete raw 12-bit 76.8 MSPS ADC stream |
| Auxiliary | 307.2 Mbit/s each way, simultaneously, on its own clock |

---

## 1. The crossover, which is the whole reason one design works

**SFF-9402 Rev 1.1**, *Multi-Protocol Internal Cable Pinouts for SAS and/or
PCIe*, section 5, implementation note **16**:

> "The pinouts in this reference guide define full crossover cables (The A row
> on one end crosses over to the B row on the other end) … a. Based on a full
> crossover the TX (inputs to the cable at one end) crossover to RX (outputs
> from the cable at the other end). b. The sideband signals also implement a
> full crossover such that the Root/Controller and Endpoint/Backplane have
> different fixed end pin assignments."

**Tables 6-2 and 6-3** of the same document then show it contact by contact:
Table 6-2 maps the Root end's SFF-8654 **A1…A37** onto the Endpoint end's
**B1…B37**, and Table 6-3 maps **B1…B37** onto **A1…A37**. So the rule is

> **A(n) at one end ↔ B(n) at the other end, for n = 1…37.**

The contact number is preserved and only the row letter flips. It holds for the
16 high-speed pairs, all 16 sideband contacts, the two-wire management contacts
and the REFCLK/VSP contacts alike, with **no exceptions on this connector** —
SFF-9402's exemptions (notes 17 and 18) apply only to power contacts, which
exist on the 80-circuit SFF-8621 and not on the 74-circuit SFF-8654.

**Documents used, named exactly: SFF-9402 Rev 1.1 section 5 implementation
note 16, and its Tables 6-2 and 6-3**, read together with **SFF-8654 Rev 1.2
Figure 3-5** for the contact numbering and **Figure A-1 / Table A-1** for the
land pattern. Note that the real titles differ from the ones in the brief:
SFF-9402 Rev 1.1 is *Multi-Protocol Internal Cable Pinouts for SAS and/or
PCIe*, not "Multilane Copper Cable Assemblies", and SFF-9400 Rev 1.1 is
*Universal 4/8X Pinouts*, not "Multilane Copper Connector and Cable Assembly
Overview". SFF-8654 itself contains **no signal names at all** — its section
3.1 says outright "Refer to documents SFF-9400 and SFF-9402 for the possible
pinout signal assignments", which is why the names come from SFF-9402.

Independently corroborated by two production cable drawings that match the
tables exactly: IcyDock's SFF-8654 4i-to-4i pinout sheet, and Dongguan Aiqun
drawing AQ03-0219A for a 74-position 8i end.

**So: this board drives row A and listens on row B.** The identical board at
the far end drives its row A into this board's row B. Nothing is strapped,
configured or asymmetric.

**Still unverified, and it is the one thing to check with an ohmmeter.**
10Gtek publish no pinout or wiring diagram for CAB-8654/8654-8i-P — not on the
product page, not in the catalogue, not in the family datasheet. The crossover
for that exact part is therefore inferred from the specification it claims to
comply with plus two third-party drawings, not stated by the vendor. Buy one
cable and confirm that a contact in one plug's row A reaches the **other** row,
same number, at the far end. Five minutes, on a cable you are buying anyway.
A warning while doing it: 10Gtek's "straight" versus "right-angle" naming
refers to the connector body's exit direction, not to the internal wiring.
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

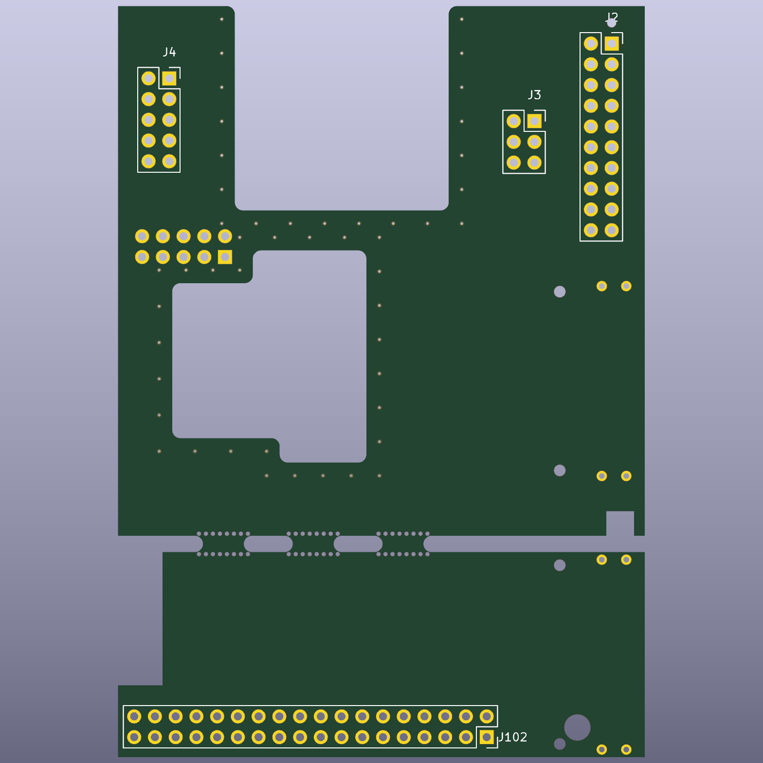
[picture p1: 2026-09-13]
hardware/companions/gowin-bridge/prep-bottom.png

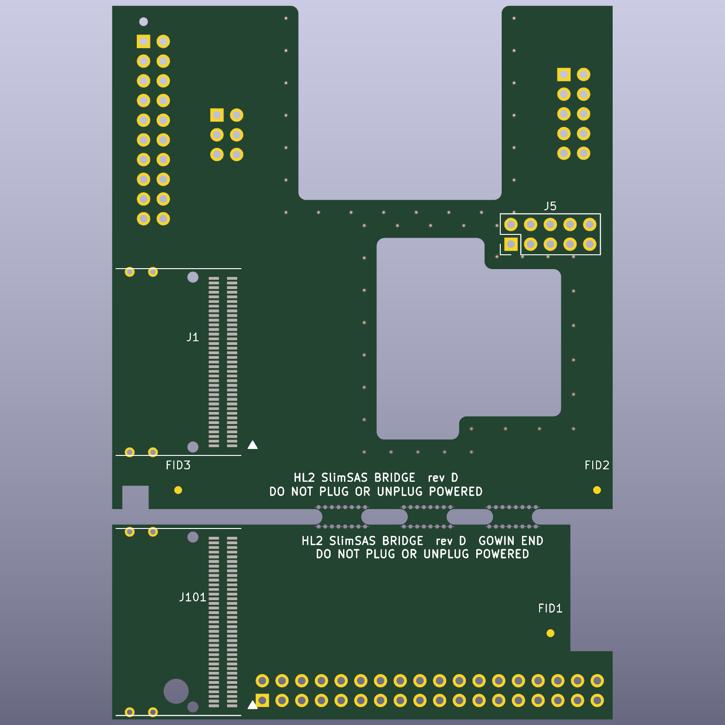
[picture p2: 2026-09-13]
hardware/companions/gowin-bridge/prep-top.png

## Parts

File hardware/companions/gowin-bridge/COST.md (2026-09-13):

# gowin-bridge cost, rev D — one board, both ends

**One design, one board, one order.** Each board carries one radio end and one
Gowin end inside a single outline, joined by three mouse-bite tabs and snapped apart
after assembly. The order is five boards, so five of each and five complete
links. Every figure below comes out of `tools/cost_model.py`, which counts
parts and solder joints from the generated BOM and PCB.

---

## 0. The short answer

Updated 13 Sep 2026 for the risk-review fixes (`DESIGN_NOTES.md` §14).

| | |
|---|---|
| **Order total, five boards, delivered to Germany** | **$162.43** (was $154.84) |
| **One complete link: one radio end plus one Gowin end** | **$32.49** (was $30.97) |
| **The Gowin half**: the Gowin end's parts and joints, five boards | **$21.92** (was $21.91; R103 is now 10 kΩ) |
| The radio-only order it is compared with (rev D, five radio ends, before the fixes) | $132.43 |

Plus, outside the order, per link: the $15.00 cable, $0.86 of hand-fitted
sockets for the radio end, and about $1.05 of stacking parts and a spacer for
the Gowin end.

**What the fixes added: $7.59 on the order.**

| | On the order |
|---|---|
| One new Extended feeder fee: L1, the 4.7 µH filter inductor | $3.07 |
| Radio-end parts, 5 × $0.84: five AO3400A, two RB751V-40, the 100 µF tantalum, L1, two capacitors, eight resistors (the detector discharge, three pull-ups and four input holds) | $4.18 |
| Radio-end solder joints, 5 × 43 × $0.0016 | $0.34 |

**No fee for the detector diodes.** The RB751V-40 (C7502691) is JLCPCB
**Preferred Extended**, which is exempt from the feeder fee on Economic
assembly. The review had assumed a $3.07 fee for it.

**Not fitted, no cost:** the two 10 nF shell-bond capacitors (C30, C101) and
the 0 Ω bypass across L1 (R_LBYP). R_DRVEN_ON and R_DRVEN_PRSNT swapped
roles, so the count is unchanged.

**The board is 64.50 × 92.00 mm**, inside the 100 × 100 mm size band for the
promotional board price, so the board quote is unchanged — unless JLCPCB
counts the two tabbed ends as two designs (`DESIGN_NOTES.md` §13.2). The live
quote gives $7.00 for five boards plus $5.10 for lead-free HASL.

---

## 1. Line by line

JLCPCB, **Economic** assembly, 5 boards, 4 layer, 1.6 mm, lead-free HASL,
green, 1 oz outer, **one design, single PCB**, no impedance control.

### 1.1 Paid once per order

| Charge | Cost |
|---|---|
| Bare PCB: board, 5 pieces, 64.50 × 92.00 mm (quoted at 64.50 × 100.00, same promotional band) | $7.00 |
| Bare PCB: lead-free HASL | $5.10 |
| **Bare PCB subtotal** (live quote, 13 Sep 2026) | **$12.10** |
| Assembly setup | $8.18 |
| Stencil | $1.53 |
| Unique Extended part numbers with a feeder fee, **7** × $3.07 | **$21.49** |
| Shipping, one DHL shipment to Germany | $21.55 |
| **Subtotal, once per order** | **$64.85** |

### 1.2 Paid per board

| Charge | Each | × 5 |
|---|---|---|
| Components, radio end | $14.23 | $71.13 |
| Components, Gowin end | $4.04 | $20.21 |
| SMT joints, radio end, 567 | $0.91 | $4.54 |
| SMT joints, Gowin end, 214 | $0.34 | $1.71 |
| **Subtotal, per board** | **$19.52** | **$97.58** |

| | |
|---|---|
| **Order total** | **$162.43** |
| **Per link** | **$32.49** |

No factory through-hole joints and no hand-soldering fee: every through-hole
socket and header is fitted by the owner.

---

## 2. The Gowin end's parts

| Part | LCSC | Tier | Qty | Unit | Line |
|---|---|---|---|---|---|
| SlimSAS 8i 74P right angle, Amphenol U10A474240T | C5432262 | Ext, **already on the order** | 1 | $3.17 (10+) | $3.17 |
| ESD array TPD4E05U06DQAR | C138714 | Ext, **already on the order** | 12 | $0.0696 (50+) | $0.84 |
| 330 Ω 0402 | C25104 | Basic | 4 | $0.0044 | $0.02 |
| 1 kΩ 0402 | C11702 | Basic | 2 | $0.0022 | $0.00 |
| 10 kΩ 0402 (R103 moved here from 1 kΩ on 13 Sep 2026) | C25744 | Basic | 3 | $0.0031 | $0.01 |
| 0 Ω 0805 | C17477 | Basic | 1 | $0.0045 | $0.00 |
| **Per Gowin end** | | | | | **$4.04** |

Not fitted, no cost: seven 100 Ω optional terminations (C25076) and the
10 nF shell-bond capacitor C101 (C1710).

**Stock to watch:** C5432262 now shows **189** in stock, down from 483 on
12 September. An order needs 10.

### 2.1 Hand-fitted on the Gowin end, per link

The geometry is the same for both mounting schemes; only these parts differ.

| Scheme | Dock J14 positions 5–40 | Adapter | Spacer | Per link |
|---|---|---|---|---|
| **1 — dock on a carrier plate**, stack 7.0–7.5 mm | 2×18 female 5.0 mm, KH-2.54FH-2X18P-H5.0, **C55160396**, $0.45, **only 10 in stock** | 2×18 male HC-PZ254-11.5L-2X18PZ, **C41376109**, $0.19, fitted upside down | M3 × 7 mm, about $0.40 | **$1.04** |
| **2 — dock on the case floor**, stack 11.0 mm | 2×18 male, **C41376109**, $0.19 | 2×18 female 8.5 mm, HX PM2.54-2x18P ZC, **C42372542**, $0.47 | M3 × 11 mm, about $0.40 | **$1.06** |

---

## 3. The radio end's parts

Twenty-four placed part numbers on the whole board since 13 Sep 2026: sixteen
Basic, seven Extended with a fee (the whole $21.49), and one Preferred
Extended with no fee.

| Part | LCSC | Tier | Qty | $ each | Line |
|---|---|---|---|---|---|
| SlimSAS 8i receptacle | C5432262 | Ext | 1 | 3.17 | 3.17 |
| DS90LV047A quad LVDS driver | C206491 | Ext | 2 | 1.84 | 3.68 |
| DS90LV048A quad LVDS receiver | C87137 | Ext | 2 | 1.43 | 2.86 |
| SN74AVC4T245 translator/buffer | C81461 | Ext | 7 | 0.3096 | 2.17 |
| TPD4E05U06 ESD array | C138714 | Ext | 12 | 0.0696 | 0.84 |
| ME6211C25 2.5 V LDO | C194395 | Ext | 1 | 0.0561 | 0.06 |
| **SWPA4030S4R7NT 4.7 µH inductor, the 3.3 V filter (new)** | C193025 | **Ext** | 1 | 0.0856 | 0.09 |
| **RB751V-40 Schottky, the link-alive detector (new)** | C7502691 | **Preferred Ext, no fee** | 2 | 0.0148 | 0.03 |
| AO3400A N-MOSFET: the AUXIO interlock Q1 and **Q2–Q6 (new)** | C20917 | Basic | 6 | 0.0853 | 0.51 |
| **TAJB107K006RNJ 100 µF tantalum, the 3.3 V filter (new)** | C16133 | Basic | 1 | 0.2574 | 0.26 |
| Basic passives and bead (including the new 10 pF, 10 nF, 100 kΩ and seven 10 kΩ) | 14 numbers | Basic | 83 | — | 0.57 |
| **Per radio end** | | | | | **$14.23** |

`DESIGN_NOTES.md` §7 has the full list and why no cheaper part exists for any
of the Extended ones.

---

## 4. What could be cut

| | Change | Saves on this order | Cost to you |
|---|---|---|---|
| 1 | Leaded HASL instead of lead-free | $5.10 | RoHS |
| 2 | DS90LV047A in TSSOP-16 (C87097) instead of SOIC-16 | $4.30 | a little thermal margin |
| 3 | Global Standard shipping instead of DHL | $14.63 | 9–13 days instead of 2–4 |

**Impedance control stays off:** $33.88 including its mandatory file check,
for a 307.2 Mbit/s link whose connector is itself 85 Ω ±10. `DESIGN_NOTES.md`
§3.

---

## 5. Not verified in these numbers

| Item | Worth | Status |
|---|---|---|
| **Shipping** | a few dollars | $21.55 is rev D's Germany quote with assembly, kept unchanged. The bare-PCB quote page on 13 Sep 2026 estimated DHL at $27.63 for 0.23 kg; the real figure comes after the files are uploaded |
| **Whether JLCPCB will solder the SlimSAS shell tails** | $4.24 | 8 tails per board × 5 × $0.0164 + the $3.58 hand-soldering fee, if they do. The costing assumes the owner does |
| **Whether JLCPCB counts the two tabbed ends as two designs, and drops the promotional board price** | a different-design fee and the board at full price; not quoted | ask before ordering, `DESIGN_NOTES.md` §13.2 |
| **Stock of C55160396**, the 5.0 mm socket for scheme 1 | $0.45 a link | 10 in stock on 13 Sep 2026 |
| **Stock of C193025**, the 4.7 µH inductor | the build | about 2,000 in stock on 13 Sep 2026; an order needs 5. Alternative SWPA4020S100MT (C82398) |
| **The RB751V-40's Preferred tier** | $3.07 | read from the JLCPCB library mirror jlcsearch.tscircuit.com (is_preferred), because JLCPCB's own part page does not show the tier to a fetch; JLCPCB's assembly FAQ confirms Preferred Extended parts carry no feeder fee. Check the tier in the JLCPCB BOM tool at upload |

---

## 6. Sources

| | |
|---|---|
| Bare PCB | JLCPCB instant quote, cart.jlcpcb.com, read 13 Sep 2026. Entered: FR-4, 4 layers, 64.5 × 100 mm, PCB qty 5, product type industrial/consumer, **one design, delivery format "Single PCB"**, 1.6 mm, green, white silkscreen, FR4 TG135, **lead-free HASL**, 1 oz outer, 0.5 oz inner, no specified stackup, plugged vias (the 4-layer default), 0.3 mm minimum via, ±0.2 mm outline tolerance, mark on PCB "Remove Mark" (form default, no charge), flying-probe test, 3–4 day build. Returned: special offer (board) $7.00, via covering $0.00, surface finish $5.10, build time $0.00, **calculated price $12.10** |
| Assembly fees | jlcpcb.com/help/article/pcb-assembly-price, read 13 Sep 2026: Economic setup $8.18, stencil $1.53, SMT joint $0.0016, through-hole joint $0.0164, hand soldering $3.58 per order, Extended feeder $3.07 |
| Rails | Removed 13 Sep 2026. jlcpcb.com/capabilities/pcb-assembly-capabilities lists edge rails as "Not necessary" for Economic PCBA; jlcpcb.com/help/article/pcb-assembly-faqs-part-2 asks for traces and components more than 0.3 mm from the edge |
| Gowin-end part prices and stock | LCSC product pages read 13 Sep 2026: C5432262 **189 in stock** (re-read 13 Sep 2026, unchanged; the order needs 10), $3.17 at 10+; C138714 45,175, $0.0696 at 50+; C25744, C11702, C25104, C17477, C25076 all in stock at the prices above; C55160396, C41376109, C42372542 |
| AO3400A | LCSC C20917, read 13 Sep 2026: 461,420 in stock, $0.0853 at 5+; jlcpcb.com/partdetail/C20917: **Basic** |
| Parts added 13 Sep 2026 | JLCPCB library (via jlcsearch.tscircuit.com) and LCSC product pages, read 13 Sep 2026. C7502691 RB751V-40: 628,950 in stock on LCSC, $0.0148 first JLCPCB break, Preferred Extended. C193025 SWPA4030S4R7NT: 1,958 in stock, $0.0856, Extended. C16133 TAJB107K006RNJ: $0.2574, Basic (LCSC retail $0.5261 at 2+). C32949 10 pF C0G: $0.0069, Basic. C15195 10 nF 0402: $0.0035, Basic. C1710 10 nF 0805: $0.0094, Basic. C25741 100 kΩ: 7,417,100 in stock, $0.0028. C25744 10 kΩ: $0.0029–0.0031, Basic. Preferred-part fee rule: jlcpcb.com/help/article/pcb-assembly-faqs |
| Radio-end baseline | `COST.md` as committed in 8405702, $132.43 |
| Joint counts | `tools/cost_model.py`, counted from `bridge/bridge.kicad_pcb` |

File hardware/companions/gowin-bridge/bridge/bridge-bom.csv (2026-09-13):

Designator | Value | Footprint | LCSC | MfrPart | Populate | Function | Note
C1 | 100nF | C_0402_1005Metric | C1525 |  | yes | U1 VCCA
C2 | 100nF | C_0402_1005Metric | C1525 |  | yes | U1 VCCB
C3 | 100nF | C_0402_1005Metric | C1525 |  | yes | U2 VCCA
C4 | 100nF | C_0402_1005Metric | C1525 |  | yes | U2 VCCB
C5 | 100nF | C_0402_1005Metric | C1525 |  | yes | U3 VCCA
C6 | 100nF | C_0402_1005Metric | C1525 |  | yes | U3 VCCB
C7 | 100nF | C_0402_1005Metric | C1525 |  | yes | U4 VCC
C8 | 100nF | C_0402_1005Metric | C1525 |  | yes | U5 VCC
C9 | 100nF | C_0402_1005Metric | C1525 |  | yes | U6 VCC
C10 | 100nF | C_0402_1005Metric | C1525 |  | yes | U7 VCC
C11 | 100nF | C_0402_1005Metric | C1525 |  | yes | U8 VCCA
C12 | 100nF | C_0402_1005Metric | C1525 |  | yes | U8 VCCB
C13 | 100nF | C_0402_1005Metric | C1525 |  | yes | U9 VCCA
C14 | 100nF | C_0402_1005Metric | C1525 |  | yes | U9 VCCB
C15 | 100nF | C_0402_1005Metric | C1525 |  | yes | U10 VCCA
C16 | 100nF | C_0402_1005Metric | C1525 |  | yes | U10 VCCB
C17 | 100nF | C_0402_1005Metric | C1525 |  | yes | U11 VCCA
C18 | 100nF | C_0402_1005Metric | C1525 |  | yes | U11 VCCB
C19 | 100nF | C_0402_1005Metric | C1525 |  | yes | U12 input
C20 | 1uF | C_0402_1005Metric | C52923 |  | yes | U12 output
C21 | 100nF | C_0402_1005Metric | C1525 |  | yes | DB1 +3V3 entry, before FB1
C22 | 100nF | C_0402_1005Metric | C1525 |  | yes | +3V3 bulk, high frequency
C23 | 100nF | C_0402_1005Metric | C1525 |  | yes | +2V5 bulk, high frequency
C24 | 10uF | C_0805_2012Metric | C15850 |  | yes | +3V3 bulk, after FB1. 10 uF 25 V X5R 0805 - kept small on purpose, see the inrush note
C25 | 10uF | C_0805_2012Metric | C15850 |  | yes | +2V5 bulk, U12 output
C26 | 10uF | C_0805_2012Metric | C15850 |  | yes | +3V3 bulk on the DB1 side of FB1, so the bead sees a capacitor on both sides
C27 | 10pF | C_0402_1005Metric | C32949 |  | yes | Link-alive detector pump capacitor, 10 pF C0G. PLACE WITHIN 3 mm OF U11
C28 | 10nF | C_0402_1005Metric | C15195 |  | yes | Link-alive detector hold capacitor, 10 nF
C29 | 100uF | CP_EIA-3528-21_Kemet-B | C16133 | TAJB107K006RNJ | yes | 3.3 V input filter capacitor, 100 uF 6.3 V tantalum, ESR 1.7 ohm, which damps the LC. Return it to ground beside DB1 pins 13/14. PLACE WITHIN 8 mm OF J2 PINS 19/20
C30 | 10nF | C_0805_2012Metric | C1710 |  | DNP | Shell RF bond, 10 nF 0805, beside R_SHELL. PLACE WITHIN 3 mm OF R_SHELL | NOT FITTED. Bring-up trial: lift R_SHELL and fit this, so the shell is DC-open but RF-bonded to ground.
C101 | 10nF | C_0805_2012Metric | C1710 |  | DNP | Shell RF bond, 10 nF 0805, beside R117. PLACE WITHIN 3 mm OF R117 | NOT FITTED. Bring-up trial: lift R117 and fit this, so the shell is DC-open but RF-bonded to ground.
D1 | TPD4E05U06 | USON-10_2.5x1.0mm_P0.5mm | C138714 | TPD4E05U06DQAR | yes | Quad 0.5 pF ESD array, 5.5 V, USON-10 | PLACE WITHIN 5 mm OF THE SlimSAS CONTACTS, on the connector side of the terminations, the series resistors and the buffers, with the shortest possible ground return.
D2 | TPD4E05U06 | USON-10_2.5x1.0mm_P0.5mm | C138714 | TPD4E05U06DQAR | yes | Quad 0.5 pF ESD array, 5.5 V, USON-10 | PLACE WITHIN 5 mm OF THE SlimSAS CONTACTS, on the connector side of the terminations, the series resistors and the buffers, with the shortest possible ground return.
D3 | TPD4E05U06 | USON-10_2.5x1.0mm_P0.5mm | C138714 | TPD4E05U06DQAR | yes | Quad 0.5 pF ESD array, 5.5 V, USON-10 | PLACE WITHIN 5 mm OF THE SlimSAS CONTACTS, on the connector side of the terminations, the series resistors and the buffers, with the shortest possible ground return.
D4 | TPD4E05U06 | USON-10_2.5x1.0mm_P0.5mm | C138714 | TPD4E05U06DQAR | yes | Quad 0.5 pF ESD array, 5.5 V, USON-10 | PLACE WITHIN 5 mm OF THE SlimSAS CONTACTS, on the connector side of the terminations, the series resistors and the buffers, with the shortest possible ground return.
D5 | TPD4E05U06 | USON-10_2.5x1.0mm_P0.5mm | C138714 | TPD4E05U06DQAR | yes | Quad 0.5 pF ESD array, 5.5 V, USON-10 | PLACE WITHIN 5 mm OF THE SlimSAS CONTACTS, on the connector side of the terminations, the series resistors and the buffers, with the shortest possible ground return.
D6 | TPD4E05U06 | USON-10_2.5x1.0mm_P0.5mm | C138714 | TPD4E05U06DQAR | yes | Quad 0.5 pF ESD array, 5.5 V, USON-10 | PLACE WITHIN 5 mm OF THE SlimSAS CONTACTS, on the connector side of the terminations, the series resistors and the buffers, with the shortest possible ground return.
D7 | TPD4E05U06 | USON-10_2.5x1.0mm_P0.5mm | C138714 | TPD4E05U06DQAR | yes | Quad 0.5 pF ESD array, 5.5 V, USON-10 | PLACE WITHIN 5 mm OF THE SlimSAS CONTACTS, on the connector side of the terminations, the series resistors and the buffers, with the shortest possible ground return.
D8 | TPD4E05U06 | USON-10_2.5x1.0mm_P0.5mm | C138714 | TPD4E05U06DQAR | yes | Quad 0.5 pF ESD array, 5.5 V, USON-10 | PLACE WITHIN 5 mm OF THE SlimSAS CONTACTS, on the connector side of the terminations, the series resistors and the buffers, with the shortest possible ground return.
D9 | TPD4E05U06 | USON-10_2.5x1.0mm_P0.5mm | C138714 | TPD4E05U06DQAR | yes | Quad 0.5 pF ESD array, 5.5 V, USON-10 | PLACE WITHIN 5 mm OF THE SlimSAS CONTACTS, on the connector side of the terminations, the series resistors and the buffers, with the shortest possible ground return.
D10 | TPD4E05U06 | USON-10_2.5x1.0mm_P0.5mm | C138714 | TPD4E05U06DQAR | yes | Quad 0.5 pF ESD array, 5.5 V, USON-10 | PLACE WITHIN 5 mm OF THE SlimSAS CONTACTS, on the connector side of the terminations, the series resistors and the buffers, with the shortest possible ground return.
D11 | TPD4E05U06 | USON-10_2.5x1.0mm_P0.5mm | C138714 | TPD4E05U06DQAR | yes | Quad 0.5 pF ESD array, 5.5 V, USON-10 | PLACE WITHIN 5 mm OF THE SlimSAS CONTACTS, on the connector side of the terminations, the series resistors and the buffers, with the shortest possible ground return.
D12 | TPD4E05U06 | USON-10_2.5x1.0mm_P0.5mm | C138714 | TPD4E05U06DQAR | yes | Quad 0.5 pF ESD array, 5.5 V, USON-10 | PLACE WITHIN 5 mm OF THE SlimSAS CONTACTS, on the connector side of the terminations, the series resistors and the buffers, with the shortest possible ground return.
D13 | RB751V-40 | D_SOD-323 | C7502691 | RB751V-40 | yes | Link-alive detector clamp diode: cathode LA_PUMP, anode GND. PLACE WITHIN 3 mm OF U11
D14 | RB751V-40 | D_SOD-323 | C7502691 | RB751V-40 | yes | Link-alive detector rectifier: anode LA_PUMP, cathode LINK_ALIVE. PLACE WITHIN 3 mm OF U11
D101 | TPD4E05U06 | USON-10_2.5x1.0mm_P0.5mm | C138714 | TPD4E05U06DQAR | yes | Quad 0.5 pF ESD array, 5.5 V, USON-10 | PLACE WITHIN 5 mm OF THE SlimSAS CONTACTS.
D102 | TPD4E05U06 | USON-10_2.5x1.0mm_P0.5mm | C138714 | TPD4E05U06DQAR | yes | Quad 0.5 pF ESD array, 5.5 V, USON-10 | PLACE WITHIN 5 mm OF THE SlimSAS CONTACTS.
D103 | TPD4E05U06 | USON-10_2.5x1.0mm_P0.5mm | C138714 | TPD4E05U06DQAR | yes | Quad 0.5 pF ESD array, 5.5 V, USON-10 | PLACE WITHIN 5 mm OF THE SlimSAS CONTACTS.
D104 | TPD4E05U06 | USON-10_2.5x1.0mm_P0.5mm | C138714 | TPD4E05U06DQAR | yes | Quad 0.5 pF ESD array, 5.5 V, USON-10 | PLACE WITHIN 5 mm OF THE SlimSAS CONTACTS.
D105 | TPD4E05U06 | USON-10_2.5x1.0mm_P0.5mm | C138714 | TPD4E05U06DQAR | yes | Quad 0.5 pF ESD array, 5.5 V, USON-10 | PLACE WITHIN 5 mm OF THE SlimSAS CONTACTS.
D106 | TPD4E05U06 | USON-10_2.5x1.0mm_P0.5mm | C138714 | TPD4E05U06DQAR | yes | Quad 0.5 pF ESD array, 5.5 V, USON-10 | PLACE WITHIN 5 mm OF THE SlimSAS CONTACTS.
D107 | TPD4E05U06 | USON-10_2.5x1.0mm_P0.5mm | C138714 | TPD4E05U06DQAR | yes | Quad 0.5 pF ESD array, 5.5 V, USON-10 | PLACE WITHIN 5 mm OF THE SlimSAS CONTACTS.
D108 | TPD4E05U06 | USON-10_2.5x1.0mm_P0.5mm | C138714 | TPD4E05U06DQAR | yes | Quad 0.5 pF ESD array, 5.5 V, USON-10 | PLACE WITHIN 5 mm OF THE SlimSAS CONTACTS.
D109 | TPD4E05U06 | USON-10_2.5x1.0mm_P0.5mm | C138714 | TPD4E05U06DQAR | yes | Quad 0.5 pF ESD array, 5.5 V, USON-10 | PLACE WITHIN 5 mm OF THE SlimSAS CONTACTS.
D110 | TPD4E05U06 | USON-10_2.5x1.0mm_P0.5mm | C138714 | TPD4E05U06DQAR | yes | Quad 0.5 pF ESD array, 5.5 V, USON-10 | PLACE WITHIN 5 mm OF THE SlimSAS CONTACTS.
D111 | TPD4E05U06 | USON-10_2.5x1.0mm_P0.5mm | C138714 | TPD4E05U06DQAR | yes | Quad 0.5 pF ESD array, 5.5 V, USON-10 | PLACE WITHIN 5 mm OF THE SlimSAS CONTACTS.
D112 | TPD4E05U06 | USON-10_2.5x1.0mm_P0.5mm | C138714 | TPD4E05U06DQAR | yes | Quad 0.5 pF ESD array, 5.5 V, USON-10 | PLACE WITHIN 5 mm OF THE SlimSAS CONTACTS.
FB1 | 120R/2A | L_0603_1608Metric | C14709 | BLM18PG121SN1D | yes | Input filter on the 3.3 V the board takes from DB1 pins 19/20. 120 ohm at 100 MHz, 2 A, 50 mOhm, so 15 mV of drop at 300 mA. Keeps this board's switching currents out of the radio's 3.3 V rail, which has no bead, resistor, fuse or TVS of its own between the regulator and the header | JLCPCB Basic. The only Basic bead that combines >=1 A with <=150 mOhm; no Basic bead reaches 600 ohm at that current, and 120 ohm is ample for a rail filter.
FB2 | 120R/2A | L_0603_1608Metric | C14709 | BLM18PG121SN1D | DNP | Input filter for the OPTIONAL Vlvds tap | NOT FITTED. Only fit together with SL_VLVDS and only with U12 removed.
J1 | SlimSAS 8i 74P R/A | SlimSAS_SFF-8654_8i_74P_RightAngle | C5432262 | Amphenol ICC U10A474240T | yes | SlimSAS SFF-8654 8i, 74 position, right angle. 16 differential pairs plus 16 sideband contacts. Row A is driven by this board, row B is received; the cable crosses A(n) to B(n), which is what lets ONE design sit at both ends | Reflow the 74 SMD contacts, then solder the four 2.2 mm through-hole shell tails. Mating face nominally 0.20 mm behind the board edge - see the SLIMSAS comment block for the one dimension no document gave and check it before cutting the panel window. Insertion force 55.5 N max, 250 mating cycles min.
J2 | DB1 2x10 socket | PinSocket_2x10_P2.54mm_Vertical |  | JXTCONN PM2.54-2X10P-H85 (LCSC C42431860) or any 2.54 mm 2x10 vertical female socket | DNP | Mates HL2 DB1. HAND SOLDERED, bottom side | NOT PLACED BY JLCPCB - hand soldered on the underside. DB1 is marked DNI in the HL2 BOM, so the male header on the radio may need soldering too. Pin 1 (FPGA 72) reaches the FPGA only through HL2 solder jumper J25 and is used here for a DC enable level only; if J25 is left open the AUXIO drive feature is simply unavailable and the board is unaffected.
J3 | DB12 2x03 socket | PinSocket_2x03_P2.54mm_Vertical |  | 2.54 mm 2x3P female header, VERTICAL (top entry). LCSC stocks no vertical 2x3 socket - buy a 2x4 and cut it down, or source outside LCSC | DNP | Mates HL2 DB12. HAND SOLDERED, bottom side | NOT PLACED BY JLCPCB. NOTE THE ORDER: pin 5 = FPGA PIN_89 (auxiliary clock in) and pin 6 = FPGA PIN_88 (reverse clock in). rev A of PINMAP.md had these two transposed; check_netlist.py now asserts it. Also: HL2 R17, the optional 100 R LVDS termination between DB12 pins 5 and 6, MUST NOT BE POPULATED - it shorts the two nets together through 100 R.
J4 | CN1 2x05 socket | PinSocket_2x05_P2.54mm_Vertical |  | PM254V-12-10P-H85 (LCSC C492399) or any 2.54 mm 2x5 vertical female socket | DNP | Mates HL2 CN1, the USB-Blaster JTAG header | NOT PLACED BY JLCPCB - hand soldered on the underside. THE TOLERANCE WARNING: this is the third rigid 2.54 mm socket on one board, 54.19 mm from DB1, and HL2_MECHANICAL_ENVELOPE.md 12.2 puts the worst-case misalignment at CN1 relative to DB1 at about +/-0.8 mm against the +/-0.35 mm a 2.54 mm socket takes comfortably. If it will not engage, LEAVE J4 OFF and run a flying 10-way IDC ribbon from CN1 to J5 instead - J5 carries the same ten nets and needs no other change.
J5 | JTAG pass-through | PinHeader_2x05_P2.54mm_Vertical |  | PZ254V-12-10P (LCSC C492422) 2.54 mm 2x5 vertical male header, or DC3-2.54-10PAS (LCSC C2977596) if a keyed boxed header is preferred | DNP | Straight passive pass-through of all ten CN1 nets, so a USB Blaster still plugs in locally with this board fitted. Also the alternative CN1 connection: a flying 10-way IDC ribbon from CN1 to here replaces J4 | PURELY PASSIVE: socket straight through to header, ten nets, no branches other than the four buffered taps. Pins 6, 7 and 8 are left open - unconnected on the HL2 today but nCE/nCS/nCONFIG in Active Serial mode. DO NOT draw supply current from pin 4: it is the programmer VTREF sense line and expects microamps. This board's power comes from DB1 pins 19/20.
J101 | SlimSAS 8i 74P R/A | SlimSAS_SFF-8654_8i_74P_RightAngle_M3 | C5432262 | Amphenol ICC U10A474240T | yes | SlimSAS SFF-8654 8i at the Gowin end. Same part and same contact land pattern as J1 at the radio end, plus the M3 spacer hole over dock hole H7_LU1. Row A is driven by this end, row B is received; the cable crosses A(n) to B(n) | Mating face at dock x 89.73, flush with the dock RJ45 face. Reflow the 74 contacts, hand-solder the four shell tails. The M3 hole under the housing takes a spacer fixed from BELOW: the housing covers the top of it.
J102 | TANG J14 pos 5-40, 2x18 | PinSocket_2x18_P2.54mm_Vertical |  | SCHEME 1: Hong Cheng HC-PZ254-11.5L-2X18PZ, LCSC C41376109, 2x18 male (3.0 mm tail, 2.5 mm insulator, 6.0 mm mating), fitted UPSIDE DOWN: the 3.0 mm end goes down into the dock socket, the 6.0 mm end up through the adapter, soldered on top and clipped. SCHEME 2: hanxia HX PM2.54-2x18P ZC, LCSC C42372542, 2x18 female, 8.5 mm body, on the adapter underside | DNP | Mates Tang Mega 138K dock J14 positions 5-40 (FPGA Bank 4). Pin k of this part is J14 position k+4. HAND SOLDERED, bottom side | NOT PLACED BY JLCPCB. J14 positions 1-4 lie under the SlimSAS connector and are NOT fitted on either side of the stack. Position 11 (pin 7 here) is the dock 5 V rail and is left unconnected; position 12 (pin 8 here) is the only ground. Positions 5-8 are PMOD0 and 21-28 are PMOD1 and the camera: nothing may be plugged into either PMOD socket or the camera connector while fitted. Dock side, scheme 1: kinghelm KH-2.54FH-2X18P-H5.0, LCSC C55160396, 2x18 female, 5.0 mm body, soldered into dock J14 positions 5-40. Dock side, scheme 2: Hong Cheng HC-PZ254-11.5L-2X18PZ, LCSC C41376109, 2x18 male, 2.5 mm insulator, soldered into dock J14 positions 5-40.
L1 | 4.7uH | L_Sunlord_SWPA4030S | C193025 | SWPA4030S4R7NT | yes | 3.3 V input filter inductor, 4.7 uH 2 A 78 mOhm shielded 4 x 4 mm, after FB1. PLACE WITHIN 8 mm OF J2 PINS 19/20
Q1 | AO3400A | SOT-23 | C20917 | AO3400A | yes | AUXIO drive presence interlock: the drive buffer can be enabled only while the gateware enables AND a powered far end asserts presence. N-MOSFET, gate SB_PRSNT_IN, source AUXIO_EN_LA_N (the enable after the link-alive gate Q4), drain AUXIO_OE_N | JLCPCB Basic. With the cable unplugged or the far end unpowered the gate is held at 0 V and the AUXIO drive path is tri-stated whatever the gateware does.
Q2 | AO3400A | SOT-23 | C20917 | AO3400A | yes | Receiver output enable: gate LINK_ALIVE, source GND, drain RX_EN_N. RX_EN_N drives EN* of U6 and U7 and OE* of U3; every output that can drive a radio FPGA pin is high-impedance unless this is on
Q3 | AO3400A | SOT-23 | C20917 | AO3400A | yes | JTAG enable gate: gate LINK_ALIVE, source JTAG_EN_RAW_N (U2 output from FPGA pin 80), drain JTAG_EN_N. Stock gateware drives pin 80 LOW, which alone would enable the JTAG buffers
Q4 | AO3400A | SOT-23 | C20917 | AO3400A | yes | AUXIO enable gate, in series with Q1: gate LINK_ALIVE, source AUXIO_EN_N (U2 output from FPGA pin 72), drain AUXIO_EN_LA_N. Stock gateware drives pin 72 LOW
Q5 | AO3400A | SOT-23 | C20917 | AO3400A | yes | Presence output enable: gate SB_PRSNT_IN, source GND, drain PRSNT_OE_N, which drives OE* of U8 (both ports) and U10 port 1. Far end absent or unpowered: gate held at 0 V by 10 k, PRSNT_OE_N pulled HIGH, both buffers off
Q6 | AO3400A | SOT-23 | C20917 | AO3400A | yes | Link-alive clamp: gate PRSNT_OE_N, source GND, drain LINK_ALIVE. No far end present -> LINK_ALIVE held LOW
R_CLKSEL_A | 0R | R_0402_1005Metric | C17168 |  | yes | Reverse clock into FPGA pin 88 from the PRIMARY clock lane. FITTED by default
R_CLKSEL_B | 0R | R_0402_1005Metric | C17168 |  | DNP | Reverse clock into FPGA pin 88 from the DUPLICATE clock lane instead | NOT FITTED. FIT EXACTLY ONE OF R_CLKSEL_A AND R_CLKSEL_B. This is the hardware half of the duplicate clock: if the primary clock lane loses a trace, a contact or a solder joint, move the link.
R_DRVEN_ON | 0R | R_0402_1005Metric | C17168 |  | DNP | LVDS drivers always enabled. NOT FITTED since 13 Sep 2026: bench use only, with no far end to protect | NOT FITTED. FIT AT MOST ONE OF R_DRVEN_ON AND R_DRVEN_PRSNT.
R_DRVEN_PRSNT | 0R | R_0402_1005Metric | C17168 |  | yes | LVDS drivers enabled only while the far end is present, powered and (at the Gowin end) configured. FITTED since 13 Sep 2026 so a powered radio pushes no LVDS current into an unpowered Tang | FITTED. FIT AT MOST ONE OF R_DRVEN_ON AND R_DRVEN_PRSNT. Needs the sideband cable CAB-8654/8654-8i-P: the no-sideband variant would leave the link dead.
R_SHELL | 0R | R_0805_2012Metric | C17477 |  | yes | Connector shell and its four through-hole tails to board ground. 0805 so the shield can be lifted if a ground loop ever appears
R_LBYP | 0R | R_0805_2012Metric | C17477 |  | DNP | Bypass across L1 for the bring-up noise comparison | NOT FITTED. Fit only to compare the noise floor with the LC filter bypassed.
R1 | 100R | R_0402_1005Metric | C25076 |  | yes | Forward clock divider, series leg. 3.3 V FPGA pin 98 down to 2.50 V for the translator A-side input
R2 | 470R | R_0402_1005Metric | C25117 |  | yes | Forward clock divider, shunt leg. 5.8 mA from pin 98, Thevenin 132 ohm, 320 mV under the 3.0 V A-side absolute maximum at the worst corner
R3 | 330R | R_0402_1005Metric | C25104 |  | yes | AUXIO line 0 series resistor, DB1-10 = FPGA pin 90. Limits contention to 7.4 mA worst case if the radio drives this pin while the DRIVE path is enabled. CW/PTT ring. 2.2k pull-up to +3V3 (R75), 100R to the KEY jack (R77) and 1 uF to ground (C71) on the radio, so its own time constant is 2.2 ms - a DC/slow input, not a signalling pin
R4 | 330R | R_0402_1005Metric | C25104 |  | yes | AUXIO line 1 series resistor, DB1-12 = FPGA pin 91. Limits contention to 7.4 mA worst case if the radio drives this pin while the DRIVE path is enabled. CW/PTT tip. Same network: 2.2k (R76), 100R (R78), 1 uF (C72)
R5 | 330R | R_0402_1005Metric | C25104 |  | yes | AUXIO line 2 series resistor, DB1-16 = FPGA pin 103. Limits contention to 7.4 mA worst case if the radio drives this pin while the DRIVE path is enabled. I2C1 SCL. 4.7k pull-up (R43) and it is a BUS: U6, the IDT 5P49V5923 VersaClock that generates the radio master clock, is on it
R6 | 330R | R_0402_1005Metric | C25104 |  | yes | AUXIO line 3 series resistor, DB1-18 = FPGA pin 104. Limits contention to 7.4 mA worst case if the radio drives this pin while the DRIVE path is enabled. I2C1 SDA. 4.7k pull-up (R44), same bus as SCL1
R7 | 330R | R_0402_1005Metric | C25104 |  | yes | JTAG TCK series resistor, buffer output into CN1 pin 1. Bounds a fight with a locally plugged USB Blaster to about 8 mA, and 330 R into the 15 pF of CN1 plus trace is 5 ns against the 41.7 ns period of a 24 MHz TCK
R8 | 330R | R_0402_1005Metric | C25104 |  | yes | JTAG TMS series resistor, buffer output into CN1 pin 5
R9 | 330R | R_0402_1005Metric | C25104 |  | yes | JTAG TDI series resistor, buffer output into CN1 pin 9
R10 | 330R | R_0402_1005Metric | C25104 |  | yes | JTAG TDO series resistor, CN1 pin 3 into a buffer input. Isolates the HL2 FPGA TDO pin from the cable entirely
R11 | 10k | R_0402_1005Metric | C25744 |  | yes | Defines HL2_ADC_D0 (ADC data 0) while nothing drives it
R12 | 10k | R_0402_1005Metric | C25744 |  | yes | Defines HL2_ADC_D1 (ADC data 1) while nothing drives it
R13 | 10k | R_0402_1005Metric | C25744 |  | yes | Defines HL2_ADC_D2 (ADC data 2) while nothing drives it
R14 | 10k | R_0402_1005Metric | C25744 |  | yes | Defines HL2_AUX_CLK_OUT (auxiliary clock out) while nothing drives it
R15 | 10k | R_0402_1005Metric | C25744 |  | yes | Defines HL2_AUX_DAT_OUT (auxiliary data out) while nothing drives it
R16 | 10k | R_0402_1005Metric | C25744 |  | yes | JTAG-over-cable enable, HL2 side pull-UP. FPGA pin 80 (DB1-4) drives this LOW to enable. The direction matters: pulled up means disabled
R17 | 10k | R_0402_1005Metric | C25744 |  | yes | JTAG-over-cable enable, logic side pull-UP. A missing or unpowered U2 leaves the JTAG buffers tri-stated
R18 | 10k | R_0402_1005Metric | C25744 |  | yes | AUXIO drive enable, HL2 side pull-UP. FPGA pin 72 (DB1-1, through HL2 jumper J25) drives this LOW to enable. With J25 open the feature is simply unavailable
R19 | 10k | R_0402_1005Metric | C25744 |  | yes | AUXIO drive enable, logic side pull-UP. READ-ONLY is the power-up state and the failure state
R20 | 10k | R_0402_1005Metric | C25744 |  | yes | AUXIO drive buffer OE*, pull-UP. Pulled low only through the presence interlock Q1, so with no far end the drive path is tri-stated
R21 | 1k | R_0402_1005Metric | C11702 |  | DNP | JTAG_FORCE: fit to enable JTAG over the cable WITHOUT working HL2 gateware, which is the case you most want it in. On the buffer side of the link-alive gate Q3, because a radio with no link gateware makes no forward clock. 1 k beats the 10 k pull-up (0.30 V); U2 cannot fight it because Q3 is off whenever its source is HIGH | NOT FITTED. This is the recovery path for a radio whose gateware will not run: without it, remote reflashing depends on the gateware you are trying to replace.
R22 | 0R | R_0402_1005Metric | C17168 |  | yes | auxiliary clock (2.5 V) into HL2 pin 89 = DB12-5
R23 | 0R | R_0402_1005Metric | C17168 |  | yes | auxiliary data (2.5 V) into HL2 pin 87 = DB12-2
R24 | 0R | R_0402_1005Metric | C17168 |  | yes | Transmit data lane 0 into DB1-11 (FPGA pin 99, a 3.3 V bank pin carrying LED D3 through 1 k). 0402 pads take 22 R instead if damping is ever wanted
R25 | 0R | R_0402_1005Metric | C17168 |  | yes | Transmit data lane 1 into DB1-15 (FPGA pin 100, a 3.3 V bank pin carrying LED D4 through 1 k). 0402 pads take 22 R instead if damping is ever wanted
R26 | 0R | R_0402_1005Metric | C17168 |  | yes | Transmit data lane 2 into DB1-17 (FPGA pin 101, a 3.3 V bank pin carrying LED D5 through 1 k). 0402 pads take 22 R instead if damping is ever wanted
R27 | 1k | R_0402_1005Metric | C11702 |  | yes | Presence assert: 1 k to +3V3, so the far end reads this board as present ONLY while it is powered. Against the far 10 k it gives 3.0 V at 0.3 mA
R28 | 10k | R_0402_1005Metric | C25744 |  | yes | Presence detect: HIGH = the far end is plugged in AND powered. Also the link-reset input - the far end pulls it low
R29 | 10k | R_0402_1005Metric | C25744 |  | yes | JTAG TCK from the cable, pulled LOW so the buffer input is defined and TCK idles low with nothing plugged in
R30 | 10k | R_0402_1005Metric | C25744 |  | yes | JTAG TMS from the cable, pulled HIGH - the direction that walks a TAP controller to Test-Logic-Reset rather than into it
R31 | 10k | R_0402_1005Metric | C25744 |  | yes | JTAG TDI from the cable, pulled low so the buffer input is defined
R32 | 10k | R_0402_1005Metric | C25744 |  | yes | AUXIO line 0 from the cable, pulled UP to the not-keyed / bus-idle level. A floating, unplugged, unpowered or tri-stated far end therefore presents HIGH, and HIGH is not keyed on CW/PTT and is idle on I2C. NEVER A PULL-DOWN
R33 | 10k | R_0402_1005Metric | C25744 |  | yes | AUXIO line 1 from the cable, pulled UP to the not-keyed / bus-idle level. A floating, unplugged, unpowered or tri-stated far end therefore presents HIGH, and HIGH is not keyed on CW/PTT and is idle on I2C. NEVER A PULL-DOWN
R34 | 10k | R_0402_1005Metric | C25744 |  | yes | AUXIO line 2 from the cable, pulled UP to the not-keyed / bus-idle level. A floating, unplugged, unpowered or tri-stated far end therefore presents HIGH, and HIGH is not keyed on CW/PTT and is idle on I2C. NEVER A PULL-DOWN
R35 | 10k | R_0402_1005Metric | C25744 |  | yes | AUXIO line 3 from the cable, pulled UP to the not-keyed / bus-idle level. A floating, unplugged, unpowered or tri-stated far end therefore presents HIGH, and HIGH is not keyed on CW/PTT and is idle on I2C. NEVER A PULL-DOWN
R36 | 10k | R_0402_1005Metric | C25744 |  | yes | Defines the spare driver channel input
R37 | 100R | R_0402_1005Metric | C25076 |  | yes | 100 ohm differential termination on the received AUXCLK pair (connector B2/B3). PLACE WITHIN 5 mm OF THE RECEIVER PINS
R38 | 100R | R_0402_1005Metric | C25076 |  | yes | 100 ohm differential termination on the received AUXDAT pair (connector B5/B6). PLACE WITHIN 5 mm OF THE RECEIVER PINS
R39 | 100R | R_0402_1005Metric | C25076 |  | yes | 100 ohm differential termination on the received REVCLK pair (connector B14/B15). PLACE WITHIN 5 mm OF THE RECEIVER PINS
R40 | 100R | R_0402_1005Metric | C25076 |  | yes | 100 ohm differential termination on the received TXD0 pair (connector B17/B18). PLACE WITHIN 5 mm OF THE RECEIVER PINS
R41 | 100R | R_0402_1005Metric | C25076 |  | yes | 100 ohm differential termination on the received TXD1 pair (connector B20/B21). PLACE WITHIN 5 mm OF THE RECEIVER PINS
R42 | 100R | R_0402_1005Metric | C25076 |  | yes | 100 ohm differential termination on the received TXD2 pair (connector B23/B24). PLACE WITHIN 5 mm OF THE RECEIVER PINS
R43 | 100R | R_0402_1005Metric | C25076 |  | yes | 100 ohm differential termination on the received DUPCLK pair (connector B32/B33). PLACE WITHIN 5 mm OF THE RECEIVER PINS
R44 | 100R | R_0402_1005Metric | C25076 |  | yes | 100 ohm differential termination on the received SPARE pair (connector B35/B36). PLACE WITHIN 5 mm OF THE RECEIVER PINS
R45 | 100k | R_0402_1005Metric | C25741 |  | yes | Link-alive detector discharge, 100 k: with the 10 nF a 1 ms time constant, so LINK_ALIVE falls within a few ms of the forward clock stopping
R46 | 10k | R_0402_1005Metric | C25744 |  | yes | Receiver enable pull-UP: U3, U6 and U7 outputs high-impedance unless Q2 pulls it low
R47 | 10k | R_0402_1005Metric | C25744 |  | yes | Presence output-enable pull-UP: U8 and U10 port 1 off unless a powered far end is present
R48 | 10k | R_0402_1005Metric | C25744 |  | yes | TDO pull-UP on the buffer input: the FPGA TDO pin floats when not shifting, and a floating CMOS input is not allowed (TI SCES576I, note to 5.3)
R49 | 10k | R_0402_1005Metric | C25744 |  | yes | Defines RX_REVCLK, a U3 input, while the receivers are tri-stated
R50 | 10k | R_0402_1005Metric | C25744 |  | yes | Defines RX_DUPCLK, a U3 input, while the receivers are tri-stated
R51 | 10k | R_0402_1005Metric | C25744 |  | yes | Defines RX_AUXCLK, a U3 input, while the receivers are tri-stated
R52 | 10k | R_0402_1005Metric | C25744 |  | yes | Defines RX_AUXDAT, a U3 input, while the receivers are tri-stated
R101 | 1k | R_0402_1005Metric | C11702 |  | yes | Presence assert and link reset, from J14 position 30. The gateware drives HIGH for present and LOW for link reset; the radio end reads it against its own 10 k pull-down, 3.0 V high
R102 | 10k | R_0402_1005Metric | C25744 |  | yes | Presence detect pull-down, as at the radio end: HIGH only while the radio end is plugged in and powered
R103 | 10k | R_0402_1005Metric | C25744 |  | yes | Presence detect into J14 position 29. 10 k (was 1 k until 13 Sep 2026): in series with the FPGA input only, so reading is unaffected, and injection from a powered radio into an unpowered Tang falls from 1.35 mA to about 0.25 mA
R104 | 330R | R_0402_1005Metric | C25104 |  | yes | JTAG TCK to the radio, from J14 position 34
R105 | 1k | R_0402_1005Metric | C11702 |  | yes | TCK pull-DOWN. Holds TCK low while the Gowin is unconfigured, even against its strongest 400 uA pull-up (0.4 V), so no TCK edge leaves this end until the gateware makes one
R106 | 330R | R_0402_1005Metric | C25104 |  | yes | JTAG TMS to the radio, from J14 position 8
R107 | 330R | R_0402_1005Metric | C25104 |  | yes | JTAG TDI to the radio, from J14 position 33
R108 | 330R | R_0402_1005Metric | C25104 |  | yes | JTAG TDO from the radio into J14 position 7
R109 | 10k | R_0402_1005Metric | C25744 |  | yes | Defines TDO with no radio attached
R110 | 100R | R_0402_1005Metric | C25076 |  | DNP | OPTIONAL external 100 ohm termination on the received AUXCLK pair | NOT FITTED. The FPGA terminates on-die (DIFF_RESISTOR=ON). Fit only if that is ever found not to work.
R111 | 100R | R_0402_1005Metric | C25076 |  | DNP | OPTIONAL external 100 ohm termination on the received AUXDAT pair | NOT FITTED. The FPGA terminates on-die (DIFF_RESISTOR=ON). Fit only if that is ever found not to work.
R112 | 100R | R_0402_1005Metric | C25076 |  | DNP | OPTIONAL external 100 ohm termination on the received FWDCLK pair | NOT FITTED. The FPGA terminates on-die (DIFF_RESISTOR=ON). Fit only if that is ever found not to work.
R113 | 100R | R_0402_1005Metric | C25076 |  | DNP | OPTIONAL external 100 ohm termination on the received ADCD0 pair | NOT FITTED. The FPGA terminates on-die (DIFF_RESISTOR=ON). Fit only if that is ever found not to work.
R114 | 100R | R_0402_1005Metric | C25076 |  | DNP | OPTIONAL external 100 ohm termination on the received ADCD1 pair | NOT FITTED. The FPGA terminates on-die (DIFF_RESISTOR=ON). Fit only if that is ever found not to work.
R115 | 100R | R_0402_1005Metric | C25076 |  | DNP | OPTIONAL external 100 ohm termination on the received ADCD2 pair | NOT FITTED. The FPGA terminates on-die (DIFF_RESISTOR=ON). Fit only if that is ever found not to work.
R116 | 100R | R_0402_1005Metric | C25076 |  | DNP | OPTIONAL external 100 ohm termination on the received DUPCLK pair | NOT FITTED. The FPGA terminates on-die (DIFF_RESISTOR=ON). Fit only if that is ever found not to work.
R117 | 0R | R_0805_2012Metric | C17477 |  | yes | Connector shell to ground, as R_SHELL at the radio end
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

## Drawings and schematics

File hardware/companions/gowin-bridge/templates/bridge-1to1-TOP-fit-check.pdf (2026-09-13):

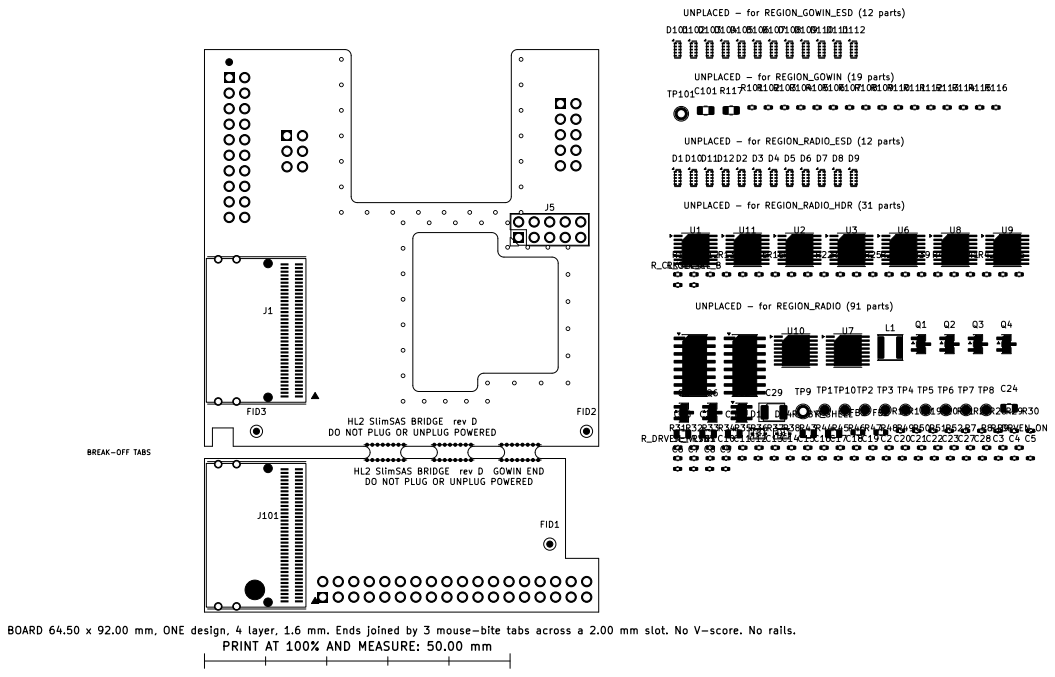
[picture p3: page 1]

DO NOT PLUG OR UNPLUG POWERED HL2 SlimSAS BRIDGE rev D
DO NOT PLUG OR UNPLUG POWERED

HL2 SlimSAS BRIDGE rev D GOWIN END

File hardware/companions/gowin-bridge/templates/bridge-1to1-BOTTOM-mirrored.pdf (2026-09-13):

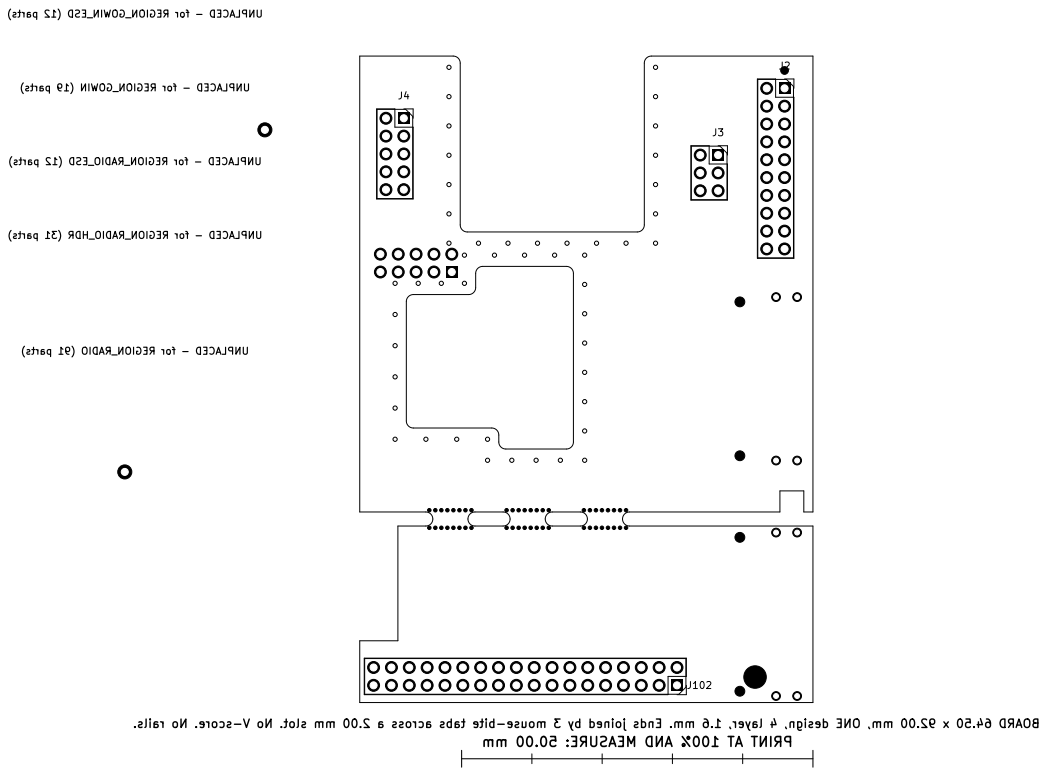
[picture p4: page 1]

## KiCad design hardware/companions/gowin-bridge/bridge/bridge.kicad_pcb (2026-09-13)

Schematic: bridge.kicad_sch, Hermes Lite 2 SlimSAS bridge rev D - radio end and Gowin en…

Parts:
C1, C2, C3, C4, C5, C6, C7, C8, C9, C10, C11, C12, C13, C14, C15, C16, C17, C18, C19, C21, C22, C23: 100nF; C_0402_1005Metric; LCSC C1525
C20: 1uF; C_0402_1005Metric; LCSC C52923
C24, C25, C26: 10uF; C_0805_2012Metric; LCSC C15850
C27: 10pF; C_0402_1005Metric; LCSC C32949
C28: 10nF; C_0402_1005Metric; LCSC C15195
C29: 100uF; CP_EIA-3528-21_Kemet-B; LCSC C16133
C30, C101: 10nF; C_0805_2012Metric; LCSC C1710; not fitted
D1, D2, D3, D4, D5, D6, D7, D8, D9, D10, D11, D12, D101, D102, D103, D104, D105, D106, D107, D108, D109, D110, D111, D112: TPD4E05U06; USON-10_2.5x1.0mm_P0.5mm; LCSC C138714
D13, D14: RB751V-40; D_SOD-323; LCSC C7502691
FB1: 120R/2A; L_0603_1608Metric; LCSC C14709
FB2: 120R/2A; L_0603_1608Metric; LCSC C14709; not fitted
FID1, FID2, FID3: Fiducial; Fiducial_1mm_Mask2mm
J1: SlimSAS 8i 74P R/A; SlimSAS_SFF-8654_8i_74P_RightAngle; LCSC C5432262
J2: DB1 2x10 socket; PinSocket_2x10_P2.54mm_Vertical; not fitted
J3: DB12 2x03 socket; PinSocket_2x03_P2.54mm_Vertical; not fitted
J4: CN1 2x05 socket; PinSocket_2x05_P2.54mm_Vertical; not fitted
J5: JTAG pass-through; PinHeader_2x05_P2.54mm_Vertical; not fitted
J101: SlimSAS 8i 74P R/A; SlimSAS_SFF-8654_8i_74P_RightAngle_M3; LCSC C5432262
J102: TANG J14 pos 5-40, 2x18; PinSocket_2x18_P2.54mm_Vertical; not fitted
L1: 4.7uH; L_Sunlord_SWPA4030S; LCSC C193025
Q1, Q2, Q3, Q4, Q5, Q6: AO3400A; SOT-23; LCSC C20917
R1, R37, R38, R39, R40, R41, R42, R43, R44: 100R; R_0402_1005Metric; LCSC C25076
R2: 470R; R_0402_1005Metric; LCSC C25117
R3, R4, R5, R6, R7, R8, R9, R10, R104, R106, R107, R108: 330R; R_0402_1005Metric; LCSC C25104
R11, R12, R13, R14, R15, R16, R17, R18, R19, R20, R28, R29, R30, R31, R32, R33, R34, R35, R36, R46, R47, R48, R49, R50, R51, R52, R102, R103, R109: 10k; R_0402_1005Metric; LCSC C25744
R21: 1k; R_0402_1005Metric; LCSC C11702; not fitted
R22, R23, R24, R25, R26: 0R; R_0402_1005Metric; LCSC C17168
R27, R101, R105: 1k; R_0402_1005Metric; LCSC C11702
R45: 100k; R_0402_1005Metric; LCSC C25741
R110, R111, R112, R113, R114, R115, R116: 100R; R_0402_1005Metric; LCSC C25076; not fitted
R117: 0R; R_0805_2012Metric; LCSC C17477
R_CLKSEL_A: 0R; R_0402_1005Metric; LCSC C17168
R_CLKSEL_B: 0R; R_0402_1005Metric; LCSC C17168; not fitted
R_DRVEN_ON: 0R; R_0402_1005Metric; LCSC C17168; not fitted
R_DRVEN_PRSNT: 0R; R_0402_1005Metric; LCSC C17168
R_LBYP: 0R; R_0805_2012Metric; LCSC C17477; not fitted
R_SHELL: 0R; R_0805_2012Metric; LCSC C17477
SL_VLVDS: 0R; R_0402_1005Metric; LCSC C17168; not fitted
TP1: TP_+3V3; TestPoint_Pad_D1.5mm
TP2: TP_+2V5; TestPoint_Pad_D1.5mm
TP3: TP_SB_PRSNT_IN; TestPoint_Pad_D1.5mm
TP4: TP_JTAG_EN_N; TestPoint_Pad_D1.5mm
TP5: TP_AUXIO_EN_N; TestPoint_Pad_D1.5mm
TP6: TP_AUXIO_OE_N; TestPoint_Pad_D1.5mm
TP7: TP_HL2_FWD_CLK; TestPoint_Pad_D1.5mm
TP8: TP_HL2_REV_CLK; TestPoint_Pad_D1.5mm
TP9: TP_GND; TestPoint_THTPad_D2.0mm_Drill1.0mm
TP10: TP_LINK_ALIVE; TestPoint_Pad_D1.5mm
TP101: TP_G_GND; TestPoint_THTPad_D2.0mm_Drill1.0mm
U1, U2, U3, U8, U9, U10, U11: SN74AVC4T245PW; TSSOP-16_4.4x5mm_P0.65mm; LCSC C81461
U4, U5: DS90LV047A; SOIC-16_3.9x9.9mm_P1.27mm; LCSC C206491
U6, U7: DS90LV048A; TSSOP-16_4.4x5mm_P0.65mm; LCSC C87137
U12: ME6211C25M5G; SOT-23-5; LCSC C194395

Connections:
+2V5: C1.1, C3.1, C6.1, C20.1, C23.1, C25.1, R16.2, R18.2, SL_VLVDS.2, TP2.1, U1.1 (VCCA), U1.2 (1DIR), U1.3 (2DIR), U2.1 (VCCA), U2.2 (1DIR), U2.3 (2DIR), U3.16 (VCCB), U12.5 (V_{OUT})
+3V3: C2.1, C4.1, C5.1, C7.1, C8.1, C9.1, C10.1, C11.1, C12.1, C13.1, C14.1, C15.1, C16.1, C17.1, C18.1, C19.1, C22.1, C24.1, C29.1, L1.2, R17.2, R19.2, R20.2, R27.2, R30.2, R32.2, R33.2, R34.2, R35.2, R46.2, R47.2, R48.2, R_DRVEN_ON.2, R_LBYP.2, TP1.1, U1.16 (VCCB), U2.16 (VCCB), U3.1 (VCCA), U3.2 (1DIR), U3.3 (2DIR), U4.4 (VCC), U5.4 (VCC), U6.13 (VCC), U6.16 (EN), U7.13 (VCC), U7.16 (EN), U8.1 (VCCA), U8.2 (1DIR), U8.3 (2DIR), U8.16 (VCCB), U9.1 (VCCA), U9.2 (1DIR), U9.3 (2DIR), U9.16 (VCCB), U10.1 (VCCA), U10.2 (1DIR), U10.3 (2DIR), U10.16 (VCCB), U11.1 (VCCA), U11.2 (1DIR), U11.3 (2DIR), U11.16 (VCCB), U12.1 (V_{IN}), U12.3 (CE)
AUXIO0_T: R3.2, U8.4 (1A1), U9.13 (1B1)
AUXIO1_T: R4.2, U8.5 (1A2), U9.12 (1B2)
AUXIO2_T: R5.2, U8.6 (2A1), U9.11 (2B1)
AUXIO3_T: R6.2, U8.7 (2A2), U9.10 (2B2)
AUXIO_EN_LA_N: Q1.2 (S), Q4.3 (D)
AUXIO_EN_N: Q4.2 (S), R19.1, TP5.1, U2.10 (2B2)
AUXIO_OE_N: Q1.3 (D), R20.1, TP6.1, U9.14 (2~OE), U9.15 (1~OE)
A_ADCD0_N: D4.2 (D1-), J1.A18, U4.13 (DOUT2-)
A_ADCD0_P: D4.1 (D1+), J1.A17, U4.14 (DOUT2+)
A_ADCD1_N: D5.2 (D1-), J1.A21, U4.12 (DOUT3-)
A_ADCD1_P: D5.1 (D1+), J1.A20, U4.11 (DOUT3+)
A_ADCD2_N: D6.2 (D1-), J1.A24, U4.9 (DOUT4-)
A_ADCD2_P: D6.1 (D1+), J1.A23, U4.10 (DOUT4+)
A_AUXCLK_N: D1.2 (D1-), J1.A3, U5.13 (DOUT2-)
A_AUXCLK_P: D1.1 (D1+), J1.A2, U5.14 (DOUT2+)
A_AUXDAT_N: D2.2 (D1-), J1.A6, U5.12 (DOUT3-)
A_AUXDAT_P: D2.1 (D1+), J1.A5, U5.11 (DOUT3+)
A_DUPCLK_N: D7.2 (D1-), J1.A33, U5.16 (DOUT1-)
A_DUPCLK_P: D7.1 (D1+), J1.A32, U5.15 (DOUT1+)
A_FWDCLK_N: D3.2 (D1-), J1.A15, U4.16 (DOUT1-)
A_FWDCLK_P: D3.1 (D1+), J1.A14, U4.15 (DOUT1+)
A_SPARE_N: D8.2 (D1-), J1.A36, U5.9 (DOUT4-)
A_SPARE_P: D8.1 (D1+), J1.A35, U5.10 (DOUT4+)
B_AUXCLK_N: D1.5 (D2-), J1.B3, R37.2, U7.4 (RIN2-)
B_AUXCLK_P: D1.4 (D2+), J1.B2, R37.1, U7.3 (RIN2+)
B_AUXDAT_N: D2.5 (D2-), J1.B6, R38.2, U7.5 (RIN3-)
B_AUXDAT_P: D2.4 (D2+), J1.B5, R38.1, U7.6 (RIN3+)
B_DUPCLK_N: D7.5 (D2-), J1.B33, R43.2, U7.1 (RIN1-)
B_DUPCLK_P: D7.4 (D2+), J1.B32, R43.1, U7.2 (RIN1+)
B_REVCLK_N: D3.5 (D2-), J1.B15, R39.2, U6.1 (RIN1-)
B_REVCLK_P: D3.4 (D2+), J1.B14, R39.1, U6.2 (RIN1+)
B_SPARE_N: D8.5 (D2-), J1.B36, R44.2, U7.8 (RIN4-)
B_SPARE_P: D8.4 (D2+), J1.B35, R44.1, U7.7 (RIN4+)
B_TXD0_N: D4.5 (D2-), J1.B18, R40.2, U6.4 (RIN2-)
B_TXD0_P: D4.4 (D2+), J1.B17, R40.1, U6.3 (RIN2+)
B_TXD1_N: D5.5 (D2-), J1.B21, R41.2, U6.5 (RIN3-)
B_TXD1_P: D5.4 (D2+), J1.B20, R41.1, U6.6 (RIN3+)
B_TXD2_N: D6.5 (D2-), J1.B24, R42.2, U6.8 (RIN4-)
B_TXD2_P: D6.4 (D2+), J1.B23, R42.1, U6.7 (RIN4+)
CN1_NC6: J4.6, J5.6
CN1_NC7: J4.7, J5.7
CN1_NC8: J4.8, J5.8
CN1_VTREF: J4.4, J5.4
DB1_3V3: C21.1, C26.1, FB1.1, J2.19, J2.20
DI_ADCD0: U1.12 (1B2), U4.3 (DIN2)
DI_ADCD1: U1.11 (2B1), U4.6 (DIN3)
DI_ADCD2: U1.10 (2B2), U4.7 (DIN4)
DI_AUXCLK: U2.13 (1B1), U5.3 (DIN2)
DI_AUXDAT: U2.12 (1B2), U5.6 (DIN3)
DI_FWDCLK: U1.13 (1B1), U4.2 (DIN1), U5.2 (DIN1), U11.6 (2A1)
DI_SPARE: R36.1, U5.7 (DIN4)
DRV_EN: R_DRVEN_ON.1, R_DRVEN_PRSNT.1, U4.1 (EN), U5.1 (EN)
GND: C1.2, C2.2, C3.2, C4.2, C5.2, C6.2, C7.2, C8.2, C9.2, C10.2, C11.2, C12.2, C13.2, C14.2, C15.2, C16.2, C17.2, C18.2, C19.2, C20.2, C21.2, C22.2, C23.2, C24.2, C25.2, C26.2, C28.2, C29.2, C30.2, D1.3 (GND), D1.8 (GND), D2.3 (GND), D2.8 (GND), D3.3 (GND), D3.8 (GND), D4.3 (GND), D4.8 (GND), D5.3 (GND), D5.8 (GND), D6.3 (GND), D6.8 (GND), D7.3 (GND), D7.8 (GND), D8.3 (GND), D8.8 (GND), D9.3 (GND), D9.8 (GND), D10.3 (GND), D10.8 (GND), D11.3 (GND), D11.8 (GND), D12.3 (GND), D12.8 (GND), D13.2 (A), J1.A1, J1.A4, J1.A7, J1.A10, J1.A13, J1.A16, J1.A19, J1.A22, J1.A25, J1.A28, J1.A31, J1.A34, J1.A37, J1.B1, J1.B4, J1.B7, J1.B10, J1.B13, J1.B16, J1.B19, J1.B22, J1.B25, J1.B28, J1.B31, J1.B34, J1.B37, J2.13, J2.14, J3.3, J3.4, J4.2, J4.10, J5.2, J5.10, Q2.2 (S), Q5.2 (S), Q6.2 (S), R2.2, R11.2, R12.2, R13.2, R14.2, R15.2, R21.2, R28.2, R29.2, R31.2, R36.2, R45.2, R49.2, R50.2, R51.2, R52.2, R_SHELL.2, TP9.1, U1.8 (GND), U1.9 (GND), U1.14 (2~OE), U1.15 (1~OE), U2.8 (GND), U2.9 (GND), U2.14 (2~OE), U2.15 (1~OE), U3.8 (GND), U3.9 (GND), U4.5 (GND), U4.8 (~EN), U5.5 (GND), U5.8 (~EN), U6.12 (GND), U7.12 (GND), U8.8 (GND), U8.9 (GND), U9.8 (GND), U9.9 (GND), U10.5 (1A2), U10.8 (GND), U10.9 (GND), U11.5 (1A2), U11.7 (2A2), U11.8 (GND), U11.9 (GND), U11.14 (2~OE), U12.2 (V_{SS})
G_A_AUXCLK_N: D101.2 (D1-), J101.A3, J102.23
G_A_AUXCLK_P: D101.1 (D1+), J101.A2, J102.24
G_A_AUXDAT_N: D102.2 (D1-), J101.A6, J102.17
G_A_AUXDAT_P: D102.1 (D1+), J101.A5, J102.18
G_A_DUPCLK_N: D107.2 (D1-), J101.A33, J102.1
G_A_DUPCLK_P: D107.1 (D1+), J101.A32, J102.2
G_A_REVCLK_N: D103.2 (D1-), J101.A15, J102.5
G_A_REVCLK_P: D103.1 (D1+), J101.A14, J102.6
G_A_SPARE_N: D108.2 (D1-), J101.A36
G_A_SPARE_P: D108.1 (D1+), J101.A35
G_A_TXD0_N: D104.2 (D1-), J101.A18, J102.31
G_A_TXD0_P: D104.1 (D1+), J101.A17, J102.32
G_A_TXD1_N: D105.2 (D1-), J101.A21, J102.33
G_A_TXD1_P: D105.1 (D1+), J101.A20, J102.34
G_A_TXD2_N: D106.2 (D1-), J101.A24, J102.35
G_A_TXD2_P: D106.1 (D1+), J101.A23, J102.36
G_B_ADCD0_N: D104.5 (D2-), J101.B18, J102.13, R113.2
G_B_ADCD0_P: D104.4 (D2+), J101.B17, J102.14, R113.1
G_B_ADCD1_N: D105.5 (D2-), J101.B21, J102.11, R114.2
G_B_ADCD1_P: D105.4 (D2+), J101.B20, J102.12, R114.1
G_B_ADCD2_N: D106.5 (D2-), J101.B24, J102.9, R115.2
G_B_ADCD2_P: D106.4 (D2+), J101.B23, J102.10, R115.1
G_B_AUXCLK_N: D101.5 (D2-), J101.B3, J102.19, R110.2
G_B_AUXCLK_P: D101.4 (D2+), J101.B2, J102.20, R110.1
G_B_AUXDAT_N: D102.5 (D2-), J101.B6, J102.21, R111.2
G_B_AUXDAT_P: D102.4 (D2+), J101.B5, J102.22, R111.1
G_B_DUPCLK_N: D107.5 (D2-), J101.B33, J102.27, R116.2
G_B_DUPCLK_P: D107.4 (D2+), J101.B32, J102.28, R116.1
G_B_FWDCLK_N: D103.5 (D2-), J101.B15, J102.15, R112.2
G_B_FWDCLK_P: D103.4 (D2+), J101.B14, J102.16, R112.1
G_B_SPARE_N: D108.5 (D2-), J101.B36
G_B_SPARE_P: D108.4 (D2+), J101.B35
G_GND: C101.2, D101.3 (GND), D101.8 (GND), D102.3 (GND), D102.8 (GND), D103.3 (GND), D103.8 (GND), D104.3 (GND), D104.8 (GND), D105.3 (GND), D105.8 (GND), D106.3 (GND), D106.8 (GND), D107.3 (GND), D107.8 (GND), D108.3 (GND), D108.8 (GND), D109.3 (GND), D109.8 (GND), D110.3 (GND), D110.8 (GND), D111.3 (GND), D111.8 (GND), D112.3 (GND), D112.8 (GND), J101.A1, J101.A4, J101.A7, J101.A10, J101.A13, J101.A16, J101.A19, J101.A22, J101.A25, J101.A28, J101.A31, J101.A34, J101.A37, J101.B1, J101.B4, J101.B7, J101.B10, J101.B13, J101.B16, J101.B19, J101.B22, J101.B25, J101.B28, J101.B31, J101.B34, J101.B37, J102.8, R102.2, R105.2, R109.2, R117.2, TP101.1
G_PRSNT_DRV: J102.26, R101.1
G_PRSNT_RD: J102.25, R103.2
G_SB_NC_A11: D110.1 (D1+), J101.A11
G_SB_NC_A12: D110.4 (D2+), J101.A12
G_SB_NC_A26: D111.1 (D1+), J101.A26
G_SB_NC_A27: D111.4 (D2+), J101.A27
G_SB_NC_B9: D109.5 (D2-), J101.B9
G_SB_NC_B11: D110.2 (D1-), J101.B11
G_SB_NC_B12: D110.5 (D2-), J101.B12
G_SB_NC_B26: D111.2 (D1-), J101.B26
G_SB_NC_B27: D111.5 (D2-), J101.B27
G_SB_NC_B29: D112.2 (D1-), J101.B29
G_SB_PRSNT_IN: D109.2 (D1-), J101.B8, R102.1, R103.1
G_SB_PRSNT_OUT: D109.1 (D1+), J101.A8, R101.2
G_SB_TCK_OUT: D109.4 (D2+), J101.A9, R104.2
G_SB_TDI_OUT: D112.4 (D2+), J101.A30, R107.2
G_SB_TDO_IN: D112.5 (D2-), J101.B30, R108.1, R109.1
G_SB_TMS_OUT: D112.1 (D1+), J101.A29, R106.2
G_SHELL: C101.1, J101.SH1 (SHELL1), J101.SH2 (SHELL2), J101.SH3 (SHELL3), J101.SH4 (SHELL4), R117.1
G_TCK_DRV: J102.30, R104.1, R105.1
G_TDI_DRV: J102.29, R107.1
G_TDO_RD: J102.3, R108.2
G_TMS_DRV: J102.4, R106.1
HL2_ADC_D0: J2.2, R11.1, U1.5 (1A2)
HL2_ADC_D1: J2.3, R12.1, U1.6 (2A1)
HL2_ADC_D2: J2.5, R13.1, U1.7 (2A2)
HL2_AUXIO_EN: J2.1, R18.1, U2.7 (2A2)
HL2_AUX_CLK_IN: J3.5, R22.2
HL2_AUX_CLK_OUT: J2.6, R14.1, U2.4 (1A1)
HL2_AUX_DAT_IN: J3.2, R23.2
HL2_AUX_DAT_OUT: J3.1, R15.1, U2.5 (1A2)
HL2_CWR: J2.10, R3.1
HL2_CWT: J2.12, R4.1
HL2_FWD_CLK: R1.2, R2.1, TP7.1, U1.4 (1A1)
HL2_FWD_CLK_RAW: J2.9, R1.1
HL2_JTAG_EN: J2.4, R16.1, U2.6 (2A1)
HL2_REV_CLK: J3.6, R_CLKSEL_A.2, R_CLKSEL_B.2, TP8.1
HL2_SCL1: J2.16, R5.1
HL2_SDA1: J2.18, R6.1
HL2_TX_D0: J2.11, R24.2
HL2_TX_D1: J2.15, R25.2
HL2_TX_D2: J2.17, R26.2
JTAG_EN_N: Q3.3 (D), R17.1, R21.1, TP4.1, U10.14 (2~OE), U11.15 (1~OE)
JTAG_EN_RAW_N: Q3.2 (S), U2.11 (2B1)
J_TCK: J4.1, J5.1, R7.2
J_TDI: J4.9, J5.9, R9.2
J_TDO: J4.3, J5.3, R10.1
J_TDO_T: R10.2, R48.1, U10.4 (1A1)
J_TMS: J4.5, J5.5, R8.2
LA_CLK: C27.1, U11.11 (2B1)
LA_PUMP: C27.2, D13.1 (K), D14.2 (A)
LINK_ALIVE: C28.1, D14.1 (K), Q2.1 (G), Q3.1 (G), Q4.1 (G), Q6.3 (D), R45.1, TP10.1
P3V3_FB: FB1.2, L1.1, R_LBYP.1
PRSNT_OE_N: Q5.3 (D), Q6.1 (G), R47.1, U8.14 (2~OE), U8.15 (1~OE), U10.15 (1~OE)
RX_AUXCLK: R51.1, U3.6 (2A1), U7.14 (ROUT2)
RX_AUXDAT: R52.1, U3.7 (2A2), U7.11 (ROUT3)
RX_DUPCLK: R50.1, U3.5 (1A2), U7.15 (ROUT1)
RX_EN_N: Q2.3 (D), R46.1, U3.14 (2~OE), U3.15 (1~OE), U6.9 (~EN), U7.9 (~EN)
RX_REVCLK: R49.1, U3.4 (1A1), U6.15 (ROUT1)
RX_TXD0: R24.1, U6.14 (ROUT2)
RX_TXD1: R25.1, U6.11 (ROUT3)
RX_TXD2: R26.1, U6.10 (ROUT4)
SB_AUXIO0_IN: D10.2 (D1-), J1.B11, R32.1, U9.4 (1A1)
SB_AUXIO0_OUT: D10.1 (D1+), J1.A11, U8.13 (1B1)
SB_AUXIO1_IN: D10.5 (D2-), J1.B12, R33.1, U9.5 (1A2)
SB_AUXIO1_OUT: D10.4 (D2+), J1.A12, U8.12 (1B2)
SB_AUXIO2_IN: D11.2 (D1-), J1.B26, R34.1, U9.6 (2A1)
SB_AUXIO2_OUT: D11.1 (D1+), J1.A26, U8.11 (2B1)
SB_AUXIO3_IN: D11.5 (D2-), J1.B27, R35.1, U9.7 (2A2)
SB_AUXIO3_OUT: D11.4 (D2+), J1.A27, U8.10 (2B2)
SB_NC9: D9.4 (D2+), J1.A9
SB_NC29: D12.1 (D1+), J1.A29
SB_PRSNT_IN: D9.2 (D1-), J1.B8, Q1.1 (G), Q5.1 (G), R28.1, R_DRVEN_PRSNT.2, TP3.1
SB_PRSNT_OUT: D9.1 (D1+), J1.A8, R27.1
SB_TCK_IN: D9.5 (D2-), J1.B9, R29.1, U10.6 (2A1)
SB_TCK_IN_B: R7.1, U10.11 (2B1)
SB_TDI_IN: D12.5 (D2-), J1.B30, R31.1, U11.4 (1A1)
SB_TDI_IN_B: R9.1, U11.13 (1B1)
SB_TDO_OUT: D12.4 (D2+), J1.A30, U10.13 (1B1)
SB_TMS_IN: D12.2 (D1-), J1.B29, R30.1, U10.7 (2A2)
SB_TMS_IN_B: R8.1, U10.10 (2B2)
SHELL: C30.1, J1.SH1 (SHELL1), J1.SH2 (SHELL2), J1.SH3 (SHELL3), J1.SH4 (SHELL4), R_SHELL.1
VLVDS: FB2.1, J2.7, J2.8
VLVDS_F: FB2.2, SL_VLVDS.1
X_AUXCLK25: R22.1, U3.11 (2B1)
X_AUXDAT25: R23.1, U3.10 (2B2)
X_DUPCLK25: R_CLKSEL_B.1, U3.12 (1B2)
X_REVCLK25: R_CLKSEL_A.1, U3.13 (1B1)

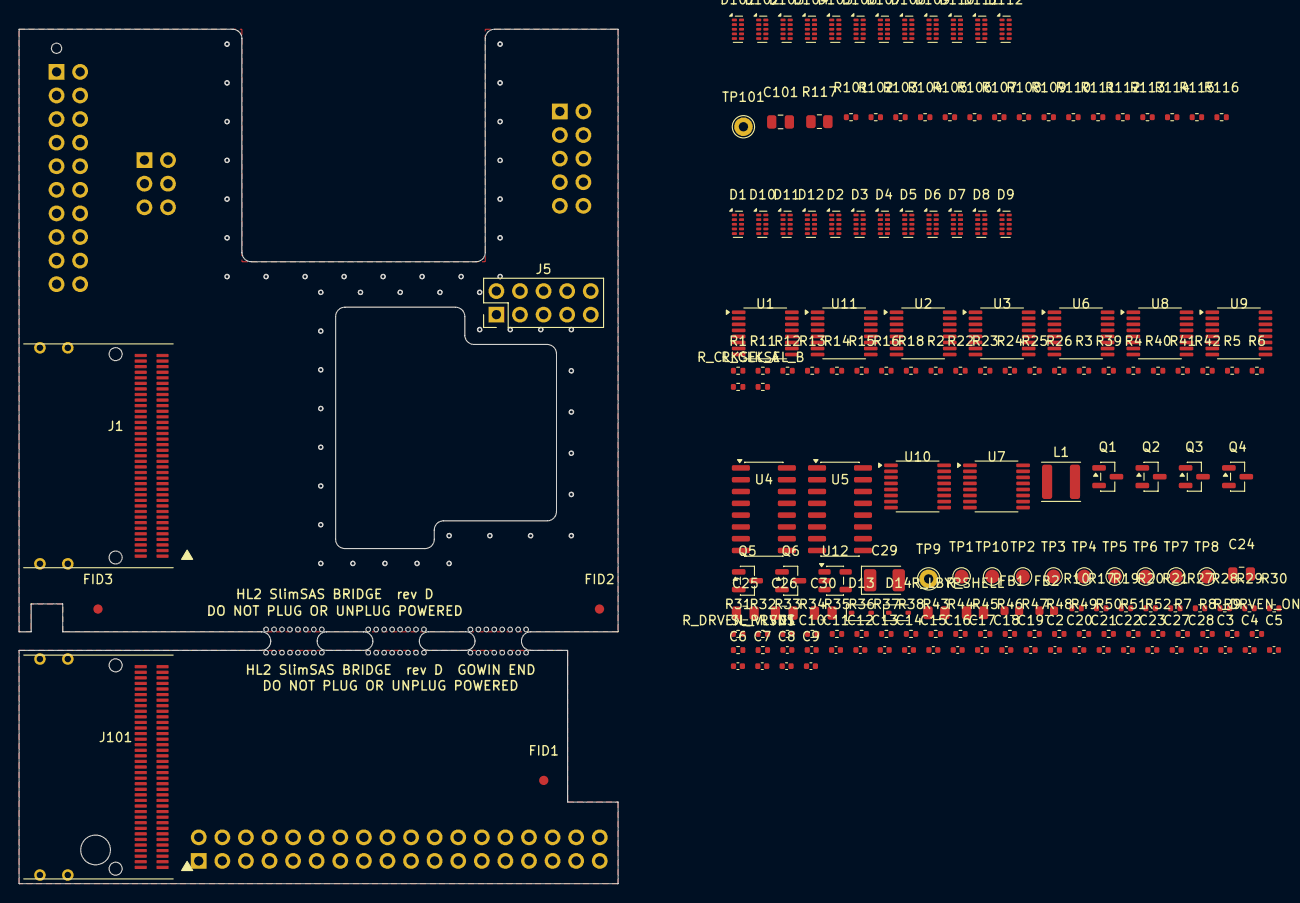
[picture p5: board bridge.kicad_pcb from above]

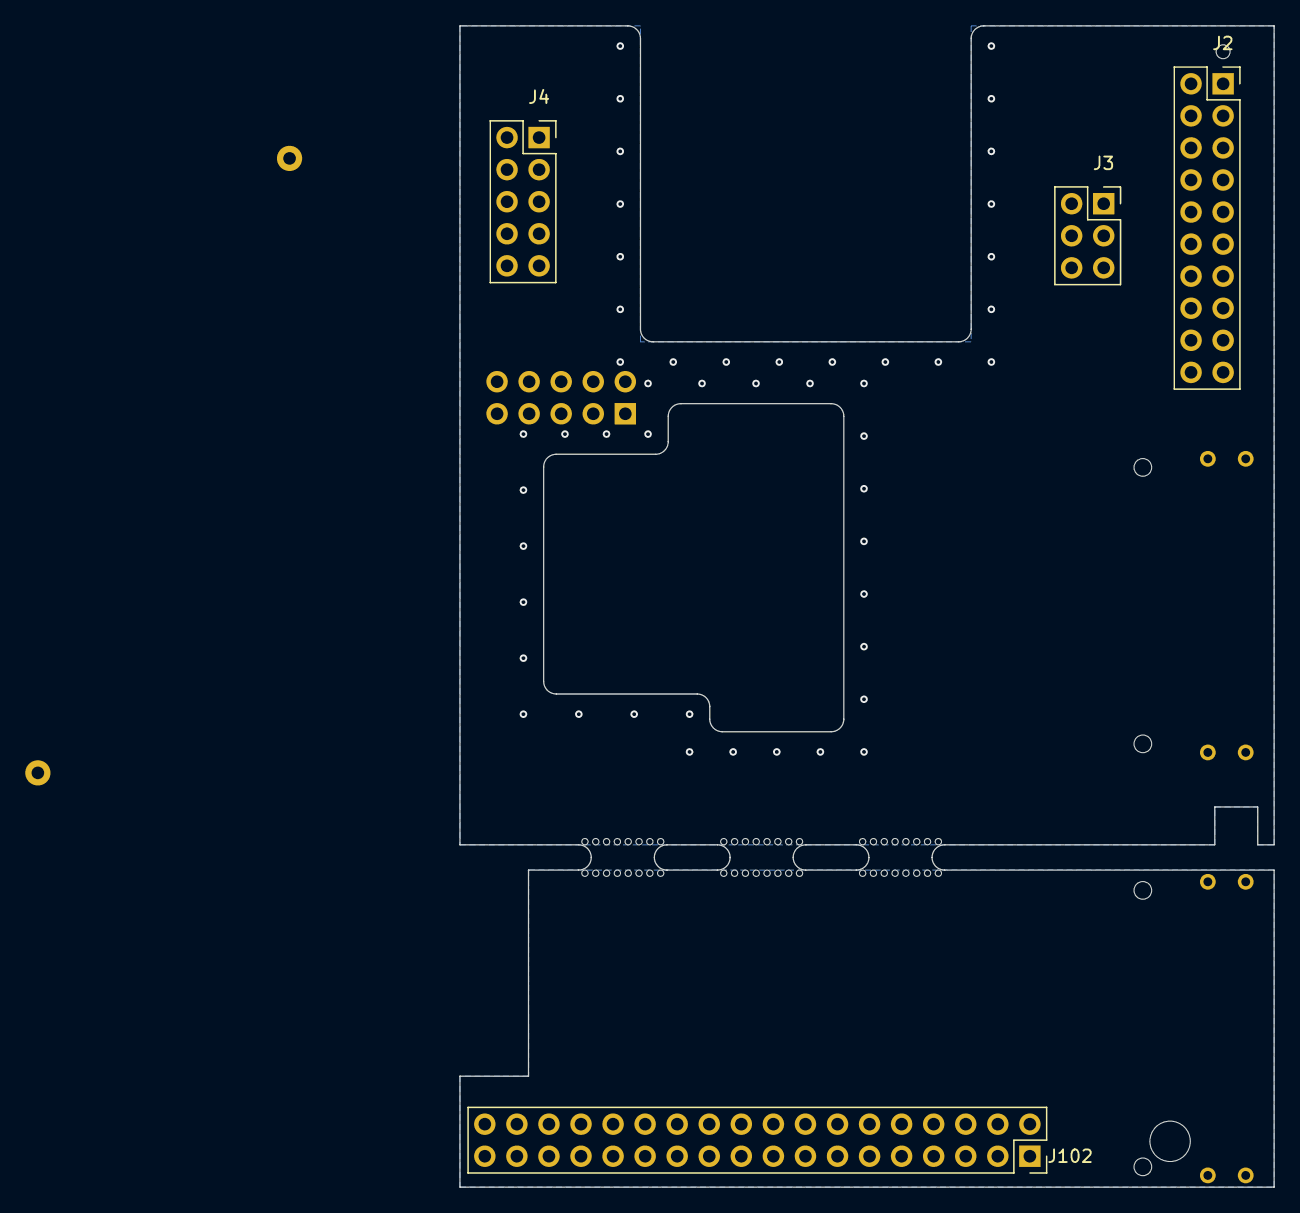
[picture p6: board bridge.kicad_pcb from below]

Board: 4 copper layers, 64.5 x 92.0 mm, 224 parts (4 on the bottom side), 176 nets, no tracks yet.

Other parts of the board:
MB1, MB2, MB3, MB4, MB5, MB6, MB7, MB8, MB9, MB10, MB11, MB12, MB13, MB14, MB15, MB16, MB17, MB18, MB19, MB20, MB21, MB22, MB23, MB24, MB25, MB26, MB27, MB28, MB29, MB30, MB31, MB32, MB33, MB34, MB35, MB36, MB37, MB38, MB39, MB40, MB41, MB42, MB43, MB44, MB45, MB46, MB47, MB48, MB49: Drill

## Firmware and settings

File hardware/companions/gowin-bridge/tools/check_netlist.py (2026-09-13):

#!/usr/bin/env python3
"""Netlist self-check for the generated gowin-bridge board, rev D.

Run:   python tools/check_netlist.py

Exports the schematic's netlist with kicad-cli and asserts the things the
generator could get wrong without ERC noticing:

 1. THE HEADER PIN MAPS.  Every pin of HL2 DB1, DB12 and CN1, against the
    table in PINMAP.md rev D - including the one that has been wrong before:
    DB12 pin 5 is FPGA PIN_89 and pin 6 is PIN_88, NOT the other way round.

 2. THE CONNECTOR PIN MAP.  Every one of the 74 SlimSAS contacts: the 26
    grounds are grounded, the 16 pairs carry the right net legs with P on the
    lower-numbered contact, and the 16 sideband contacts carry what the
    sideband table says.

 3. THE CROSSOVER, WALKED.  Two of these identical boards joined by one
    SFF-8654 8i cable.  The cable maps A(n) at one end to B(n) at the other,
    so the check walks every driven contact through to the far board's contact
    at the same number in the other row and asserts that what arrives is the
    input that wants it.  This is what makes radio-to-radio work, and it is
    asserted rather than believed.

 4. THE FUNCTION MIRRORING, as a contract rather than a hope.  For every lane
    the net this board drives and the net it receives at the same position
    must be functional counterparts: forward clock faces reverse clock, ADC
    data k faces transmit data k, aux clock faces aux clock, aux data faces
    aux data, and the duplicate forward clock faces a receiver rather than
    nothing.

 5. NO JTAG PATH BETWEEN TWO RADIOS.  The sideband positions whose far-end
    inputs are TCK and TMS must have NOTHING on this board driving their
    outputs, so one radio physically cannot clock or steer another radio's
    JTAG state machine whatever the enable does.

 6. EVERY REMOTE-DRIVE FEATURE IS OFF UNTIL SOMETHING TURNS IT ON.  Both
    enable nets are active LOW and must carry a pull-UP at both ends of their
    translator - one to the 2.5 V rail on the HL2 side, one to 3.3 V on the
    logic side - and no fitted pull-down anywhere.  That is the whole safety
    argument for an unprogrammed board, and it replaces rev C's strap,
    inverter and contention proof.

 7. EVERY CONDUCTOR THAT LEAVES THE BOARD IS CLAMPED.  Each of the 32 pair
    conductors and each wired sideband conductor must appear on an ESD array.

 8. NOTHING CALLS ITSELF BOARD A OR BOARD B.  One design with two ends on
    one panel: the radio end (J1) and the Gowin end (J101).

 9. THE GOWIN END'S PIN MAP.  Every contact of J101 and every position of
    J102, the 2x18 on Tang dock J14 positions 5-40, against PINMAP.md
    section 11; both forwarded clocks on dedicated clock balls; every P leg
    on a Gowin true (A) ball; nothing on J14 positions 1-4.

10. THE CROSSOVER IN ALL THREE COMBINATIONS - radio to Gowin, Gowin to radio
    and radio to radio - every output walked through the cable to the input
    at the far end, lanes and sidebands.

11. THE TWO ENDS SHARE NO NET.

12. AN ABSENT FAR END CANNOT KEY THE TRANSMITTER.  With the far end's
    connector pins treated as unconnected, every one of the four AUXIO lines
    - CW/PTT ring and tip (active LOW, keyed when low) and the I2C SCL/SDA
    bus to the radio's clock generator (idle HIGH) - is biased on the radio
    end itself to its safe HIGH level, can only pass that level through the
    drive buffer, and the drive buffer is tri-stated unless a powered far end
    asserts presence.  Walked for radio-to-Gowin, Gowin-to-radio and
    radio-to-radio.

13. EVERY TRANSLATOR AND BUFFER RUNS THE WAY PINMAP.md SAYS.  For every
    SN74AVC4T245 (and any SN74AVC8T245) the direction and enable of each port
    are DERIVED from its DIR and OE* nets and TI's truth table, and every
    channel's input and output net is compared with PINMAP.md section 12; the
    DS90LV047A and DS90LV048A enables likewise.  rev D as first built had U8
    and U10 port 1 wired backwards and nothing noticed.

14. THE SAFE STATE.  The board's logic is evaluated for all sixteen
    combinations of forward clock on/off, far end present/absent and FPGA
    pins 72 and 80 HIGH/LOW.  Whenever the clock is off (stock gateware, no
    gateware) or no far end is present (far end absent, cable unplugged),
    nothing on the board may drive a radio FPGA pin, the JTAG buffers and the
    AUXIO drive must be off, and with no far end every cable-facing buffer
    and both LVDS drivers must be off.  With the clock on, a far end present
    and the enables asserted, all of it must come on.

15. THE PRESENCE GATING in all three pairings: the radio end's drivers
    follow B8; a radio far end asserts A8 only while powered, a Gowin far end
    only while its gateware drives it; the Gowin end reads presence through
    10 k.

The tables below are retyped here from PINMAP.md and from the specifications
rather than imported from the generator, so the two can disagree and be
caught.
"""

import os
import subprocess
import sys

HERE = os.path.dirname(os.path.abspath(__file__))
ROOT = os.path.dirname(HERE)
sys.path.insert(0, HERE)
import kisexp as K

BOARD = 'bridge'

KICAD_CLI_CANDIDATES = [
    os.environ.get('KICAD_CLI', ''),
    r'C:/Users/franz/AppData/Local/Programs/KiCad/10.0/bin/kicad-cli.exe',
    r'C:/Program Files/KiCad/10.0/bin/kicad-cli.exe',
    r'C:/Program Files/KiCad/9.0/bin/kicad-cli.exe',
    'kicad-cli',
]

# --------------------------------------------------------------------------
# The header pin maps, retyped from PINMAP.md rev D.  These are the contract
# with the FPGA gateware, so they get asserted rather than trusted.
# --------------------------------------------------------------------------
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

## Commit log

2026-09-12 gowin-bridge: authoritative pin map for the HL2 <-> Tang Mega 138K DVI bridge boards
    Two adapter PCBs, one DVI-D dual-link cable per direction.
    Cable 1 "FWD" HL2 -> Gowin: TMDS clock = 76.8 MHz from HL2 PIN_98 (DB1-9);
    TMDS data 0..5 = HL2 PIN_72/76/77/80/83/85 (DB1 1..6). DDC SCL = status UART
    from PIN_86 (DB12-1), DDC SDA = aux slow line from PIN_87 (DB12-2), HPD =
    cable detect.
    Cable 2 "REV" Gowin -> HL2: TMDS clock = 153.6 MHz reverse clock into PIN_88
    (DB12-5); TMDS data 0..2 = REV0..2 into PIN_99/100/101 (DB1 11/15/17); TMDS
    data 3 = framed fast serial into PIN_89 (DB12-6); TMDS data 4/5 spare. DDC SDA
    = optional slow command UART, link-selected onto the same PIN_89.
    Tang dock J14 (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
2026-09-12 gowin-bridge: netlist-driven generator plus first generated KiCad projects (WIP)
    Both boards are generated from one netlist description so that schematic, PCB
    and BOM cannot drift apart. tools/kisexp.py lifts symbol graphics and
    footprint land patterns out of the stock KiCad libraries and re-emits them as
    project-local libraries in conservative KiCad 7/8 syntax, so each project is
    self-contained.
    Verified pinouts: DS90LV047A from TI SNLS044D and DS90LV048A from TI SNLS045C
    pin-function tables (both custom symbols, not in the stock libraries).
    SN74AVC4T245PW, TPD4E05U06DQA, ME6211C25M5G, AMS1117-3.3, DVI-D dual link and
    the 2.54 mm sockets all come from the stock libraries.
    The schematics d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
    [hl2-bridge-bom.csv, hl2-bridge.kicad_pcb, hl2-bridge.kicad_sch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]
2026-09-12 gowin-bridge: both schematics load and pass ERC with zero errors
    Fixes: sub-symbol names inside lib_symbols carry no library prefix; Value
    property matches the project library copy; symbol origins snapped to the
    1.27 mm connection grid; no-connect markers sit directly on unconnected-type
    pins instead of on a stub wire; power flags only on rails that no regulator
    already drives; the spare translator channel input is pulled low through a
    resistor rather than tied straight to a power-output pin.
    Validated with kicad-cli 10.0.6:
    hl2-bridge ERC 0 errors, PCB/schematic parity 0 issues, 118 parts, 86 nets
    tang-bridge ERC 0 errors, PCB/schematic parity 0 issues, 118 parts, 79 nets
    The remaini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
    [hl2-bridge-bom.csv, hl2-bridge.kicad_pcb, hl2-bridge.kicad_sch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]
2026-09-12 gowin-bridge: STATUS.md and README.md (EasyEDA Pro import, DRC rules, ordering, jumpers, two-radio use case)
    README covers: what the user solders on the HL2 and on the Tang dock; the two
    use cases (HL2 to Gowin, and two HL2 radios back to back with the cables
    crossed OUT-to-IN); the exact EasyEDA Pro import route (File > Import > KiCad,
    then Design > Update PCB); the 4-layer stackup and the DRC and differential
    pair rules to set there; the Gerber/BOM/CPL export and which JLCPCB assembly
    service to pick; and the full jumper and solder-link table.
    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
2026-09-12 gowin-bridge: DESIGN_NOTES.md - signal integrity, level shifting, power, mechanics
    Covers the rates and unit intervals, where the termination goes, the one tight
    single-ended path (307.2 Mbit/s into the HL2's LED pins, 51 percent of the unit
    interval for the edge), all four level-shift cases with the datasheet numbers
    including why a resistor divider cannot serve the two input-only 2.5 V pins and
    a SN74AVC4T245 translator can, the power budget for both boards, grounding, the
    exact DB1 and DB12 coordinates with the KiCad rotation cross-check, the 50 mm
    corridor the N2ADR filter board leaves, the height stack-up, a proof that two
    right-angle dual-link DVI sockets cannot be brought out of the s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
2026-09-12 gowin-bridge: board A sockets land exactly on the HL2 DB1/DB12 hole grid
    KiCad does not mirror pad coordinates for a bottom-layer footprint - proved by
    exporting the Excellon drill file and comparing hole positions against the
    footprint's local pad coordinates. A socket that has to mate a male header seen
    from above therefore has to be mirrored in x by the generator, which is now
    done for both bottom-side sockets.
    Verified from the drill export: DB1 holes at board-local x 3.54 and 6.08, y
    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
    [hl2-bridge.kicad_pcb, tang-bridge.kicad_pcb]
2026-09-12 gowin-bridge: PINMAP.md rev B - three HDMI sockets per board, symmetric OUT/IN roles
    Replaces the rev A two-DVI pin map.
    - Role belongs to the socket, not to pins inside it: exactly two socket
    definitions (OUT drives all four pairs and the slow wire, IN receives them)
    with identical pair ordering, so a straight mini-to-mini cable joins any OUT
    to any IN. Board A = 2 OUT + 1 IN, board B = 2 IN + 1 OUT.
    - Two forward clocks: PIN_98 in OUT 1 and PIN_87 in OUT 2 (a second copy of the
    same 76.8 MHz), making each forward cable self-timed. The rev A "aux out" on
    PIN_87 is gone.
    - All 14 usable HL2 pins are now committed: 9 out, 5 in, none spare.
    - Tang J14: 16 signal pins, forward clock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
2026-09-12 gowin-bridge: regenerate both boards for three HDMI sockets per board
    Generator rewritten around PINMAP.md rev B. Both projects load in KiCad 10,
    ERC 0 violations, schematic/PCB parity 0 issues, and a new independent
    geometry checker passes on both.
    Connectors, both real LCSC parts with datasheet land patterns:
    - board A: 3 x XKB A71-05H4-111N1 mini HDMI Type C, LCSC C2682170, hybrid
    mount (19 SMT contacts on 0.40 mm pitch, 4 through-hole shell legs in
    plated slots, 2 locating pegs). Footprint generated from the manufacturer's
    recommended layout, which is the only mini HDMI drawing found that
    dimensions the pattern relative to the PCB edge.
    - board B: 3 x Amphenol ICC 10029449-111RL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
    [hl2-bridge-bom.csv, hl2-bridge.kicad_pcb, hl2-bridge.kicad_sch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]
2026-09-12 gowin-bridge: ROUTING.md plus rev B design notes, README and status
    ROUTING.md is new, and is the document the brief asked for: how to route
    these two specific boards in EasyEDA Pro, for someone competent but not a
    high-speed specialist. It covers the import, the JLCPCB stackup, the 100 ohm
    trace geometry with the calculation behind it (0.25 mm / 0.20 mm on the
    0.2104 mm 7628 prepreg = 98.5 ohm, confirm against the quoted stackup), the
    routing order, both connector fan-outs in detail, length matching, via and
    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
    [hl2-bridge.kicad_pcb, hl2-bridge.kicad_sch, tang-bridge.kicad_pcb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]
2026-09-12 gowin-bridge: add tools/check_netlist.py - proves the OUT-to-IN symmetry
    The symmetry requirement is the thing most worth testing, because nothing in
    ERC or DRC can see it: every socket has the right nets on the right pins, and
    they are all wrong in the same way if the HDMI pin table is wrong.
    check_netlist.py exports both netlists with kicad-cli and asserts:
    - the HL2 DB1 and DB12 header pins carry exactly the nets PINMAP.md says,
    with the FPGA pin number named for each - this is the contract with the
    gateware, and it is where rev A's DB12 pin 5/6 swap would have been caught;
    - the Tang J14 pins likewise, plus that every J14 pin the design does not use
    is electrically open, so PMOD0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
    [check_netlist.py]
2026-09-12 gowin-bridge: generator prunes stale footprints from the project libraries
    Board A no longer has mounting holes, but its project footprint library still
    carried MountingHole_3.2mm_M3_Pad from the previous generation. write_libs now
    deletes any .kicad_mod the board does not use, so dropping a part cannot leave
    a land pattern behind for someone to place by accident.
2026-09-12 gowin-bridge: net class geometry now matches the routing document
    The LVDS100 net class still carried 0.20 mm / 0.13 mm from rev A, while
    ROUTING.md section 1.2 recommends 0.25 mm / 0.20 mm for 98.5 ohm on the
    JLCPCB 4-layer 1.6 mm stackup. The project files would have imported the
    wrong geometry into EasyEDA Pro and the user would have routed to it.
    Both are ~100 ohm on that stackup; 0.20/0.13 was rejected because a 0.13 mm
    gap sits on JLCPCB's 0.127 mm minimum, so the etch tolerance is 15 % of the
    gap and the impedance swings with it. ROUTING.md says so; now the files
    agree. A second differential preset of 0.15 mm / 0.17 mm is added for the
    0.40 mm-pitch connector fan-out neck.
    Co-Author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
2026-09-12 WIP rev C paused: record the analysis, and six BOM defects a price check found
    NOTHING IN THE DESIGN CHANGED. The boards and PINMAP.md in this tree are
    still rev B and still self-consistent: both checkers pass, ERC is 0 and
    schematic/PCB parity is 0. This commit is documentation only.
    Rev C (every lane 307.2 Mbit/s in both directions, plus a third socket
    carrying a fast bidirectional control channel) was specified and analysed but
    deliberately NOT implemented, because the requirement changed mid-analysis:
    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
2026-09-12 WIP: every BOM defect now has a resolution, and the cost totals
    Still documentation only. Nothing in the design changed; both checkers pass.
    The blocking item turned out to be trivial: the quad LVDS driver is the SAME
    TI silicon with the SAME pinout under a different LCSC catalogue number.
    C201946 (zero stock) becomes C206491 (DS90LV047ATMX/NOPB, 1,312 in stock, and
    in JLCPCB's library). Nothing to redraw - symbol, footprint and every pin
    assignment stay as they are; only the BOM line number changes.
    Also resolved: SN74AVC8T245PWR is C465742 and confirmed TSSOP-24; the 2x20
    socket becomes C5124634 (11,945 in stock, in JLCPCB's library); the 2x10
    becomes C42431860; and the odd resistor valu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
2026-09-12 gowin-bridge: PINMAP.md rev C - symmetric lanes both ways, strap-selected AUX socket
    Committed alone and first, because the FPGA side needs it before anything
    else. The boards still implement rev B; regenerating them is the next step.
    Allocation:
    - Every lane is now DDR at 153.6 MHz = 307.2 Mbit/s in BOTH directions, three
    lanes each way, 921.6 Mbit/s each way. The forward link therefore moves onto
    the 3-lane geometry LINK_SPEC.md has already simulated, instead of the
    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
2026-09-12 gowin-bridge: regenerate both boards for rev C
    Three HDMI sockets per board with rev C roles - OUT, AUX, IN, with the two
    fixed-direction sockets on the OUTSIDE so the two-radio case never has three
    cable boots side by side. Every lane is now DDR at 153.6 MHz = 307.2 Mbit/s
    in both directions.
    New in rev C:
    * The ROLE strap: one 1x3 header with ONE shunt plus one single-gate
    inverter (SN74LVC1G04DBVR, LCSC C7827, SOT-23-5, verified in stock and in
    JLCPCB's library as an Extended part). ROLE_N carries a 10k pull-UP so a
    missing or dead inverter disables a host-facing port rather than enabling
    one, and ROLE carries a 100k pull-down so "no shunt" is a defined state.
    * Board A goes f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
    [hl2-bridge-bom.csv, hl2-bridge.kicad_pcb, hl2-bridge.kicad_sch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]
2026-09-12 gowin-bridge: add the panel project, and extend both checkers for it
    A third KiCad project, panel/, generated from the same part lists as the two
    individual boards and therefore unable to drift from them. Both individual
    projects are kept.
    94.00 x 100.00 mm, two designs. Board A at (0, 29); board B rotated +90 with
    its origin at (48, 95), so its local x runs down the panel and its local y
    runs across it and its socket edge lands on the outer panel edge x = 94. A
    48 x 22 mm fiducial coupon at the bottom left, 5 mm assembly rails on the y
    axis.
    Three V-scores - y = 5, y = 95, x = 48 - each straight, edge to edge, and
    with material on both sides for its whole length; the checker now proves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
    [panel-bom.csv, panel.kicad_pcb, panel.kicad_sch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]
2026-09-12 gowin-bridge: the 10 uF bulk cap was the wrong package, and the wrong voltage
    C15525 was in the BOM as "10uF 0805". Checked against LCSC's own page it is
    Samsung CL05A106MQ5NUNC, 10 uF 6.3 V X5R in 0402 - the wrong package for the
    0805 pads it was assigned, and 6.3 V would have lost most of its capacitance
    to DC bias on the two 5 V input bulk positions.
    Replaced by C15850, Samsung CL21A106KAYNNNE, 10 uF 25 V X5R 0805, confirmed
    Basic in JLCPCB's library, 2,760,420 in stock, $0.085 at its minimum order
    quantity of 20.
    Five 10 uF positions per set: +3V3 bulk and the two optional-LDO bulks on
    board A, and 5 V input bulk plus LDO output bulk on board B.
    All three projects still pass ERC, DRC,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
    [hl2-bridge-bom.csv, hl2-bridge.kicad_sch, panel-bom.csv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]
2026-09-12 gowin-bridge: rev C documents, and three more BOM numbers that were wrong
    README.md rewritten for rev C: the three usage configurations (HL2 to Gowin
    with three cables; two radios with two cables, each sending the other its
    complete 921.6 Mbit/s raw ADC stream on the two outer sockets; two radios with
    three cables, which is the only case that needs a strap moved), which cables
    to buy, the ROLE strap and every other jumper, the two sockets the user buys
    and solders himself with their suppliers and prices, the ordering steps
    including that "Different designs in this file" must be set to 2, and the
    two-separate-orders fallback at roughly $40 more if the fab queries the panel.
    Full costing for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
    [hl2-bridge-bom.csv, hl2-bridge.kicad_sch, panel-bom.csv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]
2026-09-12 gowin-bridge: DESIGN_NOTES.md for rev C, and regenerated templates
    New section 2, "The ROLE strap, and its failure analysis": the circuit, why
    one shunt plus one inverter beats a double-pole jumper (a two-shunt changeover
    allows "both levels low", which enables a host-facing port while the gateware
    drives those same pins as outputs), the driver-EN-equals-buffer-OE invariant
    stated so a checker can assert it, why LVDS driver against LVDS driver is
    harmless (a current source of about 3.5 mA with an internally limited
    short-circuit current, so the data is garbled and nothing is stressed), why
    the CMOS case is prevented, a case-by-case failure table, the buffer chip
    board B needed and the first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
2026-09-12 gowin-bridge: COST.md - the rev B to rev C cost rise, taken apart
    Answers a direct challenge: rev B was quoted at about $150 for two sets, rev C
    at $199.70, and panelising was supposed to make it cheaper.
    THE FINDING. The apparent rise is $49.88, of which $29.49 is rev B's own
    figure understating rev B's own design. rev B never counted the per-joint
    placement fees, the $3.58-per-order hand-soldering base fee, or the second
    shipment two separate orders need; and its BOM contained three LCSC numbers
    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
2026-09-12 gowin-bridge: strap inverter becomes a Basic-tier MOSFET; the bare-PCB question is settled
    TWO CHANGES, one electrical and one to the costing.
    1. THE STRAP INVERTER IS NOW ONE N-CHANNEL MOSFET, not a logic gate.
    AO3400A, LCSC C20917, SOT-23, JLCPCB BASIC tier, ~890,000 in stock, ~$0.08,
    Vgs(th) 1.45 V MAXIMUM so a 3.3 V strap drives it with 1.85 V of margin.
    Gate on ROLE, source to ground, drain on ROLE_N, loaded by the 10 k pull-up
    that was already fitted. The 2N7002 was rejected: its threshold is
    specified up to 2.5 V, too close to a 3.3 V drive.
    Why: no 74x1G04, 1G00, 1G02, 1G14 or 1G07 of any brand, family or package
    is a Basic part in JLCPCB's library, across all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
    [hl2-bridge-bom.csv, hl2-bridge.kicad_pcb, hl2-bridge.kicad_sch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]
2026-09-12 gowin-bridge: four Extended part numbers eliminated, 11 down to 7
    Cost reduction only. No function changes: every signal, every net role and
    every strap behaviour is identical.
    1. THE SEVEN PIN HEADERS AND THE TANG 2x20 SOCKET ARE NOW HAND-FITTED.
    Footprints kept, marked do-not-place, LCSC field emptied so the assembly
    BOM does not carry them. Three distinct part numbers leave the order -
    1x3 header, 1x2 header, 2x20 socket - and no Basic 2.54 mm through-hole
    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
    [hl2-bridge-bom.csv, hl2-bridge.kicad_pcb, hl2-bridge.kicad_sch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]
2026-09-13 gowin-bridge: add the SlimSAS end-panel cutout
    New hardware/companions/gowin-bridge/panel-endcap/, built on
    hardware/enclosure/endcaps/kf7o/hl2_55f/endcap.kicad_pcb (the best-verified
    of the five existing front-panel designs). Adds one 24.00 x 10.40mm opening,
    1mm corner fillets, for the SlimSAS SFF-8654 8i socket on the DB1/DB12
    companion board, at panel x 88.65-112.65 / y 74.91-85.31 (HL2 y 75.65-99.65,
    height 12.39-22.79mm above the HL2 board top). No other feature on the
    source file moved. Validated with kicad-cli pcb drc: 0 new violations.
    Full derivation, clearance checks, the 55N strength recalculation and the
    JLCPCB manufacturability question are in
    franz-claude-analysis/HL2_END_PAN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
    [panel-endcap.kicad_pcb]
2026-09-13 gowin-bridge rev D: one design, one SlimSAS cable, one board at both ends
    Replaces rev C's two designs, three mini-HDMI cables, upright riser card and
    V-scored production panel with ONE flat board carrying ONE SlimSAS SFF-8654 8i
    receptacle. Two copies and one $15 cable make a radio-to-radio link.
    WHY ONE DESIGN WORKS AT BOTH ENDS. SFF-9402 Rev 1.1 implementation note 16 and
    its Tables 6-2/6-3 define the 8i-to-8i cable as a full crossover: contact A(n)
    at one end reaches B(n) at the other, all 37 positions, sidebands included. So
    the board drives row A and listens on row B, and the row assignments are
    function-mirrored - forward clock faces reverse clock, ADC data 0/1/2 face
    transmit data 0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
    [bridge-bom.csv, bridge.kicad_pcb, bridge.kicad_sch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]
2026-09-13 panel-tang-40mm: front and rear end panels for a Tang Mega 138K dock in the HL2 40 mm case
    Front: SlimSAS 8i plug window, dock USB3-C, dock RJ45 (RJ45 height estimated).
    Rear: panel DC jack, USB-C debug extension, optional power switch, vent.
    Outline and M3 holes from kf7o hl2_40f/hl2_40b. Derivation in
    franz-claude-analysis/TANG_IN_40MM_CASE.md.
    [tang40_front.kicad_pcb, tang40_rear.kicad_pcb]
2026-09-13 gowin-bridge rev D: add the Gowin end to the same design, panel and order
    The Tang Mega 138K end of the SlimSAS link now lives in the same schematic,
    PCB and BOM as the radio end, on one 64.50 x 100.07 mm panel snapped apart
    along three V-scores.
    The Gowin end is passive. Tang dock J14 is FPGA Bank 4 at 3.3 V (dock
    schematic sheet 2/21); Gowin DS1239 Table 2-1 and Table 3-10 allow true LVDS
    output at 3.3 V, Table 2-2 allows LVDS input, UG1102 Table 2-3 makes all 143
    PG484A pairs true-LVDS capable and UG304 3.3.2 gives on-die 100 ohm
    termination. Gowin EDA 1.9.11.03 placed and routed the final pin map without
    error. Parts: the same SlimSAS connector and ESD array as the radio end and
    nine Ba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
    [bridge-bom.csv, bridge.kicad_pcb, bridge.kicad_sch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]
2026-09-13 gowin-bridge rev D: one board, 100 mm, and an absent far end cannot key the radio
    One board, one design:
    - Confirmed and now asserted: the PCB has ONE continuous Edge.Cuts outline
    round both ends and both rails, joined only across V-scores.
    check_geometry.py fails if there is more than one outer loop.
    - 64.50 x 100.07 -> 64.50 x 100.00 mm. The radio end's edge facing the Gowin
    end moves in 0.07 mm (HL2 y 73.30 -> 73.37); no part, hole or socket moves,
    rails stay 5 mm.
    - All two-design ordering, panel charges and the multiple-design assembly fee
    removed. Live JLCPCB quote, 4 layer, 64.5 x 100 mm, 5 pcs, one design,
    lead-free HASL: $12.10. Order $154.84, per link $30.97, Gowin half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
    [bridge-bom.csv, bridge.kicad_pcb, bridge.kicad_sch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]
2026-09-13 panel-endcap: move SlimSAS opening to the corrected rev D position
    The rev D electrical session on the companion board (commit d390bca) found
    the SlimSAS receptacle cannot sit in front of DB1 as the earlier draft of
    this panel assumed - its shell tails and contact pads land on DB1's and
    DB12's through-hole fields no matter how it is placed there - and moved the
    connector 31.65 mm sideways along the front edge, past the far end of DB1.
    This moves the panel opening to match: panel x 120.30-144.30 (was
    88.65-112.65), same 24.00 x 10.40 mm size and same 12.39-22.79 mm height
    above the HL2 board top. The new centre (HL2 y 119.30) is derived
    independently from the bridge board's own SlimSAS footp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
    [panel-endcap.kicad_pcb]
2026-09-13 gowin-bridge: add strictly procedural EasyEDA Pro routing + JLCPCB order guide
    ROUTING.md was written for KiCad and the owner routes by hand in EasyEDA Pro.
    Add ROUTING_EASYEDA.md: numbered steps for the KiCad import, the JLCPCB
    JLC04161H-7628 stack with real dielectric figures, a 100 Ω differential
    target computed live on JLCPCB's impedance calculator (0.25 mm/0.20 mm,
    top layer only referenced to the solid ground plane, since the bottom
    layer's only reference is the split power plane), the full 32-leg pair
    table for both ends with derived length-match tolerances, expanded route
    order for the previously under-documented Gowin end, power/ground plane
    steps, mechanical keepouts, pre-order ch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
2026-09-13 gowin-bridge rev D: prepare the board for Quilter placement and routing
    - Only the mechanically fixed parts stay on the board, locked: J1-J5,
    J101, J102, FID1-FID3 and the MH6 hole. The other 142 parts are staged
    off the board, grouped by placement region, for Quilter to place.
    - Five top-side placement regions (ESD strips at both connectors, the
    HL2 header block, one per end) and ten keepouts (score copper, J5 IDC
    access, J14 positions 1-4, under-board height zones) as KiCad rule areas.
    - Test points 73 -> 10; spare outputs that ended on pads get no-connects.
    check_netlist.py passes, fail-safe in all three pairings.
    - Every note, dimension and drawing off the board; one name line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
    [bridge-bom.csv, bridge.kicad_pcb, bridge.kicad_sch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]
2026-09-13 gowin-bridge rev D: holes over the radio, mouse-bite tabs, wider jumper window
    Three approved outline changes; no net, pin, schematic symbol or locked part
    moved.
    - Holes through the radio end over the HL2 FPGA (26.20 x 26.20 mm, a notch
    open to the top edge), AD9866 (13.00 x 13.00 mm) and T2 (10.62 x 11.25 mm),
    each the package outline from hermeslite.kicad_pcb plus 1.5 mm a side,
    R1.0 corners, 1 mm keep-back for Quilter. AD9866, T2 and the jumper window
    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
    [bridge.kicad_pcb]
2026-09-13 gowin-bridge rev D: risk-review fixes (buffers, stock-gateware safety, presence, noise, DB3)
    Owner-approved fixes from the 13 Sep 2026 risk review.
    - Two buffers were wired backwards. U8 (AUXIO read) had DIR on GND, i.e.
    B->A: it drove the radio CW key, PTT and clock-chip I2C pins from the
    cable, always on. U10 port 1 did the same to the FPGA TDO pin. Both now
    run radio -> cable, enabled only with a far end present; 10k pull-up on
    J_TDO_T.
    - Link-alive detector: U11 port 2 buffers the forward clock into a 10 pF /
    2x RB751V-40 / 10 nF / 100k doubler. LINK_ALIVE gates U3 OE*, U6/U7 EN*
    (Q2), the JTAG enable (Q3) and the AUXIO enable (Q4); Q6 clamps it with no
    far end. With stock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
    [bridge-bom.csv, bridge.kicad_pcb, bridge.kicad_sch]
2026-09-13 panel-endcap rev C: restore the nine vent holes above the SlimSAS opening
    Nine 1.4 mm holes on the stock 2.5 mm pitch, as a 3x3 block at panel
    x 130.5-135.5, y 56.7-61.7, added to the speakervent footprint. 27 holes,
    73.7 mm2 of vent area, the stock figure. 12.5 mm to the opening, 3.6 mm to
    the nearest stock hole, 6.0 mm to the panel edge. Short-span strength margin
    unchanged at 3.9x. DRC: the same single expected library-mismatch note.
    [panel-endcap.kicad_pcb]
